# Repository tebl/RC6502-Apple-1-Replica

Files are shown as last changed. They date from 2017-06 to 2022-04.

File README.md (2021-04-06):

# RC6502 Apple 1 Replica

Since building and spending time with the excellent [RC2014](http://rc2014.co.uk) computer kit, I wanted to build another one from scratch while learning even more about them along the way. Combine that with the love of old machines I'll never be able to own, and the missing knowledge to actually do that I instead started looking for books on how things work on a more basic level.

Seems someone, Tow Owad ofcourse, wrote a book on called "Apple 1 Replica Creation, Back to the garage" on how to build an Apple 1 computer from scratch and made it freely available on [http://www.applefritter.com/](http://www.applefritter.com/). Couldn't possibly find a more perfect match, so thank you for that Tom! Only thing missing was the PCBs, so with that in mind I set about designing them in KiCAD. Before long, the RC6502 Apple 1 Replica was born.

I started designing each function as a separate module for ease of debugging, later all this was concentrated down into a computer on a single PCB. A so called Single Board Computer (SBC) to call my own, but with the ability to connect it up to a backplane of your choice (either my own, or you can use the RC2014 one) so that extra functionality can be plugged in and added as you please. The fun part is designing additions for it, so check out the various modules if there's something you'd like to add to it.

I've been documenting the build process of the various components on my blog at [https://hvetebolle.blogspot.no/p/rc6502.html](https://hvetebolle.blogspot.no/p/rc6502.html), but be warned that it's in my native language (Norwegian) so this might not be anywhere close to readable for most people. For those of you relying on English as a language, and don't want to try out Google Translate, the essence of it is that it all amounts to a fully functional Apple 1 replica computer built with the cheapest parts possible!

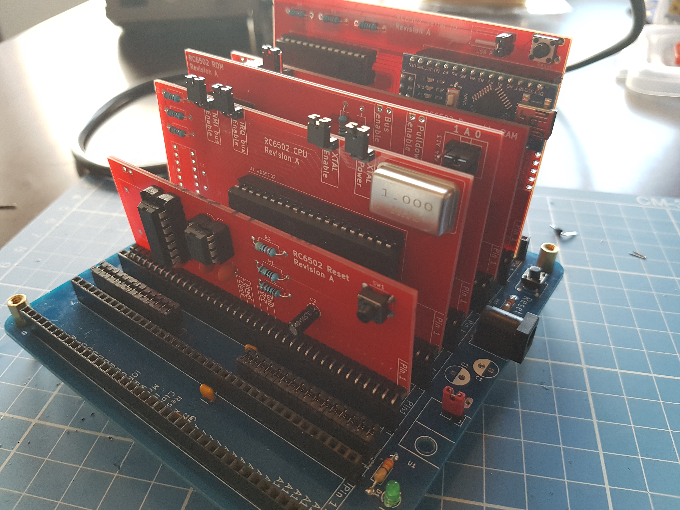
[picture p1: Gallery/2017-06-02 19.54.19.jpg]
RC6502 Computer

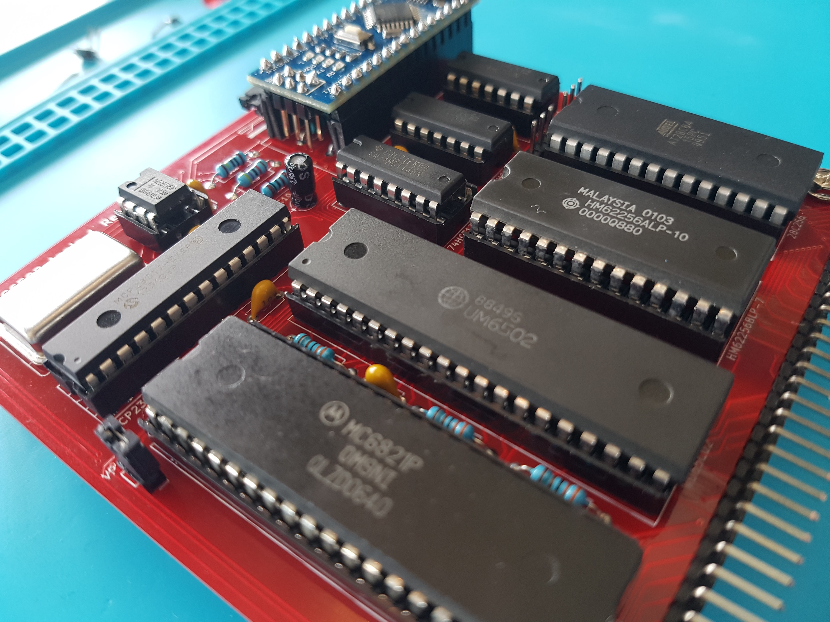
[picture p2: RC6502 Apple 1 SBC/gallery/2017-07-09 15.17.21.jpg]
RC6502 SBC Computer


## Modules
Like the RC2014 I've decided to keep things very modular with each card more or less doing one simple thing, easier to wrap ones head around as a beginner and a lot easier to understand when troubleshooting - also a lot cheaper to upgrade or replace since you don't actually need to replace the entire thing, just the specific board. With the conversion of the RC6502 computer to a SBC-version (Single Board Computer), you now have the option to build an all in one version on a single PCB - alternatively you can build the completely full-sized version as before if you want to! Most can be accomplished with the SBC version so to start things off, I recommend getting PCBs of the SBC ([order](https://www.pcbway.com/project/shareproject/RC6502_Apple_1_SBC__revision_D_.html?inviteid=88707)) as well as the backplane ([order](https://www.pcbway.com/project/shareproject/RC6502_Apple_1_Replica__Backplane_module_revision_A_.html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)).

The full-sized system uses a 39-pin bus described in [`Bus.md`](Bus.md). The SBC supports the same bus, allowing you to use expansion cards with it; jumpers on the SBC allow you to disable any of the RAM, ROM, PIA and clock so that their functionality can be replaced by peripheral cards on the bus.

In order to build a single board computer (SBC) of RC6502 you'll need the following modules:
- [RC6502 SBC](https://github.com/tebl/RC6502/tree/master/RC6502%20Apple%201%20SBC) ([order](https://www.pcbway.com/project/shareproject/RC6502_Apple_1_SBC__revision_H_.html?inviteid=88707))

In order to build the complete full-sized RC6502 you'll need the following modules:
- [Backplane](https://github.com/tebl/RC6502-Apple-1-Replica/tree/master/RC6502%20Backplane) ([order](https://www.pcbway.com/project/shareproject/RC6502_Apple_1_Replica__Backplane_module_revision_A_.html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))
- [CPU](https://github.com/tebl/RC6502/tree/master/RC6502%20CPU)
- [RAM](https://github.com/tebl/RC6502/tree/master/RC6502%20RAM)
- [ROM](https://github.com/tebl/RC6502/tree/master/RC6502%20ROM)
- [Reset Circuit](https://github.com/tebl/RC6502/tree/master/RC6502%20Reset%20Circuit)
- [Serial IO](https://github.com/tebl/RC6502/tree/master/RC6502%20Serial%20IO)

Optional modules:
- [Backplane](https://github.com/tebl/RC6502-Apple-1-Replica/tree/master/RC6502%20Backplane) ([order](https://www.pcbway.com/project/shareproject/RC6502_Apple_1_Replica__Backplane_module_revision_A_.html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))
- [Prototyping module](https://github.com/tebl/RC6502-Apple-1-Replica/tree/master/RC6502%20Prototyping) ([order](https://www.pcbway.com/project/shareproject/RC6502_Apple_1_Replica__Module_prototyping_board_.html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))
- [Digital I/O and joystick](https://github.com/tebl/RC6502-Apple-1-Replica/tree/master/RC6502%20Joystick) ([order](https://www.pcbway.com/project/shareproject/RC6502_Apple_1_Replica__Joystick_module_revision_A_.html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))
- [RIOT 2600 (Atari 2600 RAM and digital I/O)](https://github.com/tebl/RC6502-Apple-1-Replica/tree/master/RC6502%20RIOT) ([order](https://www.pcbway.com/project/shareproject/RC6502_Apple_1_Replica__RIOT_2600_revision_A_.html?inviteid=88707))
- [VDU](https://github.com/tebl/RC6502-Apple-1-Replica/tree/master/RC6502%20VDU) ([order](https://www.pcbway.com/project/shareproject/RC6502_Apple_1_Replica__VDU_module_revision_B_.html?inviteid=88707))
- [VDU B/W Amplifier](https://github.com/tebl/RC6502-Apple-1-Replica/tree/master/RC6502%20VDU%20Amplifier) ([order](https://www.pcbway.com/project/shareproject/RC6502_Apple_1_Replica__VDU_B_W_Amplifier_revision_A_.html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))
- [VDU Color Amplifier](https://github.com/tebl/RC6502-Apple-1-Replica/tree/master/RC6502%20VDU%20Color%20Amplifier) ([order](https://www.pcbway.com/project/shareproject/RC6502_Apple_1_Replica__VDU_Color_Amplifier_revision_A_.html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))

If you would like to have a copy of one or more modules, what you'll need to do is zip up the contents of the export directory for each module and give that to your favourite PCB fabrication plant. Personally I prefer to use [PCBWay](https://www.pcbway.com/setinvite.aspx?inviteid=88707), each module is only 5$ each and new accounts even get the first one free! Please use the supplied link when signing up to help me support this project, I'll get a small discount on future orders and hopefully I can afford to keep developing new and exciting modules. Some of the modules also have an order-link, using this you won't have to deal with the rather daunting PCB fabrication order forms so you know it'll work on the first order attempt!

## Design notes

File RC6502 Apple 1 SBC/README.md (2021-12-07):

# RC6502 Apple 1 SBC

Did you ever wonder what the first computer created by Apple was like, and then checked what getting one might cost? Well, only a few were made and those that still exist probably would cost you more than my car! Steve Wozniak built what would later be called the Apple I computer in his garage, using only common over the counter components the result was an interesting computer that still holds the imagination of many computer geeks to this day. I don't own a garage so I was limited by whatever I could do from the confines of my kitchen table, the RC6502 was what I came up with and with the files freely available on GitHub you can too!

There are two versions of the RC6502, one has a card for every basic function such as CPU, RAM (redesigned version of also supports ROM), separate ROM as well as a serial card that replaces the traditional CRT and ASCII keyboard with an Arduino Nano. Doing it this way requires a backplane to connect everything together, this may be the version to build either because you want to study each of them in detail to figure out their secrets or simply because you want the option to easily replace them. The other one, this one actually, is the SBC-version (Single Board Computer) - this is the version to get if you want to learn a bit about the computer and enjoy building kits that are in a more compact form factor. It looks nice on shelf, or in a small drawer (if you don't get a vote on what belongs on display in your home). Most can be accomplished with the SBC version, so for your first build I recommend that you start with the SBC ([order](https://www.pcbway.com/project/shareproject/RC6502_Apple_1_SBC__revision_D_.html?inviteid=88707)) as well as a backplane ([order](https://www.pcbway.com/project/shareproject/RC6502_Apple_1_Replica__Backplane_module_revision_A_.html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)) (so you can create and add features later).

Completed board

Excited yet? Of course you are. The next step is getting a PCB made; with the files available here you can have a company such as [PCBWay](https://www.pcbway.com/project/shareproject/RC6502_Apple_1_SBC__revision_D_.html?inviteid=88707) make a stack of them for around $5, then have a look through the BOM (Bill Of Manufacturing) below to figure out what kind of components you'd need later to put it all together. Other than that you need basic tools such as a good soldering iron with a small-ish tip, lead-based solder with a resin core is recommended for beginners and then finally you'll need a basic EEPROM programmer (I use a cheap, but fantastic one called MiniPro TL866A).

The project uses only through-hole components that are easy for beginners, these have a set of pins or wires that are threaded through the holes of the PCB and then soldered on to the backside of the PCB. You can assemble it in the order of your own choosing as long as everything goes in the right place, but here are some hints to get started: do smaller parts such as the resistors first, then followed by the capacitors, IC sockets and then finally the larger components. By doing it this way, we're gradually going from the components closest to the board and successively moving onto taller components - this makes it easier to keep everything flush with the board. The components icons on the top of the PCB, what we hardware geeks usually refer to as the silkscreen, shows you which components goes where - take care that they are oriented the correct way, where it matters it'll be marked. Sockets will have a little indent marked on it similar to what you find on the PCB, for the electrolytic capacitors (round towers) you'll be able to match a stripe on one of the sides to the filled half of the symbol (this is the minus side).

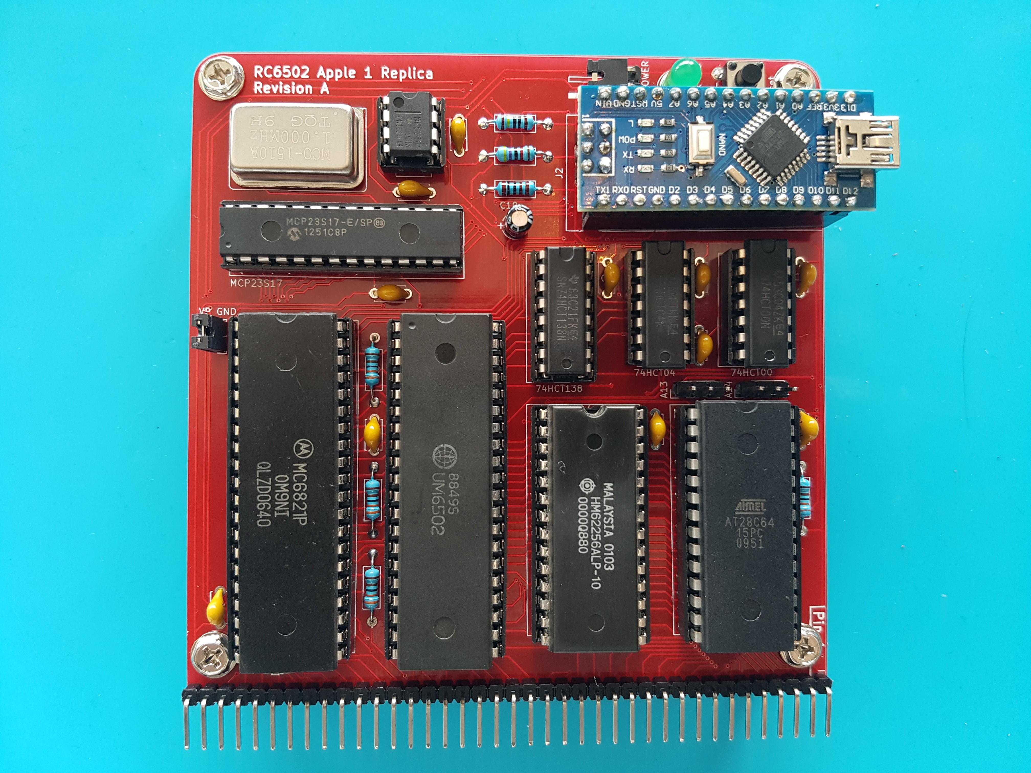
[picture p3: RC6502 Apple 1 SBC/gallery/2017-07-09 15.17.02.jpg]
Board overview


Take it slow and steady, enjoy the feeling of building a computer by hand. Study the text on the backside of the PCB as you go along, it'll have some text on it describing what most of the components you are installing actually does! If afterwards you want to study everything in detail, you can do so by studying the schematic for the whole thing at your leisure. Having problems with it? Now, I'm afraid you no longer have the option to avoid the schematic, but happily most problems can be fixed by verifying each connection by using a cheap multimeter set to continuity mode. If you print the schematic, you can mark everything you've checked with a pen so you won't overlook anything - this is where you'll be learning the most! Sometimes the wrong things have been accidentally connected, usually by a stray splash of solder - these are quickly found using the same continuity check, systematically work through each of the ICs to see if pins next to each other have been connected without a corresponding link on the schematic. Don't feel bad that everything didn't work from the get go, that just means you got some extra opportunities to learn even more than expected!

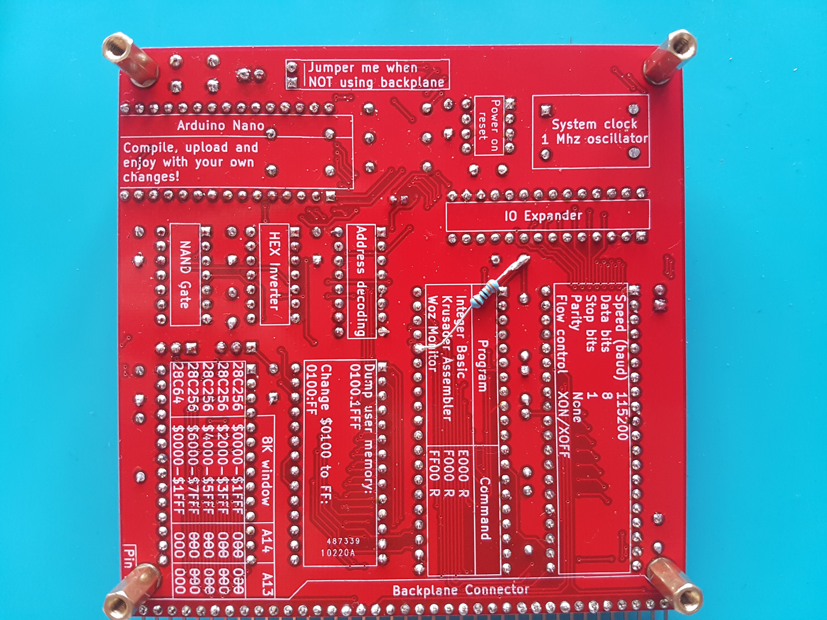
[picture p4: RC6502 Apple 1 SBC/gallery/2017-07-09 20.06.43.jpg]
Reverse side of board


The original computer had circuits for displaying data on a screen and reading input via a physical keyboard, but to keep things simple we are instead using an Arduino Nano to replace these parts - that way, you thankfully don't need to buy an antique keyboard or a scary CRT monitor in order to use it! You can communicate with the computer you built using a terminal emulator program such as PuTTy, SecureCRT or similar over the serial interface provided by the Arduino Nano. The Nano of course also need some software running on it, you'll find that in the form of an Arduino sketch called "[PIA Communicator](https://github.com/tebl/RC6502/tree/master/RC6502%20Serial%20IO/pia_communicator)", for more information see the details for the standalone [Serial IO](https://github.com/tebl/RC6502-Apple-1-Replica/tree/master/RC6502%20Serial%20IO)-module. 

The firmware that goes into the EEPROM hasn't been changed since Wozniak himself wrote it, but as long as you have the programmer handy you can easily flash it into place using the software that came with the programmer (MiniPro Programmer, if you bought the one I'm using). Today the [8 KB binary file](https://github.com/tebl/RC6502/tree/master/RC6502%20ROM/firmware) will seem really small, but even still it contains everything you'll need to get started and even a lot more. You've got a complete version of BASIC in there, but since it's an Apple 1 the first thing you'll see is something called a computer monitor - WozMon! The monitor allows you to interact with the system by peeking and poking memory locations to your hearts content!

At this point you'll certainly have learned a lot, after all you've actually built an entire computer! Thankfully you had some modern tools available, but please take a moment to contemplate the genius needed to build this thing back in 1976! Still wanting more, why not try your hand at designing some extra modules to use with that backplane connector? Add a parallel port, replace the display portion with a proper LCD, or you could even go as far as adding a few pretty blinking lights - the possibilities are truly endless (so long as it's within 64K)!

## Errata
Revisions D and E of the SBC was missing a line powering the CPU, this is fixed by adding a piece of patch wire or simply a piece of resistor leftovers. Refer to the image below to see where it should be added, but leave some room so that it doesn't short to the pads now in the middle of the wire.

Adding wire

# Schematic
The supplied KiCad files should be sufficient as both a schematic and as a starting point for ordering PCBs (basically you could just zip the contents of the export folder and upload that on a fabrication site), the schematic is also available in [PDF-format](https://github.com/tebl/RC6502/raw/master/RC6502%20Apple%201%20SBC/export/RC6502%20Apple%201%20SBC.pdf) so that you can refer to it while troubleshooting. You could even print it out and hang it on your office wall, excellent conversation starter at any technology-oriented business worth working at!

# BOM
This is the part list as it stands now, most should be easy to get a hold of from your local electronic component shop though you might have to consider other sources for the older parts such as CPU, memory and PIA. Personally I bought most components with free shipping from China via AliExpress, prices will vary though you should be able to find most components in larger quantities than you'll ever need for the cost of a few cups of fancy coffee! You don't even need the newest and fastest components, after all it's going into a 70s-era computer so don't go overboard unless you absolutely want to (you can replace 74LS ICs with 74HCT or 74ALS if you want something newer). Most components have been produced by various manufacturers, these mostly do the same thing without any relevant differences though the choice of CPU and PIA could lead to incompatibilities so I've specified the ones I've had success with (probably also the cheapest ones available).

Some vendors will have the same ICs in different form factors, the ones you want will often be specified as being in the form of a DIP/PDIP package. Usually you'll want sockets for each of the ICs as well, a bag of assorted sockets should be easily available without setting you back more than a couple bucks. With the sockets in place, you don't need to dread having to remove an IC later, this leads to easier fault finding and you can easily "borrow"  them for other projects later! For the pin headers, both male and female - if you can't find the exact pin count, just buy the longer versions and snip off the parts you don't need. Electrolytic capacitors have a max voltage rating, the cheapest are 16V and should be more than enough - you can use higher rated components if you want to, but note that these might be slightly bigger thought you'll probably be able to fit in there anyway. Personally I prefer the look of the monolithic capacitors over the regular ceramic ones, but either is fine!

| Reference | Silkscreen | Item | Count | Socket (optional) |
|---|---|---|---|---|
| PCB | Single Board Computer rev H | Fabricate yourself using Gerber files ([order](https://www.pcbway.com/project/shareproject/RC6502_Apple_1_SBC__revision_H_.html?inviteid=88707)) | 1 |  |
| U1 | CPU | 6502 CPU DIP-40, UM6502 or SY6502 | 1 | DIP40W |
| U2 | RAM | 62256 Static RAM DIP-28 | 1 | DIP28W |
| U3 | address decoding | 74LS138 DIP | 1 | DIP16N |
| U4 | ROM | 28C64 or 28C256 DIP-28, EEPROM | 1 | DIP28W |
| U5 | NAND gates | 74LS00 DIP | 1 | DIP14N |
| U7 | Hex inverter | 74LS04 DIP | 1 | DIP14N |
| U8 | like GPIO | MC6821P PIA DIP-40 | 1 | DIP40W |
| U9 | Arduino I/O expander | MCP23S17 DIP-28 | 1 | DIP28N |
| X1 | system clock | 1.000Mhz TTL Oscillator, (DIP 14) | 1 | OSC-4W-fullsize |
| R1,R6-R8,R10 |  | 3k3 (3300) ohm resistor | 5 |  |
| R2 |  | 1M ohm resistor | 1 |  |
| R3 |  | 47k ohm resistor | 1 |  |
| R4 |  | 1k ohm resistor | 1 |  |
| R5 |  | 330 ohm resistor | 1 |  |
| R9 |  | 10k ohm resistor | 1 |  |
| D1 | "POWER" light | 5mm LED diode, green or red color | 1 |  |
| J1, JP1 | VP GND, OSC_EN | Single row, 2p straight header | 2 |  |
| J8 | USB POWER (to SBC from Nano) | Single row, 2p right angle connector | 1 |  |
| J2 | Arduino Nano socket | 15p female pin headers | 2 |  |
| J3 | (to backplane) | Single row, 39p right angle connector | 1 (optional) |  |
| J4-J7 | (optional standoffs in each corner) | Not needed, holes included with PCB | 4 |  |
| J9–J11, A13_W–A14_W | ROM/RAM/PIA_EN, A13/A14 | Single row, 3p straight header | 5 |  |
| C1-C9, C11 |  | 100nF ceramic capacitor | 10 |  |
| C10 |  | 10uF 16V electrolytic capacitor | 1 |  |
| C12 |  | 10nF ceramic capacitor | 1 |  |
| SW1 | RESET | Momentary push button | 1 |  |
|  |  | Jumpers for settings (CAP headers) | up to 8 (depending on configuration) |  |
| Nano (J2) |  | Arduino Nano v3.0 with USB cable | 1 |  |

If you would like to have a copy of one or more modules, what you'll need to do is zip up the contents of the export directory for each module and give that to your favourite PCB fabrication plant. Personally I prefer to use [PCBWay](https://www.pcbway.com/setinvite.aspx?inviteid=88707), each module is only 5$ each and new accounts even get the first one free! Please use the supplied link when signing up to help me support this project, I'll get a small discount on future orders and hopefully I can afford to keep developing new and exciting modules. Some of the modules also have an order-link, using this you won't have to deal with the rather daunting PCB fabrication order forms so you know it'll work on the first order attempt!

Jumper Settings
===============

Revision F+ board jumpers are marked on the back of the board with a
box around the pins that enable.

- `USB_POWER`
  - Shorted: power the SBC from USB supply to Arduino Nano (see below)
  - Open: take power from `VCC` line of backplane connector, recommended with expansions

- `OSC_EN`
  - Shorted: Use onboard clock. This connects pin 8 (OUT) of the
    oscillator to the `CLOCK` line.
  - Open: Use external clock, usually supplied to the `CLOCK` pin of
    the expansion bus connector.

- `VP GND`
  - Shorted: Original MOS 6502, UM6502, SY6502, R65C02. Connects pin 1 of the
    CPU to ground, providing an additional ground connection for the CPU.
  - Open: WD65C02 CPU. Leaves pin 1 of the CPU (`V̅P̅` on the WD65C02) floating.

- `PIA_EN`
  - Top pair shorted: Enable PIA. Connects `CS1` to Vcc.
  - Bottom pair shorted: Disable PIA. Connects `CS1` to ground.

- `RAM_EN`
  - Left or upper pair shorted: Enable RAM. Connects RAM `C̅S̅`/`O̅E̅` to address
    decoding logic (`CS_RAM`).
  - Right or lower pair shorted: Disable RAM. Connects RAM `C̅S̅`/`O̅E̅` to Vcc.

- `ROM_EN`
  - Top pair shorted: Enable ROM. Connects ROM `C̅E̅`/`O̅E̅` to address
    decoding logic (`CS_ROM`).
  - Bottom pair shorted: Enable ROM. Connects ROM `C̅E̅`/`O̅E̅` to Vcc.

- `A14_W`, `A13_W`
  - Right pair shorted: `A14`/`A13` address line pulled low.
  - Left pair shorted: `A14`/`A13` address line pulled high.
  - For 8K×8 AT28C64 EEPROM, use no jumpers (short nothing).
  - For 8K×32 AT28C256 EEPROM, program the lowest 8 KB bank and
    short the right-hand pair of both `A14_W` and `A13_W`.

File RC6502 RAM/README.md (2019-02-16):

# RC6502 RAM

The original Apple 1 computer only came with 8KB of RAM (Random Access Memory), this was divided into two separate 4KB blocks and should match the following layout (picture from Tom Owads Apple 1 Replica book):

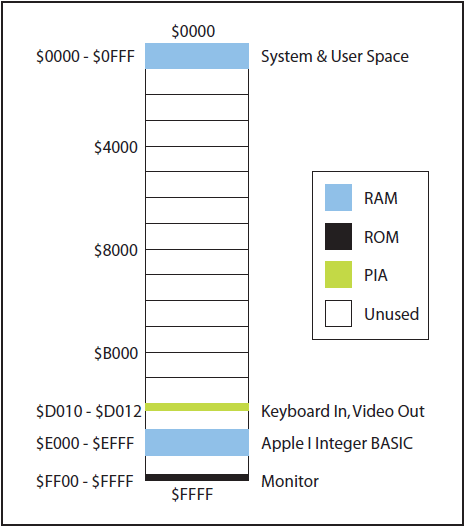
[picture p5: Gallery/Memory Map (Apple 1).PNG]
Apple 1 Memory Map


The RC6502 computer makes the same changes to the hardware dealing with RAM as was details in the previously mentioned book, the updated memory map should now match the one included below (note that any optional modules are not included here). The blue areas designating RAM have shifted positions, mostly we've moved the area usually used for Integer Basic into ROM (see the [ROM](https://github.com/tebl/RC6502/tree/master/RC6502%20ROM)-module for more information). The initial version of the RAM module simply split the 64K memory space supported by the 6502 processor into two, the lower 32K being dedicated to RAM giving us the following memory layout:

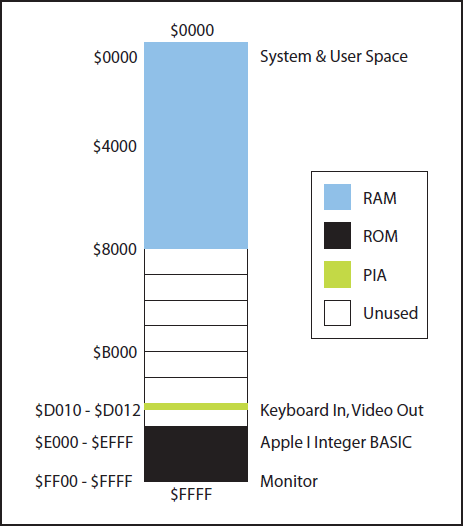
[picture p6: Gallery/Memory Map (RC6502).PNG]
RC6502 Memory Map


The newly redesigned RAM module now also support ROM ICs, this can be done by jumpering WE across pins 2-3 to disable the write signal usually sent to the chip. The previous scheme of splitting the memory space into two 32K sections has been kept, the HI/LO jumper is used as to select adressing segments between $0000 through $7FFF or alternatively $8000 through $FFFF. Each 4KB section within the selected 32KB segment can then be enabled/disabled using the corresponding jumpers, this way a single board can be active within memory segments of sizes from 4KB to 32KB.

When used in combination with (E)EPROMs smaller than 32KB, such as the 27C64 or 28C64 you need to leave A13_EN and A14_EN unjumpered since those pins would be designated NC (No Connect) on the ICs themselves. Note that since ICs of this size are usually 8KB you'd only have two 4KB blocks available, enabling these in the certain combinations would lead to repetitions within the memory space. 32KB ROM chips are more than likely cheaper to obtain anyway, meaning that this would be a nice way to add more ROM-based software to the computer without much added complexity.

# Schematic
The supplied KiCad files should be sufficient as both a schematic and as a starting
point for ordering PCBs, the schematic is also available in
[PDF-format](https://github.com/tebl/RC6502-Apple-1-Replica/blob/master/RC6502%20RAM/export/RC6502%20RAM.pdf). You can refer to the BOM below for a list of suggested components to use, part numbers in parenthesis are optional and is not required.

# BOM
These are the components needed to put together your very own RAM-module for the RC6502 computer, should be able to get all of this from your favourite parts supplier through your favourite local parts supplier. For the pin headers, both male and female - if you can't find the exact pin count, just buy the longer versions and snip/cut off the parts you don't need (get extra in case of accidents, and don't cut yourself either!). Part counts in parenthesis are to be considered optional, so if you don't have any plans for them - then they can probably be left out until you need them.

| Reference | Item | Count  |
| --- | --- | --- |
| PCB | Fabricate yourself using KiCad files  | 1  |
| C1-C5 | 100nF ceramic capacitor | 5  |
| J3 | 1x39 right angle pin header, male | 1  |
| JP1-JP2 | 1x2 straight pin header, male | 2  |
| JP3-JP13  | 1x3 straight pin header, male | 10  |
| U1 | 62256 SRAM or 28C256, both DIP-28 | 1  |
| U2 | 74LS138 DIP | 1  |
| U3-U4 | 74LS08 DIP | 2  |
| U5 | 74LS00 DIP | 1  |
| | Jumper caps | 3 (10) |

If you would like to have a copy of one or more modules, what you'll need to do is zip up the contents of the export directory for each module and give that to your favourite PCB fabrication plant. Personally I prefer to use [PCBWay](https://www.pcbway.com/setinvite.aspx?inviteid=88707), each module has been designed to fit inside the 5$ dimensions. Use the link provided when signing up to support this project!

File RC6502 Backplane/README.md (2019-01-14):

# RC6502 Backplane

The RC6502 backplane allows two or more module to communicate via the same data and signal busses - you need this when building the modular version of the RC6502 computer, but although it's a recommended purchase you can do without for the SBC-version. Quite possibly you could put a female bacplane pin header on the SBC-board if you absolutely wanted to, but then you'd get a wierd L-shaped computer so maybe not - or use those expensive extra length ones to stack them vertically.

Additionally this supports using an external power supply, but make sure to remove the jumpers on the SBC/Serial IO card so that you don't attempt to power it from the Arduino Nano at the same time. Don't know what'll happen, but can't imagine it'll be anything good. If using a proper regulated 5v supply you can install a wire across JP1 and then skip installing the 7805 and associated components, but a proper regulated supply might be a bit more expensive to get a hold of so depending on the quality it may preferred to use the 7805 in combination with a 9-12v power supply instead.

The backplane, like all of my modules has been designed to fit within the 5$ pricerange for PCBs so it only has space for 39 pins per slot like the modules themselves. You can't actually get 39-pin female pin-headers, so feel free to either allow the 40th pin to hang across the edge or just cut it off - either way, use a pair of pliers to pull the pin out from the bottom.

# Schematic
The supplied KiCad files should be sufficient as both a schematic and as a starting
point for ordering PCBs, the schematic is also available in
[PDF-format](https://github.com/tebl/RC6502-Apple-1-Replica/raw/master/RC6502%20Backplane/export/RC6502%20Backplane.pdf). You can refer to the BOM below for a list of suggested components to use, part numbers in parenthesis are optional and is not required.

# BOM
These are the components needed to put together your very own Backplane-module for the RC6502 computer, all of which you should be able to get from your favourite parts supplier through your favourite electronic parts supplier. 39-pin female pin-headers for slots don't exist, so as previously mentioned you should just snip/cut off the parts you don't need. Part counts in parenthesis are to be considered optional so feel free to leave them out if you don't have any specific plans for them.

| Reference | Item | Count |
| --- | --- | --- |
| PCB | Fabricate yourself using KiCad files ([order](https://www.pcbway.com/project/shareproject/RC6502_Apple_1_Replica__Backplane_module_revision_A_.html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))| 1  |
| J1,J3-J6  | 1x39 straight pin header, female | 5  |
| JP1 | Solder wire, when not intalling U1 | (1) |
| J2 | 3 pin DC barrel connector | (1) |
| C1 | 100uF 16V electrolytic capacitor | (1) |
| C2 | 10uF 16V electrolytic capacitor | (1) |
| C3 | 100nF ceramic capacitor | (1) |
| C4-C8 | 100nF ceramic capacitor | 5  |
| U1 | LM7805 (TO-220) | (1) |

If you would like to have a copy of one or more modules, what you'll need to do is zip up the contents of the export directory for each module and give that to your favourite PCB fabrication plant. Personally I prefer to use [PCBWay](https://www.pcbway.com/setinvite.aspx?inviteid=88707), each module has been designed to fit inside the 5$ dimensions. Use the link provided when signing up to support this project, you can also use the [order](https://www.pcbway.com/project/shareproject/RC6502_Apple_1_SBC__revision_D_.html?inviteid=88707) link directly to skip some of the order forms!

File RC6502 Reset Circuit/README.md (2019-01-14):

# RC6502 Reset Circuit

Funny story, the original Apple 1 computer did not have a power-on reset circuit! While this was actually quite common for computers from that time, it meant that the circuitry would often start up in an unknown state... fancy way of saying that internal CPU registers and memory would be filled with seemingly random date. The user would then have to manually push the reset button, this worked most of the time... Why? Because the 6502 is a particularly special little CPU that, it has very specific timing requirements for all of this to work properly. So I took a book from the Commodore 64 manual and used that, no need to reinvent wheels already invented by other far more [gifted people](https://www.grappendorf.net/projects/6502-home-computer/reset-circuit.html)!

In addition to power-on reset and normal reset functionality, this module also takes care of handling the system clock by including a footprint for a 5v TTL crystal oscillator. While you can use a standard 1Mhz oscillator, there are 2Mhz capable CPUs normally labelled 6502A so in many ways it make sense to install a 2Mhz oscillator and then jumper J2 for a /2 (pins 5-6) clock division for standard 1Mhz CPUs. Jumper positions 3-4 if installing 1Mhz oscillator. Note that the [CPU](https://github.com/tebl/RC6502/tree/master/RC6502%20CPU)-module also includes a footprint for an oscillator, disable that and then jumper J2 pins 1-2 to enable the one on this board. If you have plans of using several CPU boards with varying speeds so that you can easily swap between them, then it would make sense to only use the oscillators installed on the CPU module themselves.

Picture below shows the first revision of the board, note that this does not include the functionality for setting up a clock divider.

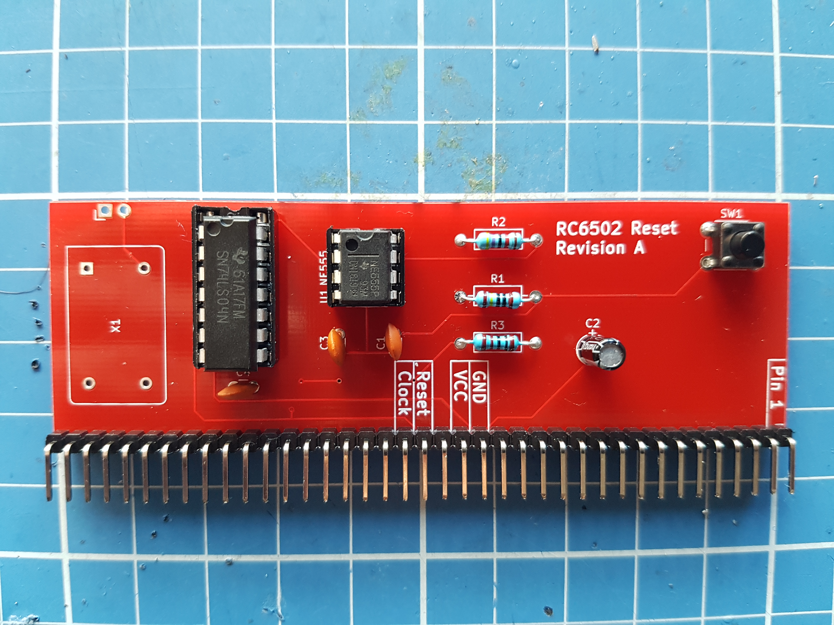
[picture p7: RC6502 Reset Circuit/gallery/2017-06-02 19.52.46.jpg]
Wired up


# Schematic
The supplied KiCad files should be sufficient as both a schematic and as a starting
point for ordering PCBs, the schematic is also available in
[PDF-format](https://github.com/tebl/RC6502-Apple-1-Replica/tree/master/RC6502%20Reset%20Circuit). You can refer to the BOM below for a list of suggested components to use, part numbers in parenthesis are optional and is not required.

# BOM
These are the components needed to put together your very own Reset Circuit-module for the RC6502 computer, all of which you should be able to get from your favourite parts supplier through your favourite electronic parts supplier though the oscillator TTL oscillator might require a well-stocked one. For the pin headers, both male and female - if you can't find the exact pin count, just buy the longer versions and snip/cut off the parts you don't need (get extra in case of accidents, and don't cut yourself either!). As previously mentioned, part counts in parenthesis are to be considered optional so feel free to leave them out if you don't have any specific plans for them.

| Reference | Item | Count |
| --- | --- | --- |
| PCB | Fabricate yourself using KiCad files  | 1  |
| C1,C3-C5  | 100nF ceramic capacitor | 4  |
| C2 | 10uF 16V electrolytic capacitor | 1  |
| D1 | 5mm LED diode, green or red color | 1  |
| J1 | 1x39 right angle pin header, male | 1  |
| J2 | 2x4 straight pin header, male | 3  |
| R1 | 1M ohm resistor | 1  |
| R2 | 47k ohm resistor | 1  |
| R3 | 1k ohm resistor | 1  |
| R4 | 330 ohm resistor | 1  |
| SW1 | Momentary push button | 1  |
| U1 | NE555 DIP | 1  |
| U2 | 74LS04 DIP | 1  |
| U3 | 74LS74 DIP | (1) |
| X1 | 1.000Mhz TTL Oscillator, (DIP 14) | (1) |
| | Jumper caps | 2  |

If you would like to have a copy of one or more modules, what you'll need to do is zip up the contents of the export directory for each module and give that to your favourite PCB fabrication plant. Personally I prefer to use [PCBWay](https://www.pcbway.com/setinvite.aspx?inviteid=88707), each module has been designed to fit inside the 5$ dimensions. Use the link provided when signing up to support this project!

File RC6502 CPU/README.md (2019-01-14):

# RC6502 CPU

Ah... The CPU-module (Central Processing Unit), definitely the brains of the operation! While the original sported an MOS-branded, the same company later bought out by Commodore and adapter for their computers, ceramic 6502 CPU the later clones available to us now haven't changed all that much. For that reason you can easily substitute the MOS-part with an easily obtainable UM6502 or an SY6502 without any changes, the newer and substantially changed W65C02 however remains incompatible at the moment.

The original computer ran at a blazing 1Mhz, but if you can find a 6502A you could probably crank this computer all the way up to 2Mhz! The speed the computer would run at (successfully or not) will be determined by the crystal oscillator, while it can be mounted onto the CPU-module and enabled by jumpering JP1/JP2 the logical place for this in a more modern configuration would be on the [Reset circuit](https://github.com/tebl/RC6502-Apple-1-Replica/tree/master/RC6502%20Reset%20Circuit)-module. The reason for including it here is simply that the original Apple 1 computer didn't have a power-on reset circuitry, but seriously - get one! If you have plans for building more than one CPU boards with varying speeds, it would make sense to keep these together on the same board so that you can easily swap between them.

Revision A of the board is shown below, the newer revisions have a more simplified design due to a separate RD-signal being dropped from later designs. This was originally intended to help compatibility with the RC2014 computer, but this idea was abandoned due to the required increase in complexity in order to support a handfull of builds.

Wired up

# Schematic
The supplied KiCad files should be sufficient as both a schematic and as a starting
point for ordering PCBs, the schematic is also available in
[PDF-format](https://github.com/tebl/RC6502-Apple-1-Replica/raw/master/RC6502%20CPU/export/RC6502%20CPU.pdf). You can refer to the BOM below for a list of suggested components to use, part numbers in parenthesis are optional and is not required.

# BOM
These are the components needed to put together your very own ROM-module for the RC6502 computer, should be able to get all of this from your favourite parts supplier through your favourite local parts supplier. For the pin headers, both male and female - if you can't find the exact pin count, just buy the longer versions and snip/cut off the parts you don't need (get extra in case of accidents, and don't cut yourself either!). As previously mentioned, part counts in parenthesis are to be considered optional so feel free to leave them out if you don't have any specific plans for them.

| Reference | Item | Count  |
| --- | --- | --- |
| PCB | Fabricate yourself using KiCad files  | 1  |
| U1 | 6502 CPU DIP-40, UM6502 or SY6502 | 1  |
| J1 | 1x39 right angle pin header, male | 1  |
| J2-J4 | 1x2 right angle pin header, male | 3  |
| JP1,JP2 | 1x2 right angle pin header, male | (2)  |
| R1-R3 | 3K3 (3300) Ohm resistor | 3  |
| C1 | 100nF ceramic capacitor | 1  |
| X1 | 1.000Mhz TTL Oscillator, (DIP 14) | (1) |
| | Jumper caps | (5) |

If you would like to have a copy of one or more modules, what you'll need to do is zip up the contents of the export directory for each module and give that to your favourite PCB fabrication plant. Personally I prefer to use [PCBWay](https://www.pcbway.com/setinvite.aspx?inviteid=88707), each module has been designed to fit inside the 5$ dimensions. Use the link provided when signing up to support this project!

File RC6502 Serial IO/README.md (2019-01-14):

# RC6502 Serial IO

The original Apple 1 computer had circuitry for displaying data on a monitor as well as reading input via a physical keyboard, but to keep things simple we are instead using an Arduino Nano to this! Might not be as cool without an antique keyboard or a big and scary CRT monitor connected to it, but then again those things aren't for beginners and should you feel like adding them later there no reason as to why you can't!

Via the Arduino Nano we can communicate with the computer, the one you'¨ve just built, by using your favourite terminal emulator program such as PuTTy, SecureCRT or similar over the serial interface provided by the Nano. The Nano will of course need some software running on it, you'll find that in the form of an Arduino sketch called "[PIA Communicator](https://github.com/tebl/RC6502/tree/master/RC6502%20Serial%20IO/pia_communicator)". This is a rather basic version of that is intended to get you started with something that is easy to understand, thanks however to the wonders of the Internet and collaborative forces of Github you can find a much improved version of it on [https://github.com/jblang/pia_communicator](https://github.com/jblang/pia_communicator).

The RC6502 computer, more specifically this module or the one integrated into the [SBC](https://github.com/tebl/RC6502-Apple-1-Replica/tree/master/RC6502%20Apple%201%20SBC) version of it has an IC called a PIA (Peripheral Interface Adapter) on it. The PIA has two ports and when Wozniak his original Apple 1, he dedicated one port to video output and the other to keyboard input - both of those functions we've replaced with our Nano, but to keep things original we've kept the actual PIA to keep things authentic. A 40-pin headers in addition to a couple of pull-up resistors have been added to the board so that one or both of these can be later replaced with actual hardware.

You have several options for which particular type of PIA to use, there is the MC6820, MC6821 as well as the newer W65c21 that are available. The ones I've had most luck with, and to me feels the most authentic has to be the MC6821 by Motorola - a slightly newer design than the original MC6820, but it's more abundantly available for purchase while still featured in most older computer design books so that is the one I prefer to use.

The serial module works by replacing all of this so that characters are transferred using the serial communications functionality on an Arduino Nano board. To make things easier when communicating with parallell devices using a Nano, I've added an IO-expander in the form of the SPI-based MCP23S17 (see [Githup Repository](https://github.com/MajenkoLibraries/MCP23S17) for the library needed).

Wired up

# Schematic
The supplied KiCad files should be sufficient as both a schematic and as a starting
point for ordering PCBs, the schematic is also available in
[PDF-format](https://github.com/tebl/RC6502/raw/master/RC6502%20Serial%20IO/export/RC6502%20Serial%20IO.pdf). You can refer to the BOM below for a list of suggested components to use, part numbers in parenthesis are optional and is not required.

# BOM
These are the components needed to put together your very own Serial IO-module for the RC6502 computer, should be able to get most from your favourite parts supplier though the older PIAs I had to purchase via AliExpress/ebay since they aren't stocked anymore by the other monopolies (atleast where I live). For the pin headers, both male and female - if you can't find the exact pin count, just buy the longer versions and snip/cut off the parts you don't need (get extra in case of accidents, and don't cut yourself either!). As previously mentioned, part counts in parenthesis are to be considered optional so feel free to leave them out if you don't have any specific plans for them.

| Reference | Item | Count  |
| --- | --- | --- |
| PCB | Fabricate yourself using KiCad files  | 1  |
| U1 | 74LS04 | 1  |
| U2 | MC6821 PIA | 1  |
| U3 | 74LS138 | 1  |
| C1-C3 | 100nF ceramic capacitor | 3  |
| C4 | 10nF ceramic capacitor | 1  |
| R1-R5 | Resistor, 10K (R1,R4 optional) |  3 (2) |
| J1 | 1x39 right angle pin header, male | 1  |
| J2 | Arduino pin headers, 1x15 pin header  | 2  |
| J3 | 1x5 right angle pin header, male | (1) |
| J4 | 2x20 pin header, male | (1) |
| JP1 | 1x2 right angle pin header, male | 1  |
| SW1 | PCB momentary push button | 1  |
| Nano | Arduino Nano with data cable | 1  |

If you would like to have a copy of one or more modules, what you'll need to do is zip up the contents of the export directory for each module and give that to your favourite PCB fabrication plant. Personally I prefer to use [PCBWay](https://www.pcbway.com/setinvite.aspx?inviteid=88707), each module has been designed to fit inside the 5$ dimensions. Use the link provided when signing up to support this project!

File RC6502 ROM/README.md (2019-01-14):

# RC6502 ROM

The original Apple 1 computer only came with 256 bytes of ROM (Read Only Memory), the bulk of this taken up by the included machine monitor later dubbed WozMon. The machine monitor in itself was written by Wozniak himself by manually entering the data corresponding to the various 6502 instructions and operands byte by byte, mainly because he did not have a computer and the software available to even write assembly level code! An amazing performance by todays standards, though not entirely unheard of in those days since most software was only available for equipment most couldn't even get access to. The Apple 1 was often used with a BASIC variant called "Integer Basic" as a programming language and means of interacting with the machine, but that originally had to be loaded into RAM first via input devices such as tape. The computers original memory map originally looked like the following (picture from Tom Owads Apple 1 Replica book):

Apple 1 Memory Map

The RC6502 computer makes the same changes to the hardware dealing with ROM as was details in the previously mentioned book, the updated memory map looks identical to the one included below (note that any optional modules are not included here). While we initially can see that the blue areas have shifted, this is RAM and we now have an entire 32KB of it as compared to the original - originally we had two blocks of 4KB positioned at the start and at $E000. The modified map changes this second block into ROM, meaning that BASIC is always available to the user, even leaving enough space for at few more utilities!

RC6502 Memory Map

The implementation of the ROM module answers to addresses from $E000 to $FFFF, in other words the last 8KB of the 6502s 64KB total addressable memory space. The onboard socket takes an EPROM/EEPROM with sizes from 64Kb (27C64/28C64) to 256Kb (27C256/28C256), the latter size giving you the option of using up to four switchable combinations (using A13/14 jumpers). When using the smaller size, these two jumpers should be left unjumpered as the corresponding address pins whould be designated NC (No Connect) on the chips themselves!

**NB!** Note that the redesigned RAM module now supports ROM chips on the same card, so if you do not intend to use the optional paging feature you may want to consider using the new RAM module instead (normally you'd get 5-10 per order anyway)! Note that this might come at an increased cost since the new RAM module requires more ICs to function, but these should be cheap as chips (the potato kind) anyway!

## Optional feature
The board enables the use of backplane pin number 39 for paging purposes, this in essence means the ability to shut of the ROM module using appropriate hardware for controlling this pin. This would enable the computer to regain this section of memory space for other purposes afterwards, possibly by switching it out for more RAM... In most cases this will not be needed, so instead I encourage you to solder a hard links between pads 2 and 3 on JP5 - U2 can also be left off the board.

## Software
As previously mentioned, the supplied binary file (in the [firmware](https://github.com/tebl/RC6502-Apple-1-Replica/tree/master/RC6502%20ROM/firmware)-directory) includes around 8KB of software. The easiest way to get that software onto the selected ROM IC is by using an EPROM programmer, personally I use the MiniPro TL866A and while cheap compared to the alternatives I've found it handles just about anything I've thrown at it.

The following overview is also printed on the back of the SBC silkscreen, while not inherently clear is that the command given is what you would type into the machine monitor program (WozMon) to start the program at the given address. From using the computer and reading the books from the corresponding era you'll want to be spending a lot of your time in BASIC, but when debugging hardware I find WozMon to be the easiest environment to work within. A somewhat detailed guide to the computer can be found by reading the original [operation manual](https://archive.org/details/Apple1Manual1976) from 1976, but the is also a really good guide for the monitor on [https://www.sbprojects.net/projects/apple1/wozmon.php](https://www.sbprojects.net/projects/apple1/wozmon.php).

| Program | Command |
|---|---|
| Integer Basic | $E000 R |
| Krusader Assembler | $F000 R |
| WozMon | $FF00 R |

# Schematic
The supplied KiCad files should be sufficient as both a schematic and as a starting
point for ordering PCBs, the schematic is also available in
[PDF-format](https://github.com/tebl/RC6502-Apple-1-Replica/raw/master/RC6502%20ROM/export/RC6502%20ROM.pdf). You can refer to the BOM below for a list of suggested components to use, part numbers in parenthesis are optional and is not required.

# BOM
These are the components needed to put together your very own ROM-module for the RC6502 computer, should be able to get all of this from your favourite parts supplier through your favourite local parts supplier. For the pin headers, both male and female - if you can't find the exact pin count, just buy the longer versions and snip/cut off the parts you don't need (get extra in case of accidents, and don't cut yourself either!). Part counts in parenthesis are to be considered optional, so if you don't have any plans for them - then they can probably be left out until you need them.

| Reference | Item | Count  |
| --- | --- | --- |
| PCB | Fabricate yourself using KiCad files  | 1  |
| U1 | 27C64, 28C64, 27C256 or 28C256 | 1  |
| U2 | 74LS00 DIP | 1  |
| U3 | 74LS00 DIP | (1)  |
| C1-C3 | 100nF ceramic capacitor | 3  |
| R1 | 10K Ohm resistor | (1)  |
| J1 | 1x39 right angle pin header, male | 1  |
| JP1,JP3 | 1x3 straight pin header, male | 2  |
| JP3,JP4 | 1x3 straight pin header, male | (2)  |
| JP5 | Piece of wire | 1  |
| JP1,JP3 | 1x3 straight pin header, male | 1  |
| | Jumper caps | 2 (2)  |

If you would like to have a copy of one or more modules, what you'll need to do is zip up the contents of the export directory for each module and give that to your favourite PCB fabrication plant. Personally I prefer to use [PCBWay](https://www.pcbway.com/setinvite.aspx?inviteid=88707), each module has been designed to fit inside the 5$ dimensions. Use the link provided when signing up to support this project!

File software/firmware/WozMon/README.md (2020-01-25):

# Woz Monitor
This project was originally aimed at being an Apple 1 replica, but before long I got distracted by other things and started adding a lot of things that were never present on the original machine - mostly because making them is fun! On the other hand, one shouldn't forget one's own roots - the computer is still an Apple 1 at heart and so it needs the Woz Monitor.

This has always been part of the software package, but I haven't had an attempt at doing something on the coding side of things - step 1 is then, naturally, to get a version of the code that can compile before introducting my own bugs into it all. I'm currently using [SB-Assembler 3](https://www.sbprojects.net/sbasm/index.php) as my choice of assembler, so given that the creator of that hosts a copy of assembler source files for WozMon on the same site at [Apple 1 ROMs](https://www.sbprojects.net/projects/apple1/download.php).

I'm hoping to add more functionality to the code in order to support my own cards as time goes by, but until I get that farI also noticed that someone has already made a version of the monitor that works with an ACIA (serial) called [EWoz](http://www.brielcomputers.com/phpBB3/viewtopic.php?f=9&t=197) which may be of some interest.

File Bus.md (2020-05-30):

RC6502 Bus
==========

The RC6502 system uses a 39-pin bus; the physical layout is a single
row of 0.05" square header pins on 0.1" centers. Conventionally the
boards have a male right-angle connector on one edge and these are
plugged into a [backplane] with female connectors.

The pinout is as follows. The signal directions (input or output from
the point of view of CPU and peripheral boards, respectively) are
guidelines, and a specific board might have a different direction. For
signals where both are marked `in`, both CPU and peripheral boards are
usually capable of using the signal as an input, but it's expected
that one board in the system will be generating the signal.

    Signal  Pin  CPU Periph
      Name  No.  Dir. Dir.   Notes
    --------------------------------------------------------------
       A15   1   out   in
         …  …
        A0  16   out   in
       GND  17   in    in
       Vcc  18   in    in
     Φ2out  19   in    in
    /RESET  20   in    in    Must be actively controlled by one board
      Φ0in  21   in    in
      /IRQ  22   in    in    Pull-up req'd; usually provided by CPU board
     Φ1out  23   in    in    Little used; also called EX0
       R/W̅  24   out   in
       RDY  25   in    out
      SYNC  26   out   in
        D0  27   ↔     ↔
         …  …
        D7  34   ↔     ↔
        TX  35   ?     ?
        RX  36   ?     ?
      /NMI  37   in    out   Pull-up req'd; usually provided by CPU board
         ×  38               Also known as EX1
         ×  39               Also known as EX2

Signal Use
----------

This section gives, for each group of signals:
- Additional information on how the signal is wired and/or used, where not
  obvious.
- Which boards take the signal(s) as input and/or output.
- Any special uses or behaviour by certain boards.

### GND/Vcc

Must be supplied by only one board. Only the following boards have
provision to supply power.

- [Backplane]: Provision to supply 5 V via an LM7805 regulator or directly
  from the backplane power input if JP1 is shorted.
- [SBC]: Jumper J8, when closed, supplies 5 V from the Arduino Nano board,
  which in turn is powered by the USB connection. The Nano and the SBC
  board (with NMOS parts) draw 200-250 mA. Depending on what kind of port
  the USB cable is connected to, it will usually provide a maximum of 100
  mA, 500 mA or 1000 mA.

### D0…D7

All data lines are used by virtually all boards as both inputs and outputs.

### A0…A15, R/W̅

At the moment only CPU boards drive the address and R/W̅ lines. No current
CPU boards have provision for DMA (this would require a CPU with a bus
enable function or a buffer to isolate the CPU lines from the bus) so no
peripherals can ever drive these lines.

- Ouput: [CPU], [SBC].
- Input: All others.

### Φ0in: CPU Clock Source

Φ0in is normally used only by the CPU (other boards needing the system
clock use Φ2out).
- Input:
  - [CPU]: Required input signal, usu. provided by the [Reset] board.
  - [SBC]: Taken from bus if JP1 open.
  - [Debug]: Required input signal.
  - [TIA]: Input to TIA chip.
- Output:
  - [Reset]: Supplied to bus or not based on jumper block J2 setting.
  - [SBC]: Supplied to bus (and CPU) if JP1 shorted.

### Φ2out: System Clock

Φ2out is a CPU output signal and is driven only by CPU boards. It's used as
an input on many boards, often for qualification of the R/W̅ signal.

### Φ1out/EX0

Φ1out is a CPU output signal. The [SBC] board sends it to the bus, but the
[CPU] board does not. No boards appear to use this. The bus signal is
marked as EX0 on some schematics.

### /RESET

The /RESET line circuits are expected always to drive the /RESET line;
boards should not provide pullups for it (and no boards are known to do
so). Thus, only one reset circuit may be on the bus.

- Output: [Reset], [SBC]. Neither can be disabled, so these two boards are
  incompatible with each other.
- Input: [CPU], [RIOT], [Serial IO], [Terminal].

### /IRQ, /NMI

The interrupt lines are open-collector, with pull-ups usually supplied by
the CPU board.

- Pull-ups: [CPU] and [SBC] provide 3.3 kΩ pullups that cannot be disabled.
- Input:
  - [CPU]: Inputs are enabled with jumpers shorting J2 (IRQ) and J3 (NMI)
  - [SBC]: Inputs are always enabled
- Output:
  - [RIOT]: 6532 `I̅R̅Q̅` signal (pin 25) to bus if JP1 pins 2/3 shorted. JP7
    pins 1/2 shorted sends to /IRQ, pins 2/3 shorted sends to /NMI.
  - [VDU]: MC6847 `F̅S̅` signal (pin 37) to bus /IRQ if JP3 shorted.

### RDY

/RDY is a CPU input signal; the [CPU] and [SBC] boards provide a 3.3 kΩ
pullup on this line.

The following boards generate RDY output:
- [Debug]
- [TIA]

### SYNC

SYNC is a CPU output, and is generated only by the [CPU] and [SBC] boards.

Input:
- [Debug]: Used as an input to the single-step circuit.

### TX, RX

- [SBC]: Connected to the Arduino Nano; TX is the D1/TX output and RX is
  the D0/RX input.
- [Serial IO]: Connected to the Arduino Nano; TX is the D1/TX output and RX
  is the D0/RX input.

### Pin 38 (EX1)

The following boards may optionally use this line as an input:
- [TIA]: If JP5 (T0_EN) is shorted, use this as the T0/I4 (pin 36) input
  for the TIA chip. This is a latched input port typically used for
  joystick/paddle triggers.

The following boards may optionally use this line as an output:
- [RIOT]: If JP5 (T0_EN) is shorted, connect the right player
  joystick/paddle fire button signal.

### Pin 39 (EX2)

The following boards may optionally use this line as an input:
- [ROM]: If JP4 is shorted, use this as a "page" input to disable the ROM
  (presumably other boards could use the inversion of this signal to enable
  something else in its place). However, use of this feature is
  discouraged, and many systems may instead use a [RAM] board for ROM as
  well.
- [TIA]: If JP4 (T1_EN) is shorted, use this as the T1/I5 (pin 35) input
  for the TIA chip. This is a latched input port typically used for
  joystick/paddle triggers.

The following boards may optionally use this line as an output:
- [RIOT]: If JP4 (T1_EN) is shorted, connect the left player
  joystick/paddle fire button signal.

Third-party Modifications
-------------------------

This section describes changes to the bus interface used by
third-party boards.

#### appleii6502

[appleii6502][a26] (apparently an anonymous user hosting his blog on
[Ninja Tools][a26-nt]) has been producing and selling RC6502 boards
and kits in Japan. The technical focus seems to be around re-using the
signals generated by the [SBC]'s [74LS138 decoder][a26-decode] by
routing them on to the bus in the following way:

    Decode Range   RC6502 Bus   Apple 1 Expansion Slot
        $A000         35 TX          T (pin L)
        $B000         36 RX          S (pin 11)
        $C000         39             R (pin 21)

The $C000 to expansion slot pin R mapping corresponds to the [Apple 1
address decoding][a1decode] jumper settings needed by the [Apple Cassette
Interface (ACI)][aci].

His [Apple1 SBC Slot Expander][a26-se] adds two 44-pin expansion slots with
the same pinout as the original Apple 1. RC6502 bus signals TX, RX, 38 and
39 are brought to pads adacent to pads for the Apple 1 slot signals S, T
and R to which the builder can solder jumpers. Pin 39 is labeled `$̅C̅0̅0̅0̅`;
it's intended that the [SBC] be modified to bring its address decoding for
that signal to that pin. These jumperings are [shown in images
here][a26-cass-7].

The [Cassette Interface][a26-cass] is a clone of the original [ACI] that
plugs into the slot expander. It has a 2K ROM enabled by RC6502 bus pin 39,
which must be set up as a $C000-$CFFF decode (see above).

Another [post on slot expander decoding][a26-ab] explains how to disconnect
the Arduino's TX/RX (by cutting the pins off the Arduino board) and instead
wire $A000 and $B000 decoding to those bus pins. Presumably this is for a
future expansion card project.

RC2014 Bus Comparison
---------------------

The RC6502 bus is very similar to the [RC2014 bus] used on some Z80
homebrew computers. The following table compares the two; pins with
substantially different/incompatible functions are marked with a bullet
(`●`).

The 6502 uses the Motorola bus prococols; the Intel bus protocols are
substantially different, precluding sharing of peripherals unless they are
specifically designed with the extra hardware necessary to support both.
However, the backplanes are interchagable with some cavats; see below for
details.

        RC6502  Pin   RC2014      Notes
    ----------------------------------------------------------------
           A15   1    A15
             …   …    …
            A0  16    A0
           GND  17    GND
           Vcc  18    Vcc
         Φ2out  19 ●  /M1         Low on Z80 instruction fetch/int ack cycles
        /RESET  20    /RESET
          Φ0in  21    CLK
          /IRQ  22    /INT
     Φ1out,EX0  23 ●  /MREQ
           R/W̅  24 ●  /WR
           RDY  25 ●  /RD
          SYNC  26 ●  /IORQ
            D0  27    D0
             …  …      …
            D7  34    D7
            TX  35    TX,TX2      May be user-specified function on RC2014
            RX  36    RX,TX2      May be user-specified function on RC2014
          /NMI  37 ●  USER1
         -,EX1  38    USER2       Some RC2014 modules use USER2 and USER3 as
         -,EX2  39    USER3         IEI and IEO for interrupt daisy chain.
                40    USER4,IEO   Nonexistent on RC6502

### Backplane Compatibility

The [RC2014 backplanes][RC2014-spec] (as of the 0.4 draft specification)
can be used with RC6502 boards and vice versa, with some caveats. The power
(18) and ground (19) pins may be supplied by the backplane and are
compatible. The following other pins have caveats:

* __/RESET__ (20)
  * RC2014 backplanes with a power supply (SC105, SC112) have a 4.7 kΩ
    pull-up resistor on /RESET. RC6502 board reset logic should be able to
    pull this line low to reset the system. RC2014 backplanes also have a
    reset switch; this ___must not be closed___ as it will conflict with
    the standard reset output circuitry of RC6502 boards, potentially
    damaging the board.
  * RC6502 backplanes have no reset logic, so a pull-up (4.7 kΩ to Vcc) and
    an RC2014 board will need to supply a reset signal. The SC108 CPU board
    supplies power-on reset but has no reset button. The SC101, SC114 and
    SC130 provide a reset button.
* __Pin 40__.
  * RC2014 backplanes provide pin 40 as a bus or daisy chain (with pin
    80) depending on the model. This pin does not exist on RC6502 boards
    and thus can be ignored. Be careful not to insert the RC6502 board
    offset by one pin.
  * RC6502 backplanes do not provide pin 40, so the USER4 signal cannot be
    used.

<!-------------------------------------------------------------------->
[Backplane]: ./RC6502%20Backplane/
[CPU]: ./RC6502%20CPU/
[Reset]: ./RC6502%20Reset%20Circuit/
[SBC]: RC6502%20Apple%201%20SBC/
[a1decode]: https://github.com/0cjs/sedoc/tree/master/8bit/apple1#address-decoding

[Debug]: ./RC6502%20Debug/
[RIOT]: ./RC6502%20RIOT/
[ROM]: ./RC6502%20ROM/
[Serial IO]: ./RC6502%20Serial%20IO/
[TIA]: ./RC6502%20TIA%20NTSC/
[Terminal]: ./RC6502%20Terminal/
[VDU]: ./RC6502%20VDU/

[ACI]: https://www.sbprojects.net/projects/apple1/aci.php
[a26-ab]: https://appleii6502.no-mania.com/apple1%20sbc%20slot%20expander/apple1%20sbc%20slot%20expander%E3%82%A2%E3%83%89
[a26-cass-7]: https://appleii6502.no-mania.com/apple1%20cassette%20interface/apple1%20cassette%20interface%E7%B5%84
[a26-cass]: https://appleii6502.no-mania.com/apple1%20cassette%20interface/apple1%20cassette%20interface
[a26-decode]: https://appleii6502.no-mania.com/apple1computer/apple1%20sbc%E3%81%AE%E3%80%8C4k%20blocks%E3%80%8D%E3%82%A2%E3%83%89%E3%83%AC%E3%82%B9
[a26-nt]: https://www.ninja.co.jp/
[a26-se]: https://appleii6502.no-mania.com/apple1%20sbc%20slot%20expander/apple1%20sbc%20slot%20expander%E5%9B%9E%E8%B7%AF%E5%9B%B3
[a26]: https://appleii6502.no-mania.com/

[RC2014 bus]: https://smallcomputercentral.wordpress.com/documentation/specification-rc2014-bus/
[RC2014-spec]: https://smallcomputercentral.files.wordpress.com/2018/09/modular-backplane-specification-v0-4-2018-09-19.pdf

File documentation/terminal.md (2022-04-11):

# RC6502 Terminal

## Burn Arduino bootloader
Using Arduino USBtinyISP, installed drivers from [adafruit](https://learn.adafruit.com/usbtinyisp/drivers) as those worked with the device I found in a drawer. Under *Tools* in the Arduino software, set board to Arduino Nano with Atmega328p and select *USBtinyISP* as *Programmer* - then select the *burn bootloader* option from the menu. Do this for both of the Atmega328p chips, after doing so the board should now be two functional Arduino clones in one.

When programming the new Arduino boards with the software you need to run on it, you could technically keep using the *USBtinyISP* and you'll have just a bit more resources available on it as that would mean flashing it with the sketch itself and leaving out the whole Arduino part of the equation. On the other hand, if you want to use them as an Arduino and that was really the whole point of flashing it with the bootloader - then you'll want a more standard way of uploading code to the board. For this you'll need a standalone *USB Serial TTL adapter*, this includes the little serial chip responsible for handling the communications with your computer over USB - it's a cheap thing and you'll want to have one around the house before long anyway.

Plug it in according to the markings on both of the boards (numbered according to connector on RC6502 Terminal, pin six is at the top):
6. GND goes to GND
5. (Not Connected)
4. VCC goes to +5v
3. RXD goes to TXD
2. TXD goes to RXD
1. RST goes to DTR

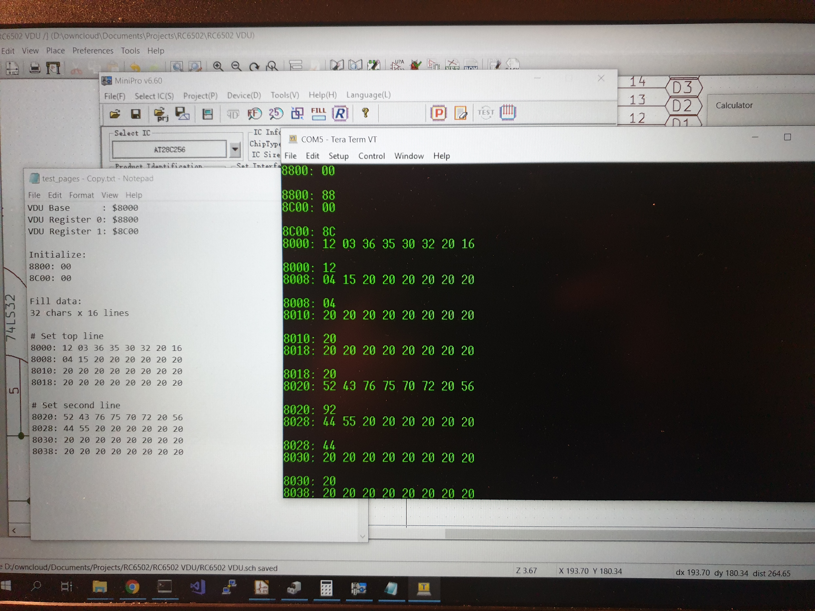
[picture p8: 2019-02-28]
RC6502 VDU/gallery/2019-02-18 21.13.49.jpg

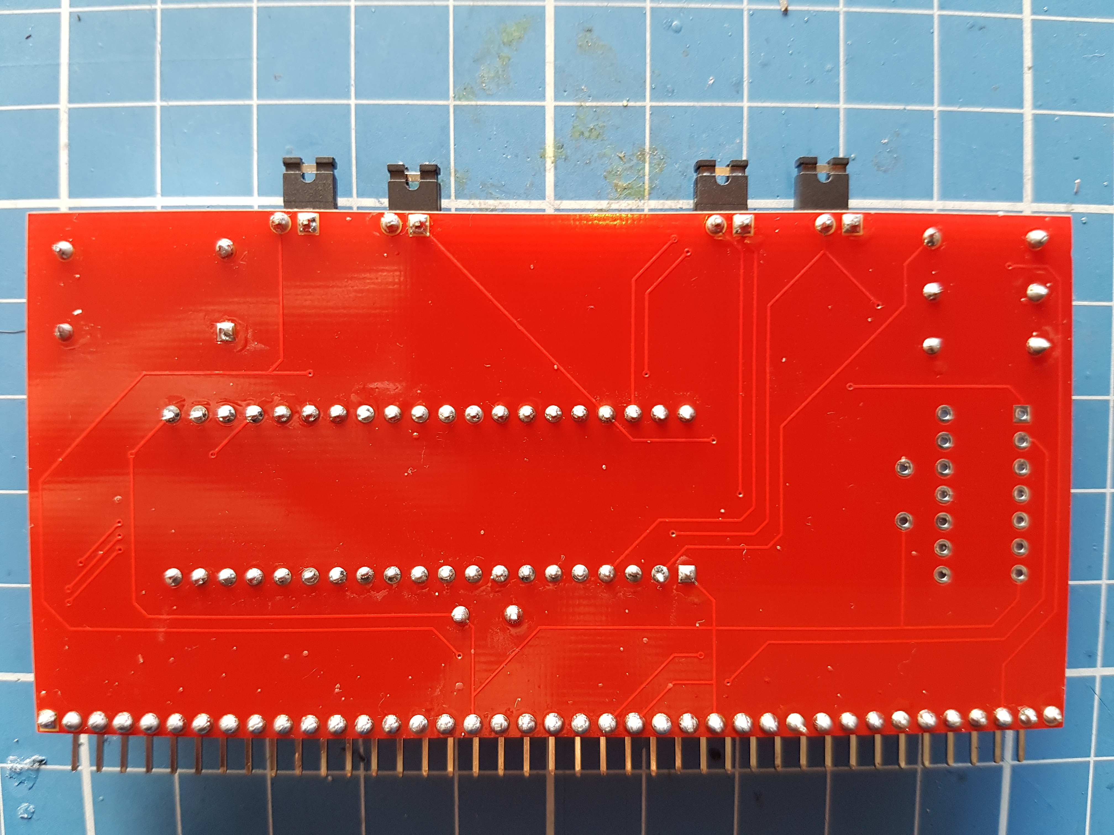
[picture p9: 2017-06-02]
RC6502 CPU/gallery/2017-06-02 19.52.32.jpg

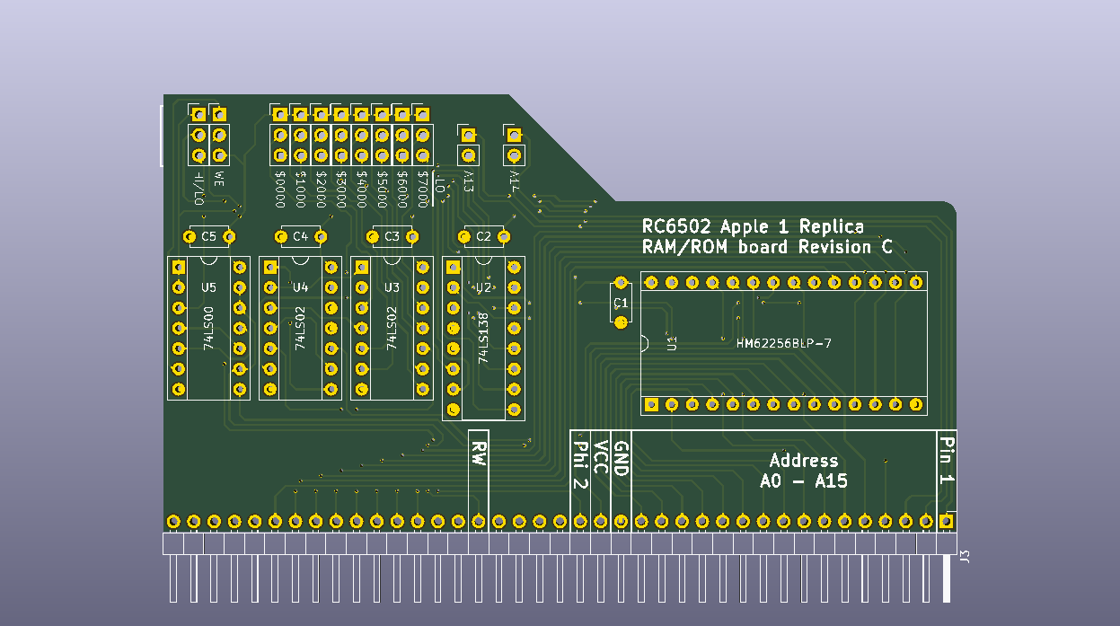
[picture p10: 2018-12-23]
RC6502 RAM/gallery/RC6502 RAM Preview #2.png

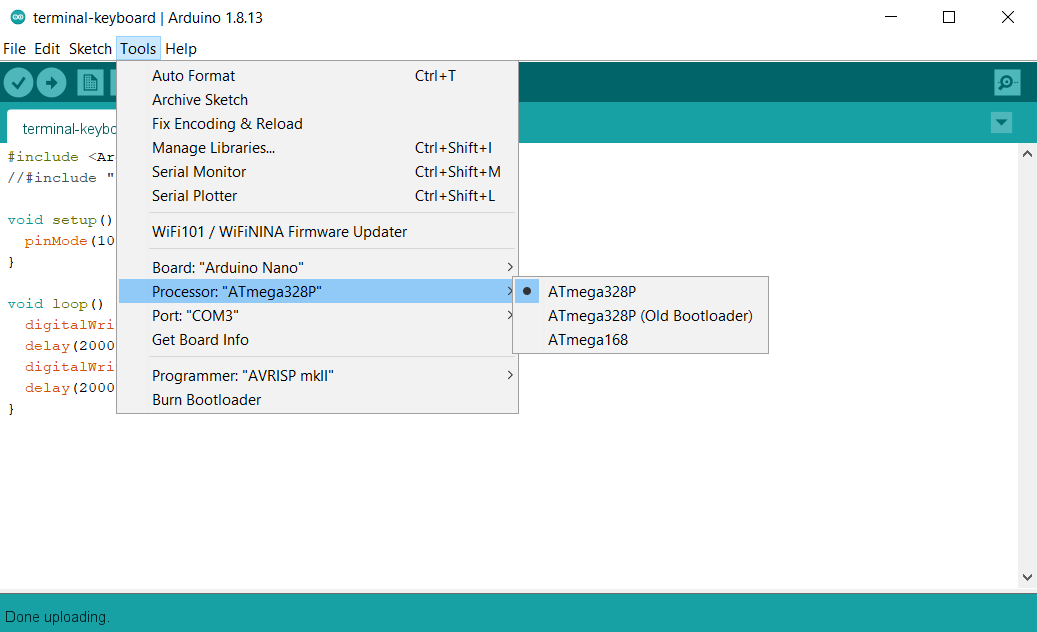
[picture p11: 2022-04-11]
RC6502 Terminal/gallery/Upload serial.png

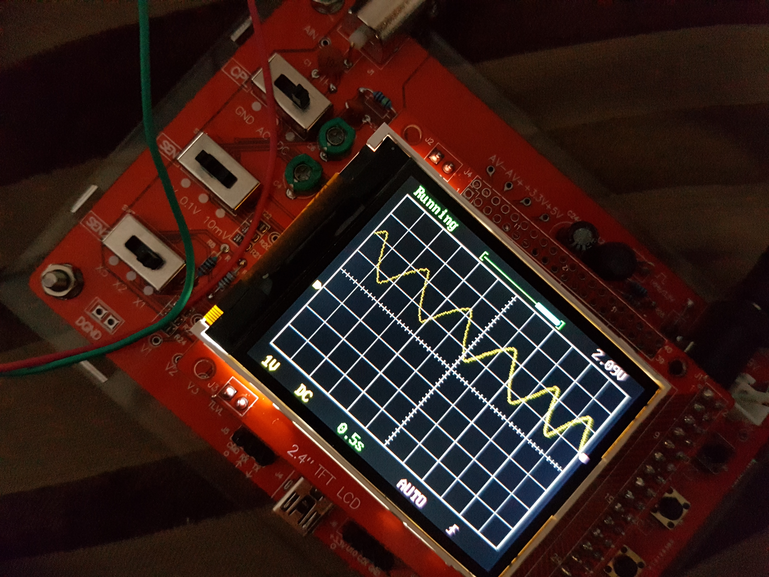
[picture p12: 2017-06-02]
Gallery/2017-05-31 23.59.30.jpg

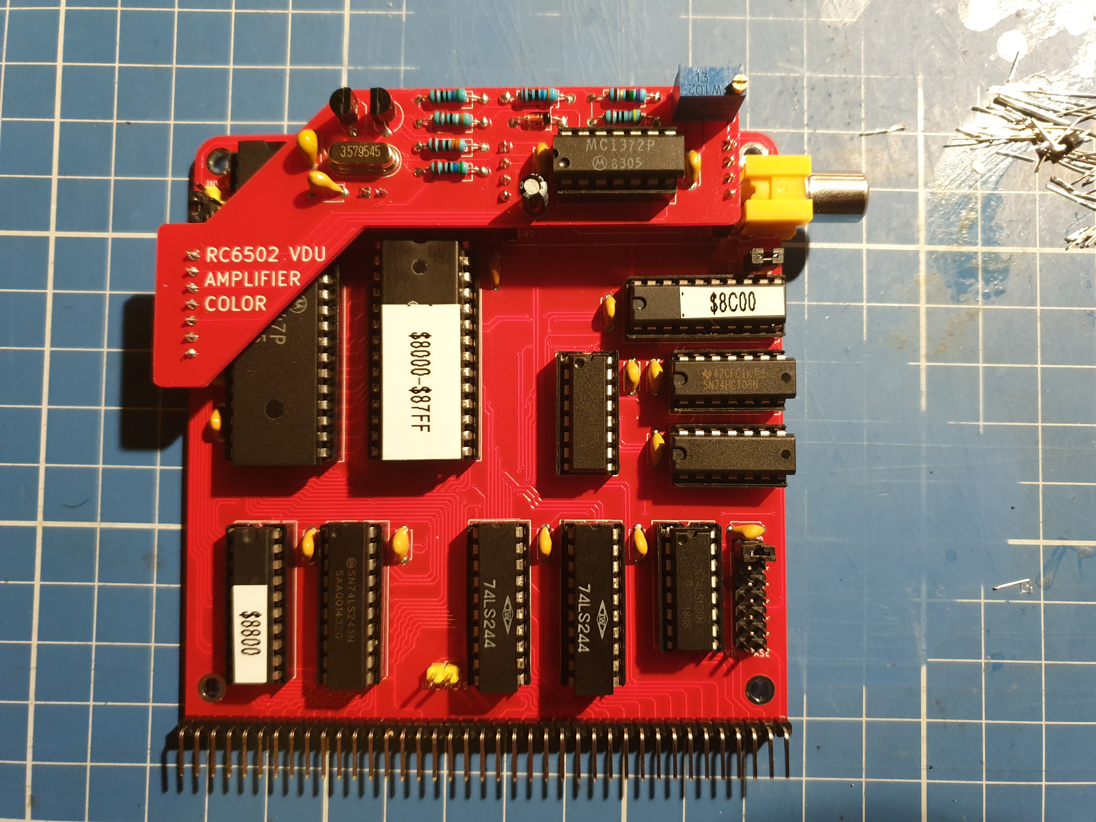
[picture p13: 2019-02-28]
RC6502 VDU Color Amplifier/gallery/2019-02-27 22.07.48-1.jpg

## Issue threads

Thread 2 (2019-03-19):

Forum?

davischris, 2019-03-19:
Is there a forum for discussion on this project?  I have some questions.

tebl, 2019-03-30:
Don't have one, thus far I'm assuming your tinkering with it makes us two :-)

Not sure if the reply to your blogger comment made it through to your end, but sent some initial troubleshooting tips to start with on it. Pasting the same thing here, just in case the reply was lost to the ether:

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

davischris, 2019-04-01:
I have it working.  I suspect it was two issues: First, I was mixing 74LS chips with 74HCT.  I just made sure I used three 74HCT chips.  Also, it does not appear to work with a Rockwell R6502AP (or I have a bad one.)  It does work with an SY6502 (pulled from an Apple II) and I also have it working with a Rockwell R6502A.  Thank you very much for your work on this.  Be encouraged - I had to make 5 boards (the minimum order) so there are four of my friends also working on it!

jjohnson873, 2019-04-18:
Hi Chris. Just finished soldering all the passive components and the sockets on to the board you sent to me.  I've got all of the IC's, but I'm waiting on the SY6502, and the 6521 from China.   The AT28C64 should be in shortly.   I'm also waiting on an EEPROM programmer from China as well.

0cjs, 2020-01-11:
> Also, it does not appear to work with a Rockwell R6502AP (or I have a bad one.) It does work with ...Rockwell R6502A.

Does anybody have any further information on why it might not work (or whether it does actually work) with the Rockwell R6502AP, and could this possibly also apply to the R6502P? I have just built a kit (bought from an auction site) using a revision F+ board. I can't tell you if it's exactly the board from this repo, but it came with parts from a guy who appears to have built his own and got it working, so I'd be surprised if he's selling a known-bad design or parts known not to be working on the board.

And what is the difference between the P and non-P versions anyway? I had assumed that the "P" just meant a plastic (as opposed to ceramic) package, but my part looks like it has a date code of "1349," by which point I thought nobody was using ceramic packaging for 6502s any more. (And not manufacturing NMOS ones either, for that matter, but who knows? The complete markings on the chip are, `R6502P  13500-13  MEXICO  1349  B50323-8`, and a logo.

Closed 2019-06-23.

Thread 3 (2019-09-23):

No life...

rockcat, 2019-09-23:
Hi
Are there any known issues with your rev F board?
I've built one but there's no sign of life. All soldering looks ok but I may just have a short somewhere...

Thanks
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

rockcat, 2019-10-04:
HI
Found the problem - a dodgy capacitor - replaced it and now no short.
Next problem is that I  am getting millions of newlines thrown at me.

Also, do you have the source code of the ROM?

Thanks

rockcat, 2019-10-14:
All working now :)
My 7400 had got fried.
Thanks for the PCB design !

tebl, 2019-10-20:
Been sick a while, so I didn't notice the ticket - glad to see you got it working. Never imagined the 6522 working directly without changes though, so that's new :-)

I used the ROM contents out of the Ben Heck project (https://github.com/thebenheckshow/158-tbhs-apple-1-replica/tree/master/software/code), it also has the source file. That project never had any hardware documentation, which is where mine got started to fill the gaps and have fun along the way.

Closed 2019-10-22.

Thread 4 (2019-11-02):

Raspberry Pi

rockcat, 2019-11-02:
Hi

You might like this: https://github.com/rockcat/RPi_RC6502

Cheers

tebl, 2019-11-03:
That is pretty cool, thanks! Wonder if it'd work with a Pi Zero and a small adapter board, would look nice to have it slotted on there :-)

rockcat, 2019-11-03:
Yes should work with any Pi, you could remote in over wifi too :)

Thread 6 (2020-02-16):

Can't compile the arduino sketch. Matching lib needed.

Creep69, 2020-02-16:
Hello,
I am also trying to get the board running. My problem is the Arduino sketch for the serial communication. To compile it, you need to add a MCP23S7 lib. But the matching lib is not provided in the github project. I tried at least 5 different libs, I found on the internet. Also one lib another guy sent me who already built the Apple replica. But no lib matches. The class itself needs different parameters, the methods have different names (and parameters). Is there a chance you could give a link to a suitable library? My board is complete, but the Arduino is a showstopper.
Best regards,
Rene

tebl, 2020-02-17:
Sounds like I'm overdue to revisit the Arduino sketch and update things, but in the meantime I've moved things around and in the lib-folder at https://github.com/tebl/RC6502-Apple-1-Replica/tree/master/software/arduino/PIA%20Communicator you'll find a copy of the library I've been using. Sketch itself in the pia_communicator folder as previously.

Creep69, 2020-02-17:
Great, thanks a lot for the immediate fix. Now, the sketch is working fine.
Rene

Closed 2020-02-17.

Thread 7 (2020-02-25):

pia_communicator map_to_ascii() is partly nonsensical

0cjs, 2020-02-25:
The [`map_to_ascii()`][map] function in pia_communicator seems to be at least partly nonsensical. It's passed the output of [`Serial.read()`][read], which returns a byte read from the serial port. An examination of the [standard AVR source code][avr] indicates that it will always return a value between 0 and 255 (if a character is available) and as far as I'm aware the AVR serial ports read values no larger than 8 bits. So:

1. The "Ctrl A-Z" code checks for values larger than 255, which can never be returned, and thus does nothing. If there is some sort of case (linking to a different library?) where the values this checks can be returned, this should be documented, otherwise the code should be removed.

2. The "Convert ESC key" code checking for a value of 203 doesn't make sense to me; it would be unusual for a terminal program with correct communications settings to set the high bit on ASCII characters, and if it did why would it do so only for ESC and not for any other characters? Again, remove or document.

[map]: https://github.com/tebl/RC6502-Apple-1-Replica/blob/ba325dcfe5182241f4acea80a95200274a5b0ba3/software/arduino/PIA%20Communicator/pia_communicator/pia_communicator.in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
[read]: https://www.arduino.cc/reference/en/language/functions/communication/serial/read/
[avr]: https://github.com/arduino/ArduinoCore-avr/blob/0e7fae85bdfbab43242374c0289cdd806d13b0bc/cores/arduino/HardwareSerial.cpp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

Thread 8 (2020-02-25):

pia_communicator: Incorrect Control Character Handling

0cjs, 2020-02-25:
The control character output handling of the PIA communicator is [substantially different from the actual Apple 1][sedoc]. Here is the original Apple 1 behaviour:
* ASCII Control characters ($00-$1F) other than CR ($0D) print nothing and do not move the cursor.
* CR ($0D) fills the remainder of the current screen line with spaces and sets the cursor to the next line, scrolling the display if the cursor was on the last line.
* Characters from the upper-case sticks ($20-$5F, space through underbar) are printed as-is.
* Characters from the lower-case sticks ($60-$7F) print the same glyphs as the upper-case sticks. (Though $7F is an ASCII control character, the Apple 1 treats it as a printable character with the same glyph as $5F.)

(See the link above for references verifying this behaviour.)

pia_communicator passes all control characters directly through to the serial output which produces substantially different behaviour in any standard terminal program because those terminal programs process characters such as ASCII BS ($08) by doing cursor movements that the Apple 1 was incapable of, as well as printing different glyphs for the lower-case sticks.

The obvious fix would be to change pia_communicator to generate ASCII output to the serial port that emulates the behaviour of the actual Apple 1 video system. However, a reasonable argument could be made that not converting the lower-case sticks (excepting $7F) to the equivalant codes in the upper case sticks is not harmful, and potentially useful.

It might (or might not) also be useful to tweak the input handling better emulate the Apple 1 keyboard. pia_communicator already maps lower case to upper case; possibly it should also, for convenience, map backspace to `_`, the character that WozMon uses to command "remove previous char from input buffer." That, however, may run into issues with other software, such as [KRUSADER], which uses backspace (in this case for "cancel line"). I suppose the ideal would be to have some settings in the program to change this on the fly, e.g., `~B<BS>` and `~B_` to change the backspace key translation to backspace and underscore, respectively.

[sedoc]: https://github.com/0cjs/sedoc/blob/master/8bit/apple1/README.md#video
[KRUSADER]: http://school.anhb.uwa.edu.au/personalpages/kwessen/apple1/Krusader.htm

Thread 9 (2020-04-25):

RC6502 Rev D RAM and ROM enabled jumpers

cskordis, 2020-04-25:
I have built the RC6502 SBC Rev D plugged into the backplane.
So far the arduino terminal coms works but no backslash.
I was wondering what the RAM_EN and ROM_EN should be set to on the SBC.

Regards

Costas

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

0cjs, 2020-04-28:
`RAM_EN` should be on the left-hand pair of pins to enable the RAM, and `ROM_EN` should be on the top pair of pins to enable the ROM. You have both these disabled in your photograph. You also of course need to make sure that the  ROM is correctly programmed with at least the Apple 1 Monitor (WozMon) programmed into the highest 256 bytes of your 8 KB EEPROM.

Since you appear to be using an AT28C64 8 KB EEPROM, the A13 and A14 jumpers should be left disconnected. These are used to select which 8 KB bank would be used in a 32 KB AT28C256 EEPROM. If you ever switch to one of those, you'd want to program the lowest 8 KB bank and jumper the right-hand pair of pins for both.

You can find more information on jumper settings (and perhaps some other useful information) in [my notes here](https://github.com/0cjs/sedoc/blob/master/8bit/apple1/replica-sbc.md).

cskordis, 2020-04-28:
Thank you Curt

I used the 8k image from the github site on the 28C64.
But I am not getting the back slash character

Regards,

Costas Skordis

On Apr 27, 2020, at 21:05, Curt J. Sampson <notifications@github.com> wrote:

RAM_EN should be on the left-hand pair of pins to enable the RAM, and ROM_EN should be on the top pair of pins to enable the ROM. You have both these disabled in your photograph. You also of course need to make sure that the ROM is correctly programmed with at least the Apple 1 Monitor (WozMon) programmed into the highest 256 bytes of your 8 KB EEPROM.

Since you appear to be using an AT28C64 8 KB EEPROM, the A13 and A14 jumpers should be left disconnected. These are used to select which 8 KB bank would be used in a 32 KB AT28C256 EEPROM. If you ever switch to one of those, you'd want to program the lowest 8 KB bank and jumper the right-hand pair of pins for both.

You can find more information on jumper settings (and perhaps some other useful information) in my notes here<https://eur03.safelinks.protection.outlook.com/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>.

—
You are receiving this because you authored the thread.
Reply to this email directly, view it on GitHub<https://eur03.safelinks.protection.outlook.com/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>, or unsubscribe<https://eur03.safelinks.protection.outlook.com/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>.

0cjs, 2020-04-29:
I would expect you're not getting the backslash character because, according to your photographs, you have incorrect jumper settings.

Also, if you can please trim down your responses it will make them a lot easier to read. ([View your comment on GitHub](https://github.com/tebl/RC6502-Apple-1-Replica/issues/9#issuecomment-620660330) and you'll see your two-line response is buried in fifty or so lines of mostly irrelevant stuff, including a complete copy of my comment immediately above.)

cskordis, 2020-04-29:
Thanks Curt.
I did set the jumpers as specified but I don't get a response only from the arduino.
Interesting it looks like A15 is not pulsing but constantly high.
I don't know of the 8k ROM image is the right one although I did download it from the github
I've ordered new MCP23S17 and 6821 just in case the ones I have are fake. I know the CPU, RAM and ROM ICs are good.
I've also order Rev H of the SBC board and will build that one in case the Rev D board has issues.

Costas

0cjs, 2020-04-29:
Ok, if your jumpers are now correct there is likely to be a fair amount of back-and-forth in the debugging process. I suggest creating a new post in [the 6502.org Forum](http://forum.6502.org/) about this, since there's a lot more people reading that and you'll get more detailed help. (I'm not sure if anybody else besides me there is using this particular board, but at this point the problems can be addressed by a  fairly generic 6502 SBC debugging process.)

You'll want to reference this issue and also explain in detail what test equipment you have available (e.g., do you have an oscilloscope?) and the particular debugging steps you've taken so far. The two obvious places to start are to see if the CPU appears to be starting up correctly and looping correctly in `GETLINE` while waiting for input and if the input and output chars are appearing correctly on ports B and A of the PIA.

> I don't know of the 8k ROM image is the right one although I did download it from the github

It's probably a good idea to read back your ROM and confirm that the code in the top 256 bytes of the ROM matches the [code from the Apple 1 manual](https://archive.org/details/Apple1Manual1976/page/n6/mode/1up). You can even do this by wiring up the ROM on a breadboard with the appropriate pull-ups and -downs and seeing what its putting on its data pins. Checking the reset vector at $FFFC, the first few bytes of the initialization routine at $FF00, and `NEXTCHAR` at $FF29 should probably be fine.

> Interesting it looks like A15 is not pulsing but constantly high.

That would be expected if it's looping at `NEXTCHAR` ($FF29-$FF2D), waiting for input, since all the addresses it's reading are in the upper 32K of RAM.

> I've also order Rev H of the SBC board and will build that one in case the Rev D board has issues.

Right. I'm not familiar with the D board; mine is an "F+".

cskordis, 2020-05-03:
Curt,

I think I found the issue.  My eBay purchase of the MCP23S17 gave me a MCP23017. Never trust eBay  sellers.

Have ordered them from DigiKey.

Will let you know how I get on.

Costas

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

cskordis, 2020-05-23:
CJ,

I hope you are keeping safe.

Just wanted to let you know that I have 2 RC6502 running perfectly. Thank you for all your help.

I’ve just ordered the RC6502 Terminal and was wondering where I can find the firmware was for the ATMega 328P Video and Keyboard.

Regards

Costas Skordis

tebl, 2020-05-23:
Funny story about the firmware for that, there was a pandemic... PCBs got
delayed and I'm in the process of moving, so I haven't gotten started on it
yet.

lør. 23. mai 2020, 15:30 skrev cskordis <notifications@github.com>:

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

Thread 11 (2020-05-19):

Debug board SYNC signal direction indication is incorrect

0cjs, 2020-05-19:
In [PDF schematic for the Debug board](https://github.com/tebl/RC6502-Apple-1-Replica/blob/master/RC6502%20Debug/export/RC6502%20Debug.pdf), the `SYNC` signal has a directional indication that it's an ouput from the clock input of the 74LS74 to the bus, but in fact that's an input from the bus. The directional indication should be reversed.

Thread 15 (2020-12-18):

SBC Schematics seems incorrect

hugoferreira, 2020-12-18:
Pin 6 of the Arduino Nano is reported to be connected to the CLOCK (which would be interesting, for those that don't have an available crystal, or to do some cycle-stepping). However, at least in the Revision H of the PCB, this pin is not connected.

0cjs, 2020-12-19:
It's not possible to slow/pause the clock to cycle-step an NMOS 6502, or run it at much less than about 100 kHz. ([Reference](http://wilsonminesco.com/6502primer/ClkGen.html)) Unlike CMOS 65C02s, the NMOS versions do not have a static core and will lose the data in their registers if the clock is too slow. (You can stop the clock with CMOS 6502s, so long as you do so only when φ2 is high.) The standard way of cycle- or instruction-stepping a 6502 is to halt the CPU by deasserting RDY.

There might also be issues with the 6820/6821/6521, since it has a clock input.

That said, yes, the pin might be useful for clock generation, though it would increase the complexity of the software on the Nano.

hugoferreira, 2020-12-19:
I agree with everything you've said. That's why I'm reporting this as a bug :) The clock label in the schematics PDF should not exist.

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

0cjs, 2020-12-19:
Ah, I didn't realize you were saying the label should be dropped! Yes, I agree.

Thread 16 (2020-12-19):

Video Out gets stuck and other Instabilities

hugoferreira, 2020-12-19:
First of all, I'm not sure if this is an issue, or some problem of my build. Nonetheless, I hope someone can help me out (and in the process, maybe document some learning).

**TL;DR;** PIA Communicator either gets stuck, or enters and endless loop of displaying a mix of garbage or the same character. One way to force this in my build is to simply connect the BUS to a breadboard.

As far as I understand the Apple 1 Video Out, there are two signals, RDA and DA. DA says that there's a character to be displayer, and RDA informs the PIA that the terminal is ready to accept that character. Once RDA goes from HIGH to LOW, then DA becomes low. DA is connected to PB7 in the PIA, and is the only pin on PB that is configured as input. The transition from HIGH to LOW in DA is controlled by the negated output of CB2.

Now, whenever the SBC becomes "stuck", according to my quick debug, I can see two things: first, the CPU is not stalled. The Address lines are changing, as well as the data lines. But there's an inconsistency in the signals. CB2 is outputting LOW, which is negated by the 74xx04 IC. I can confirm that its output is HIGH (4.62V). I can also confirm that one pin of the 10nF capacitor exhibits 4.62, but the other pin is at 0V. This is confirmed by probing PB7 which is LOW (should be HIGH). Something, somewhere, is asserting this line LOW, when it shouldn't.

Now, from the schematics, this line seems to be connected solely between the Arduino and the PIA. Nothing else is in between. So my hypothesis is that either the PIA changed the DDR of PB somehow, or the Arduino is pulling the line LOW (somehow).

By the way, I can stall my system in the following simple way: simply connecting the BUS to a breadboard 😕

jpdias, 2020-12-19:
I also did build the same version of the RC6502 and I'm having an even worse experience since I'm not obtaining any meaningful output from the Arduino. I already removed/inserted most of the ICs and even changed some with some available spares. No change in behavior. The attached image shows the output, and it keeps going forever like so.

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

hugoferreira, 2020-12-19:
It seems that stabilising potential current spikes with a 330uF electrolytic capacitor (best place I've found is near the BUS connector on the bottom), solved the problem (at least it has been running as expected for the last 50 minutes straight).

Now, concerning that video out fails when I connect the SBC to a breadboard, I'm starting to suspect might be due to me using version S of the PIA (W65C21S), which does not have limiting resistors. My main hypothesis is that connecting to the breadboard elongates the signal lines into transmission lines, which might lead to signal reflections if not correctly terminated. The limiting resistors of the N version might act as line terminators on the near end. But this is all wild guess, until I receive a batch of W65C21N's.

tebl, 2020-12-22:
I've done very little work with W65C series chips, so as it stands - I consider those a theoretical might work at the moment. From what I remember of the documentation, the N chip is the one that can be used without changes to the circuit.

There's been quite a lot of fake chips of both variants floating around, so if they came from ebay/AliExpress and similar sites it may be a good idea to try out a second chip - I've mostly had luck with MC6821/R6502.

hugoferreira, 2020-12-22:
These came directly from Farnell, so I assume it's a reliable source 👍 As expected using an old Rockwell 6502 solves the PHI2O problem, which is consistent to my hypothesis on the sensitivity in the line. Now here comes the odd part: with a W65C02, _just probing_ the PHI2O pin with the scope is enough to block the video out, and only a reset solves the problem. Still not sure if this is because the PIA is being picky and if a 65C21N would solve it... But it is funny, isn't it? My nexts steps are going to be:

a. Try a 50 Ohm near-end termination on the PHI2O;
b. Prolly just cut the trace of the PHI2O and put a bodge wire between the PHI2 and the E/PHI2 on the PIA.

By the way, I know this is the way it's presented in Owad's book, but was there any particular reason you had in choosing to expose PHI2O instead of the oscillator's CLK directly on the BUS?

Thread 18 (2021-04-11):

Which versions of 6502 are compatible with SBC version?

natevw, 2021-04-11:
Hello, thank you for this design! Looks fun, I have some PCBs on their way and hoping to build one maybe with a Rapberry Pi Pico eventually!

I am trying to source the right 6502 processor without spending too much. The BOM says "UM6502 or SY6502" implying this needs an NMOS version of the 6502? These are older and more expensive afaict. I also read at https://github.com/tebl/RC6502-Apple-1-Replica/issues/2#issuecomment-478630350:

> it does not appear to work with a Rockwell R6502AP (or I have a bad one.)

Which I think is NMOS but at least a different (maximum? must be exact?) clock speed of 2MHz instead of the usual 1MHz.

But I also read on https://hvetebolle.blogspot.com/2017/06/rc6502-montering-og-feilsking.html (translated):

> [3.3k resistor] recommended when using 65c02 processors from Western Design […] The card works with the far cheaper and far more up-to-date versions of the 6502 processor, so is happy so far.

That sounds like the newer cheap CMOS ones? Would a W65C02S6TPG-14 work in the SBC version current revision? [Although maybe not much cheaper new than vintage eBay parts anyway…]

tebl, 2021-04-11:
The W65c02 was more done from a theoretical standpoint after reading a
Western Designs document on substituting them, but have not had much luck
getting them to work. W65C21N should be paired with it, S-variant
definitely won't work.

R6502AP I think should be comparable to UM and SY branded 6502, I at least
remember using one at some point.

søn. 11. apr. 2021, 06:38 skrev Nathan Vander Wilt ***@***.***
>:

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

Closed 2022-02-01.

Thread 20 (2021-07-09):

VDU not completely working; help?

liamoc, 2021-07-09:
Hi, thanks for a great kit computer.

I've built a VDU and a black and white amplifier, and now when I plug the machine in and turn it on I get a sea of question marks, which suggests the video chip is working correctly.

Then I try (using the serial interface) to write to video memory in WozMon like so
```
8800: 00
8C00: 00
8000: 12 20 20 20
````

Nothing happens. Querying address 8000 returns `FF`. It seems like video RAM is not being mapped in? I have the VDU Base jumper set to the topmost one, i.e. 0x8000 and jumpers in VDU_EN, OSC_EN and on the lower positions of both INV_SEL and CSS_SEL. Is there something I should change here?

Edit: Oh, next time I turned it on, I got a sort of checkerboard pattern with 8x8 blocks of question marks and of @ signs (or backwards 6s?). When I write 00 to 8800 it turns into the normal sea of question marks

Edit: I also don't seem to be getting any results when I try to write to the locations of the LEDs (a000 etc.) on the joystick/digital I/O board. But I can at least read the state of those buttons OK.

liamoc, 2021-07-09:
Nevermind, replaced the video RAM chip and all is well

Closed 2021-07-09.

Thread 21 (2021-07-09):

How to write to digital I/O LEDs?

liamoc, 2021-07-09:
Hi, thanks for a great SBC. I've assembled a number of additional components like the Joystick/Digital I/O board and the VDU too. So far, everything works except I don't know how to write to the LEDs.

I tried using WozMon to write to the same address I can read the buttons from (`A000`) but nothing happens -- the LEDs are just always on. Is there some direction register I have to set or something?

tebl, 2021-07-09:
It should be fine to just do a write to that address, but I seem to
remember that there was something about WozMon itself that was the issue
(or a combination with something I did). Maybe try a small machine code
program or something in basic.

fre. 9. jul. 2021, 20:35 skrev liamoc ***@***.***>:

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

liamoc, 2021-07-09:
Hmm, I tried running this in BASIC:
```
> POKE -24576, 0
> POKE -24576, 255
```

And the lights remained solidly on. I think `-24576` is the correct location for `$A000` right? I'll try a machine code program soon.

tebl, 2021-07-10:
Now that I'm looking at the schematic, I think that the 373 should be a
374. They have the same pinouts and may have exchanged it on my board
without updating the document.

lør. 10. jul. 2021, 01:59 skrev liamoc ***@***.***>:

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

liamoc, 2021-07-10:
Alright, I've ordered some 374's. When they arrive I'll see what happens.

liamoc, 2021-07-21:
This worked! So it should be 74LS374 rather than 74LS373.

Closed 2021-07-21.

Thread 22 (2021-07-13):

Reducing noise in video output?

liamoc, 2021-07-13:
Hi, I recently built a VDU and both amplifiers. With either amplifiers I am getting a flickering pattern of horizontal lines, clearly visible particularly in the background. I've got some old micros that produce similar noise, so I assumed it was normal, but the screenshots in the gallery in the repo don't seem to show the same pattern.

I've attached photos in various graphics modes to demonstrate what i mean. Does anyone know which component might be at fault here? It'd be nice to get a clearer picture.

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

tebl, 2021-07-14:
I have Dragon 32 with a dreadful picture as well, which is something I
expect is something of quirk for the chip. The circuit was designed when
CRTs was the norm, so it might not have been an issue back then.

For the most part, working with the analog stuff is a bit out of my reach
though there is a few tips I can provide. The first is to use a good
shielded cable, then check the TV settings; turning the colour down until
you get B/W and if the lines disappear they are in the colour circuit (turn
down any sharpness setting to avoid TV messing with the signal).

tir. 13. jul. 2021, 23:48 skrev liamoc ***@***.***>:

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

liamoc, 2021-07-21:
Alright, thanks for the tips!

Closed 2021-07-21.

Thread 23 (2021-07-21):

I think I broke mine by being an idiot

liamoc, 2021-07-21:
I accidentally left my SBC resting on a conductive surface and turned it on via the 5V power from the backplane. It immediately shorted and seemed to turn off. Upon correcting this issue and plugging it in again, i can't seem to get anything to work anymore. It doesn't seem to be booting correctly. The Arduino itself seems to be fine (it shows a ! when I connect to the serial interface), so I suspect that the EEPROM has been corrupted. I don't think a 5v short would really damage any of the other chips, although I suppose it's possible. Anything else I should try before I start replacing chips?

liamoc, 2021-07-21:
Oh, I just realised the oscillator I have in here seems to be getting very hot! Is that normal? Or is that perhaps the broken culprit?

tebl, 2021-07-21:
The oscillator should get comfortably warm, so if it gets any warmer than
that - then I'd try exchanging it.

A direct short when used with a powerful PSU can also vaporize tracks, so
might be a good idea to look for dark spots on the PCB.

ons. 21. jul. 2021, 14:55 skrev liamoc ***@***.***>:

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

liamoc, 2021-07-23:
Thanks for the tips! The oscillator is hot enough that it is slightly painful to touch, but it's not so bad as to actually burn me. I think that's too hot. I will get out my desoldering braid and replace it soon.

liamoc, 2021-08-03:
I tried replacing the oscillator and the new one doesn't run so hot but the machine still doesn't work. I reprogrammed the EEPROM, still didn't work. Then I just decided to solder up a whole new board seeing as I have the parts anyway, so I did that and moved the chips over. Still didn't work -- exactly the same problem. So I know it's not the eeprom, the oscillator, or any of the traces on the board. Now I've ordered a new ne555 in case it's just not powering on properly (the reset button doesn't seem to produce any change, so perhaps this is the culprit). I also ordered MCP23S17 in case that's the problem, and a new 6821 because I found one for cheap. When they arrive i'll try replacing those chips. It may be that I will be able to make two working SBCs from my leftover chips 🤣

0cjs, 2021-08-05:
The easiest way to debug this is to start 'scoping out the various lines (usually starting with clock, then address) if you have an oscilloscope available. If not, you're stuck with a logic probe or even just a voltmeter in which case removing chips for individual testing may be an easier way to go about things.

A few things you could try:
- You can (unreliably) reset the CPU by simply briefly shorting the reset pin to ground for a short period of time, so you might try that if you suspect your reset circuit.
- If you pull the 6502 and wire it up on a breadboard with pull-ups and pull-downs to put a NOP ($EA) on the data bus, you can look at the high address pins to see if they're toggling on and off at a constant rate (the A14 rate should be double the A15 rate, A13 double A14, and so on). The slower a clock you use, the more lines you can check by eye with just a logic probe or LED.
- You can pull the ROM and wire it up on a breadboard with various high/low inputs on the address pins and asserted select lines, and then check the data outputs to see that you're getting the values you expect.
- You can do the same with the RAM to write and read it, if you're careful.

liamoc, 2021-08-05:
Thanks for the advice! I have a scope arriving tomorrow so I will be able to do some poking around then.

liamoc, 2021-08-06:
I tried scoping out the clock pins on the CPU and they just seem to be high (but it was <5v, perhaps 3.3?). But then, while I was scoping it out, suddenly the power LED faded off and then I couldn't power the board anymore at all. The Arduino powers on just fine when not plugged into the board, but now absolutely nothing happens when I plug it in while attached to the board. What on earth just happened?

tebl, 2021-08-06:
My best guess for the power LED going out is that something is shorting it
out the power supply, might be causing the regulator on Arduino to go into
thermal shutdown. I think I'd try pulling all of the chips, then
reintroducing them one by one until the problem returns.

Don't know what kind of EPROM burner you have, but at least the MiniPro
does have the ability to test most logic chips.

fre. 6. aug. 2021, 17:27 skrev liamoc ***@***.***>:

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

liamoc, 2021-08-06:
Thanks for your advice. I removed all the chips, ardunio powered on and led powered on fully bright
added reset chip - same
added oscillator - same
added arduino io expander - same
added PIA - LED is half as bright, arduino power light goes on but doesn't seem to be actually starting.
removed PIA, added CPU - LED is extremely dim, arduino doesn't power on.
added PIA and CPU - LED is off, arduino doesn't power on.

0cjs, 2021-08-06:
For a start you should be using a voltmeter to check your power rails! This is the first thing you should always do (ideally, check the voltage and ground pins on each chip) and you should also do this whenever you take out or replace a chip. I probably should have mentioned this first thing in my earlier reply.

If adding a chip like the PIA or CPU causes a voltage drop of more than a tenth of a volt or so, pull all the other chips and try it again. If you still get the drop it's a bad chip; if you don't you may simply not be supplying enough power to the board. (Powering the entire board via USB _should_ be ok, since the board usually wants a total of around 250 mA and most powered USB ports should supply at least 500 mA, but there are some circumstances in which they will supply less.)

liamoc, 2021-08-06:
I checked the voltage when on USB power via the arduino (vcc to gnd on the 6502 pins) and it's negligible (<1V). I think the arduino is just not powering it at all (I did have USB power jumpered). In case powering via USB was the problem, I connected it to a solid 5v power from the backplane. Now the board powers up fine, but still the system isn't booting. I scoped out the clock lines and now it seems like we're getting a solid 1MHz clock, which is good.

I used the jumpers to disable the PIA, ROM and RAM. The CPU was showing activity. Then I enabled the ROM, and the address lines were as you described, with toggling. If I enable the RAM though, all address lines seem to be stuck high. The RAM chip doesn't seem to be faulty though (I tried replacing it with a fresh one, and no change).

As for the PIA, I don't really know how to scope that one out yet. I'll do more research.

0cjs, 2021-08-06:
If the system worked with the RAM _removed_, but failed with it in, that would point to a bad RAM chip. But that it works when the RAM is merely _disabled_, and the bus goes wonky when the RAM enable line is connected again points to possible issues with the address enable signals. Those are generated mainly by the 74LS138. Something like the RAM enable being stuck active (low), so that every read from the ROM or PIA ends up having the RAM respond as well, would seem to be consistent with the symptoms seen so far.
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
0cjs, 2021-08-07:
> The schematics seem to suggest that the 74LS138 chip isn't involved with the RAM at all?

Good catch! Yes, you're right (as well as showing that you're developing good debugging skills :-)). The RAM is mapped to all of the low 32 KB of address space, so one can just use `A15` as the select.

But if the RAM's `O̅E̅` and `C̅S̅` are always high it will never be enabled and so should never cause a problem. You'll note the `RAM_EN` jumper just connects those two directly to +5V or `CS_RAM` aka `A15`, so if things are ok when the jumper disables the RAM, and break when it connects the chip to `CS_RAM`, the problem must be in `CS_RAM`/`A15`. So I'd go over and re-debug that whole section again and see if changing the jumper really does change things. Perhaps the jumper wasn't properly connected when you thought you were jumpering `CS_RAM` to the chip; if the `O̅E̅` and/or `C̅S̅`  pins were left floating that would very likely cause problems (the chip might randomly spew on to the bus).

WRT the ROM bank jumpers, again those are ones that will cause problems if they're left floating, so make sure that the ROM's `A13` and `A14` pins are properly connected to Vcc or GND. (You can use a continuity tester on the unplugged board to verify this.) Assuming that's working properly, you'll of course get different behaviour at startup if you select a ROM bank with different code in it. I've been assuming you're using a ROM bank with WozMon in it (it starts `D8 58 A0 7F 8C 12 D0`...; this is in the listing in the Apple 1 manual). But you can of course play around with other code, and even burn your own test code into the EEPROM if you like. If you don't have a way to read the ROM, you can just plug the chip into a breadboard, wire up an address on the address pins, enable the chip by grounding `O̅E̅` and `C̅S̅`, and see what voltages come out the data pins. This is a nice little exercise even if you're not having problems, though obviously you're probably not going to want to read more than a dozen or two bytes this way.

liamoc, 2021-08-07:
I discovered that perhaps one or more of my chips simply wasn't seated well. I noticed that even with ROM jumpers on the right and the RAM jumpers enabled, i could get the "toggling" address behaviour sometimes on resetting but it would quickly go all-high when I touched it with my probe. Giving the chips a good push seems to have solved the "stuck high" problem. Connecting to the PIA via the arduino printed about 20 `/`, which I think was it attempting to print the prompt, and then it did echo my input! but as soon as i tried to print out a random memory address in wozmon it just spammed space characters (or tab?) into the stream. Ever since then, resetting hasn't produced any results at all (just as before..) but the cpu and ram and rom do seem to be working somewhat. I am beginning to strongly suspect the PIA.

0cjs, 2021-08-07:
If that was actually a backslash (`\`), that's the Wozmon prompt, yes. You should also be able to get that by typing an ESC (which clears the current input line), IIRC.

When things go wrong with (emulated) keyboard/screen input and output, remember you also can reset the Arduino. I've sometimes found on my system that it's the Arduino that's gotten messed up, not the SBC, and resetting just the Arduino brings me back to where I was with the microcomputer.

liamoc, 2021-08-07:
Sorry, yes, it was a backslash. I have managed to get it to reliably print a backslash on reset. But it still doesn't accept any input. Also, scoping the address lines while i do this, it will print the backslash and almost immediately afterward all the address lines go high again. I'm not sure what's causing this. I get about 1 second of working computer and then it crashes in this way. I'll try reseating all the chips again.

liamoc, 2021-08-07:
OK, I moved the CPU, ROM, arduino (+ io expander), reset and logic chips over to my second board that i soldered more recently, including the new PIA that just arrived. This combination of hardware now works perfectly.  So that leads me to conclude that it *must* be either the old PIA or the old board itself that is problematic. I will do more testing on the suspicious PIA, but I can close this issue now because I have a working machine again.

Thanks so much for all of your help!

0cjs, 2021-08-07:
> I will do more testing on the suspicious PIA...

It also might be worth beeping out the old board to see if anything's been broken or shorted on it, though from what caused the damage I would suspect a damaged chip myself.

Closed 2021-08-07.

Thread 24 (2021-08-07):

Case options?

liamoc, 2021-08-07:
Seeing as I may have broken my old PIA chip by turning my machine on while it was resting on a metal surface (see #23), I would like to make sure I never make the same mistake again. Are there any case options for the RC6502? I don't have a 3d printer or anything, but I might be able to get access to one. The RC2014 has some designs but I am not sure if they're compatible.

0cjs, 2021-08-07:
I've found that simply bolting 6mm standoffs into the holes at each corner has done a fine job of avoiding shorts. You might also consider insulating tape across the bottom of the board.

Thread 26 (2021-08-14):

Why is the peripheral clock (φ2out, bus pin 23) separate from the CPU clock (φ2in, bus pin 21)?

0cjs, 2021-08-14:
The 6502 has a φ2out pin (39) to allow access to the system clock when the internal oscillator is used. This doesn't seem necessary if an external oscillator is used since it can be fed to the 6502 φ2in pin (37) and also any peripherals that need a clock signal. At a quick glance this seems to be standard practice: the Apple 1, Apple II, Apple IIc and Acorn Electron for example leave CPU φ2out floating and send the same φ2 signal to the CPU and all other peripherals, if I'm reading the schematics right. (The Apple 1 is slightly confusing due to a third clock signal "φ0" on the expansion connector; it's not clear to me what that does, but it does not supply clock to the 6820.) Further, MOS themselves often did not provide a φ2out pin on variants supporting only external clock, including the (discontinued for legal reasons) 6501 and the Commodore 64's 6510.

Is there a particular reason that this design (on both the CPU board and the SBC) uses φ2out from the CPU for the peripherals rather than the same clock signal that's sent to the CPU? Or is it just what seemed right or obvious at the time? I have the feeling that this is incorrect (and also thus wasting one of the bus lines), but I do not know enough about this to be sure.

tebl, 2021-08-14:
I think it is mostly due to the RC6502 was my first attempt at building a
computer, but mostly based on the Apple1 Replica creation book while
attempting to make it fit as well as I could with the RC2014.

Apple1 had phi0 as the external clock source the CPU, buffered it is Phi1as
used internally by the CPU while delayed into Phi2 for external components.
The confusion does start to crop up when the later 65c02 came about as it
starts using the Phi1 clock in general instead, I assume because the static
design did not need the phase delay.

There's a significant chance I'm still mixing things up here, but I think
mostly I just put them there just in case I needed them later.

lør. 14. aug. 2021, 02:28 skrev Curt J. Sampson ***@***.***>:

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

0cjs, 2021-08-15:
From looking at the schematics, it doesn't look to me as if the Φ₂ output on the CPU was ever used. Here's how it works, as best as I can determine so far. (This is based only on the schematic from the back of the _Operations Manual_; I don't have any real boards or anything like that to look at.

1. Clock is generated on the video side and brought to the computer side at two places on the schematic, labeled `CL`.
2. One `CL` comes in the 74157 B7 at the upper left, goes down and right through the `"6502"` solder bridge pad in the 6800 clock area (surrounded by a dashed line and unused with a 6502) and up to the CPU, connecting to pins 36 (unused on 6502) and 37 (Φ₀ on MOS 6502,  Φ₂ in on W65C02, in either case the input for an external clock. The labelling beside the pin is a bit confusing, however, as it's `Φ₀,Φ₂` and pin 39 is indicated nowhere on the diagram, but connecting pin 37 and 39 is obviously incorrect, so I assume that pin 39 was just left floating, as you might well do with an unused output, and thus nothing is clocked from that.
3. That same `CL` line also goes down past the `"6502"` solder bridge pad to the `E` input (pin 25) of the 6820, indicating that's clocked by `CL`, and that also goes to the far right side of the diagram to the `Φ₂` pin on the expansion bus edge connector. There's also a `Φ₀` pin on that connector which is fed from the second `CL` box, so both `Φ₀` and `Φ₂` there are nearly same clock, only `Φ₂` is gated by the 74157 at the upper left and `Φ₀` isn't. (I don't know the reason for this off-hand.)

I trace through much of that above just to try to make sure that the pin 39 output isn't actually being used, and all peripherals use the same clock source that the CPU is using, rather than the CPU's output.

So I'm thinking that the replica should be doing the same thing, right?

0cjs, 2021-08-16:
I just dropped some probes on the bus pins of my SBC to see how pin 21 `Φ₂` (yellow), pin 19 `Φ₀` (cyan) and pin 23 `Φ₁` (pink) compare. It turns out there's nothing on bus pin 23, so I moved the probe to 6502 pin 3, where `Φ₁` out is obviously working. I'm guessing I might have missed something in my build, but I'm not really feeling like debugging it right this minute since it's not that important.

What is interesting is to look at the difference between the clock from the external generator on pin 21 and the output of the CPU (an old Rockwell NMOS part) on pin 19:

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

That is not nearly as good looking a clock; as well as the slow ramp-up it also for some reason doesn't quite come down to ground. (I carefully confirmed that both channels are using the same offset voltage/vertical setting, and both probes are taking their ground from a short wire crimped to a dupont connector on pin 17.) I suspect that this is more evidence that we should not be using the 6502's clock output (unless we were using its clock generator), but again, I'm not an expert on this stuff.

tebl, 2021-08-16:
I don't have any actual boards to look at either so I couldn't say either
way, but guides for 6502 seem to have it the same way so this may be a
difference from being a work-alike vs a direct replica.

Wozniak has shown a tendency to break the rules somewhat, mostly by having
complete control over the HW and working the minute specifics of it.

The important part of Phi2 is ensuring RAM (or other non-65xx chips) writes
are done when the address lines have stabilized, the signal in question is
itself is a slightly delayed version of Phi0 - so a delay elsewhere might
result in something that would still work the same way. Given that the
source of the clock is elsewhere, this also seems to solve the secondary
problem of buffering the clock. So he probably did not need it.

In practice, it might work as long as the timings match up correctly. The
scope view is interesting, but I suspect it is degrading somewhat due to a
small capacitor added to delay it - probably in part a reason why using the
same internal and external clock on pin 37 became the standard once the
65c02 and in particular the higher speeds of the WDC 65c02s came about
(going to static registers instead of dynamic ones might also be a factor
for why it was simplified).

søn. 15. aug. 2021, 16:24 skrev Curt J. Sampson ***@***.***>:

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

0cjs, 2021-08-17:
Hmm. Which guides are these? I got [this from 6502.org](http://forum.6502.org/viewtopic.php?t=6689#p85264):

> ...the system clock (phi2) with the W65C02 should be the same signal as is going to into Pin 37 of the CPU, not the Phi2O coming out of pin 39 as it was in the old NMOS days. In fact, in my experience the old NMOS systems work better this way too. At least they seem to overclock better.

Then again I see that [Grant Searle's design](http://searle.x10host.com/6502/Simple6502.html) has an external clock generator but feeds Φ₂out to the rest of the system. And I also had a look a the [VIC-20 schematic](http://www.zimmers.net/anonftp/pub/cbm/schematics/computers/vic20/index.html) and it too seems to use Φ₂out.

tebl, 2021-08-17:
Garth Wilson's 6502 primer is often the ones referred to on the 6502.org
forums, relevant sections:
http://wilsonminesco.com/6502primer/addr_decoding.html
http://wilsonminesco.com/6502primer/ClkGen.html

Apple1 Replica creation book:
https://www.applefritter.com/replica/chapter7

I agree that it is an outdated way of doing it, but it is an outdated
design which some may consider plugging very early chips into. The only
valid argument for keeping it this way, is that I consider the book to be
the documentation for it.

The board should perhaps have a wire selection for using the same clock as
the wdc 65c02 is mentioned on the silkscreen, but I never built a working
board with it. Would probably need a cleanup either way.

tir. 17. aug. 2021, 03:48 skrev Curt J. Sampson ***@***.***>:

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

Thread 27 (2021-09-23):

Nano Generated 1-MHz CPU Clock?

Mike-K8LH, 2021-09-23:
Couldn't the Nano provide the 1-MHz  CPU clock (running as a background task on the Nano)?  Example code snippet;

```
 /***************************************************************************
  *  output 1-MHz clock on OC2A (D11/PB3) for RC6502 SBC                    *
  ***************************************************************************/
  void beginClock()
  { pinMode(11,OUTPUT);             // OC2A (D11/PB3)
 /*                                                                         *
  *  TCCR2A settings for 'normal' or 'CTC' (non-PWM) mode                   *
  *  ------------------------------------------------------------           *
  *  COM2A1:COM2A0 '01' - Toggle OC2A on Compare Match                      *
  *  WGM22:WGM20  '010' - CTC mode (clear timer on compare match)           *
  *                       (WGM22 bit is in TCCR2B register)                 *
  *                                                                         */
    TCCR2A = ((1 << WGM21) | (1 << COM2A0));
    TCCR2B = (1 << CS20);           // prescale = 1:1 (WGM22 = 0)
    TIMSK2 = 0;                     // no interrupts
    OCR2A = 7;                      // match value
  }                                 // 0/1/3/7 => 8/4/2/1 MHz
 /***************************************************************************/
```

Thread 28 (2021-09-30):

555 Timer missing from BOM

StormTrooper, 2021-09-30:
The BOM on the readme you have listed for the  RC6502 Apple 1 SBC is missing the LM555 timer.

U6
LM555

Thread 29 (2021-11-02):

Wrong jumper info in documentation

ea4eoz, 2021-11-02:
Hello!

I'm currently building the SBC version and I have noticed a problem in the description of two of the jumpers

The documentation (readme.md) says:

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

In the revision H board it is just the opposite: Jumper open left pin 1 floating and jumper closed ties it to ground.

Another problem is with RAM Enable jumper:

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

In revision H board the jumper is placed vertically, so it must be placed in the upper pair to enable the RAM and in the lower pair to disable it.

Hope it helps. Greetings!

0cjs, 2021-12-07:
@ea4eoz Thanks for your report! I'm sorry I took so long to have a look at it. Feel free to have a look at PR #33 and see if that fixes your issues.

ea4eoz, 2021-12-11:
Yes, now it looks fine. Thank you!

0cjs, 2021-12-18:
@ea4eoz I'm glad to hear that the problem is fixed. You should close the issue to indicate that. (Because you created this issue, you'll see the "Close issue" button beside the "Comment" button underneath the comment box.)

ea4eoz, 2021-12-18:
Ups... I missed the close button.

Thank you!

Closed 2021-12-18.

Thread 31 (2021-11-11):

Stuck terminal and die

sergiomtzlosa, 2021-11-11:
Hi!

I am trying since a coupe of months to get the Apple1 SBC (Rev F) work but no luck, the terminal only shows "RC6502 apple 1 Replica" and got stuck, no prompt at all 😓

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

I made some checks on the capacitor and they are all fine, also I reflash the Arduino and the 8KB ROM onto the AT28C64 but still no luck, please can you point me some other checks to find the error out please?

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

Thanks and stay safe!

jhow0672, 2021-11-18:
What tripped me up most was the jumper pins - double-check those. The instructions weren’t too clear. I built a version “H” board which is a little different.  Also, used MCP23S17 not MCP23O17.

sergiomtzlosa, 2021-11-18:
@jhow0672 Thank yo so much !! I will dig on that a little deeper and I will let you know my results.

Regards

0cjs, 2021-12-07:
> Also, used MCP23S17 not MCP23O17.

Good catch on that: that's almost certainly the problem. According to the [datasheet][ds], the `S` version is an [SPI] interface, the `O` version is [I²C]. These are not compatible!

That chip not working as expected is consistent with the symptoms: you can see messages from the Nano itself (the `RC6502 Apple 1 Replica` banner) but, because the Nano can't talk to the I/O expander, it can't talk through it to the PIA and so cannot communicate with the 6502 CPU.

[ds]: https://ww1.microchip.com/downloads/en/devicedoc/20001952c.pdf
[SPI]: https://en.wikipedia.org/wiki/Serial_Peripheral_Interface
[I²C]: https://en.wikipedia.org/wiki/I%C2%B2C

sergiomtzlosa, 2021-12-07:
Hi!!

Thank you so much for this amazing inputs!!!! I change the MCP, but I still do not get thw WOZMon, I checked the capacitor, they seem fine, please can you give some advice about out to place the jumpers?

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

I also connect thru screen with this command: screen /dev/ttyUSB0 115200

Is the SPI speed correct?

Thanks

0cjs, 2021-12-07:
If you see the banner from the Nano when you reset it, you have the speed correct. Note that's not the SPI interface speed, that's the serial interface speed (on the "other side" of the Nano).

So you replaced the MCP23O17 with an MCP23S17? (I can't see in the photograph at that resolution.) And you did press the board's reset button after seeing the Nano's banner, right?

If youv'e done all that, and still see no `\` prompt or response to input (particularly Esc), the next step is to start probing the board, I suppose. Do you have an oscilloscope? If not, do you have a logic probe? I guess if worst comes to worst you can use a volt meter. My idea is to start by probing the keyboard input and screen output pins of the MC6821 to see if you see the right things there when pressing a key and from what the last character output by the computer should be.

sergiomtzlosa, 2021-12-07:
Hi @0cjs

I will do more deep reseach, I do not have an oscilloscope, just a volt meter....when I get some result I will be back

Thanks

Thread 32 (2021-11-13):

RC6502 VDU Color Amplifier - J4 OSC_EN Not connected?

StormTrooper, 2021-11-13:
On the schematic for the RC6502 VDU Color Amplifier, J4 (OSC_EN) is not connected to anything? Is this for a future feature or can it be removed?

tebl, 2022-02-01:
I assume you already found this out, but for posterity and those that might be looking for this answer at some point... J4 is a female pin header that matches up to some pin headers on the VDU board itself, it's existence is just a mechanical way of ensuring that these pin headers don't have a jumper on them.

Closed 2022-02-01.

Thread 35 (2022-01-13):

RC6502 Apple 1 SBC using MC68B21 causes unresponsiveness

denjhang, 2022-01-13:
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

denjhang, 2022-01-13:
Pressing the reset key on the sbc will bring up a "/", nothing happens to keyboard input, it seems to freeze.

denjhang, 2022-01-13:
Press the reset button on the arduino nano, "RC6502 Apple 1 Replica" will appear

0cjs, 2022-01-18:
The `RC6502 Apple 1 Replica` message is from the Nano, and that just indicates that the Nano is talking to the PC and thinks its talking to the SBC. Resetting that is entirely independent of resetting the SBC.

The `\` prompt is from the SBC; that's how WozMon says that you can start typing input. So if you're seeing that, you know that the Nano is reading the "screen" output from the SBC. If typing doesn't echo the characters you've typed (or a new prompt if you hit `Return` or `Esc`), it could be that your typing is not getting to the Nano, but more likely there's a problem with the connection between the Nano and the SBC's keyboard circuitry.

denjhang, 2022-01-19:
I've replaced a few sets of chips and the situation is still the same, it doesn't seem to be a chip problem. Can anyone tell me what to do?

denjhang, 2022-01-19:
I've replaced a few sets of chips and the situation is still the same, it doesn't seem to be a chip problem. Can anyone tell me what to do?

0cjs, 2022-01-20:
I guess the next step might be to put a 'scope or logic probe on the "keyboard" outputs from the Nano to the PIA and make sure it's toggling those lines when you type at the console?

denjhang, 2022-01-30:
At the moment I found out that the cause is a bug caused by corrupted SRAM.

explit7, 2023-11-23:
I have exact the same Problem. Will try to replace the RAM

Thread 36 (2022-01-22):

Trouble with programming arduino

C-JESTER01, 2022-01-22:
Hello,
I recently bought a kit through https://retrotechlyfe.com and I had accidentally formatted the preprogrammed arduino that came with the kit. I would like some help figuring out which sketch I need to upload to the arduino, since the seller will not release any info.

Board Rev: H
Controller: Arduino Nano
Chip: ATmega328p

Thanks to who ever decides to help me out!

tebl, 2022-01-22:
You will find it at
https://raw.githubusercontent.com/tebl/RC6502-Apple-1-Replica/master/software/arduino/PIA%20Communicator/pia_communicator/pia_communicator.ino

lør. 22. jan. 2022, 05:51 skrev C-JESTER01 ***@***.***>:

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

C-JESTER01, 2022-01-22:
That is the program I found however, when I put it into the arduino IDE, it
fails to compile. Any tips?

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

tebl, 2022-01-22:
I think you'd need to be a bit more specific, which error are you getting?
Preferably the stack trace itself.

Usually it's just a missing library, but it's been a while since I last
looked at it - so there might've been changes somewhere.

lør. 22. jan. 2022, 21:51 skrev C-JESTER01 ***@***.***>:

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

C-JESTER01, 2022-01-22:
Yes it was missing MCP23S17.h, even though it was included. I changed the
path in the program and then it said it was unable to be compiled for that
board. Even though it is an Arduino Nano

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

C-JESTER01, 2022-01-22:
Give me a half hour to pull the error for you

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

C-JESTER01, 2022-01-22:
Arduino: 1.8.19 (Windows 10), Board: "Arduino Nano, ATmega328P"

C:\Users\Hunter\AppData\Local\Temp\ccCysob2.ltrans0.ltrans.o: In function `global constructors keyed to 65535_0_pia_communicator.ino.cpp.o.1987':

<artificial>:(.text.startup+0x64): undefined reference to `MCP23S17::MCP23S17(SPIClass*, unsigned char, unsigned char)'

C:\Users\Hunter\AppData\Local\Temp\ccCysob2.ltrans0.ltrans.o: In function `configure_bridge':

C:\Users\Hunter\Desktop\PIAV2\pia_communicator/pia_communicator.ino:41: undefined reference to `MCP23S17::begin()'

C:\Users\Hunter\Desktop\PIAV2\pia_communicator/pia_communicator.ino:45: undefined reference to `MCP23S17::pinMode(unsigned char, unsigned char)'

C:\Users\Hunter\Desktop\PIAV2\pia_communicator/pia_communicator.ino:47: undefined reference to `MCP23S17::pinMode(unsigned char, unsigned char)'

C:\Users\Hunter\Desktop\PIAV2\pia_communicator/pia_communicator.ino:51: undefined reference to `MCP23S17::pinMode(unsigned char, unsigned char)'

C:\Users\Hunter\AppData\Local\Temp\ccCysob2.ltrans0.ltrans.o: In function `output_status':

C:\Users\Hunter\Desktop\PIAV2\pia_communicator/pia_communicator.ino:59: undefined reference to `MCP23S17::readPort(unsigned char)'

C:\Users\Hunter\AppData\Local\Temp\ccCysob2.ltrans0.ltrans.o: In function `pia_send':

C:\Users\Hunter\Desktop\PIAV2\pia_communicator/pia_communicator.ino:104: undefined reference to `MCP23S17::writePort(unsigned char, unsigned char)'

C:\Users\Hunter\AppData\Local\Temp\ccCysob2.ltrans0.ltrans.o: In function `serial_transmit':

C:\Users\Hunter\Desktop\PIAV2\pia_communicator/pia_communicator.ino:156: undefined reference to `MCP23S17::readPort(unsigned char)'

collect2.exe: error: ld returned 1 exit status

exit status 1

Error compiling for board Arduino Nano.

This report would have more information with
"Show verbose output during compilation"
option enabled in File -> Preferences.

tebl, 2022-01-22:
Have not tested it, but it seems that the library class has changed name -
try my older copy of the library at
https://github.com/tebl/RC6502-Apple-1-Replica/tree/master/software/arduino/PIA%20Communicator/lib/MCP23S17
.

Alternatively, you can try changing the text MCP23S17 in the sketch to MCP
(excluding the include statement at the top). It might work, but then again
I do not know how much has been altered other than then name.

lør. 22. jan. 2022, 23:37 skrev C-JESTER01 ***@***.***>:

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

C-JESTER01, 2022-01-23:
Arduino: 1.8.19 (Windows 10), Board: "Arduino Nano, ATmega328P"

pia_communicator:24:31: error: no matching function for call to
'MCP23S17::MCP23S17(SPIClass*, int, int)'

 MCP23S17 bridge(&SPI, IO_SS, 0);

                               ^

In file included from C:\Users\Hunter\Desktop\RC6502-Apple-1-Replica-master
- Copy\software\arduino\PIA
Communicator\pia_communicator\pia_communicator.ino:2:0:

C:\Users\Hunter\Documents\Arduino\libraries\MCP23S17/MCP23S17.h:31:3: note:
candidate: MCP23S17::MCP23S17(uint8_t, uint8_t)

   MCP23S17(uint8_t select, uint8_t address = 0x00);

   ^~~~~~~~

C:\Users\Hunter\Documents\Arduino\libraries\MCP23S17/MCP23S17.h:31:3:
note:   candidate expects 2 arguments, 3 provided

C:\Users\Hunter\Documents\Arduino\libraries\MCP23S17/MCP23S17.h:30:3: note:
candidate: MCP23S17::MCP23S17(uint8_t, uint8_t, uint8_t, uint8_t, uint8_t)

   MCP23S17(uint8_t select, uint8_t dataIn, uint8_t dataOut, uint8_t clock,
uint8_t address = 0x00);

   ^~~~~~~~

C:\Users\Hunter\Documents\Arduino\libraries\MCP23S17/MCP23S17.h:30:3:
note:   candidate expects 5 arguments, 3 provided

C:\Users\Hunter\Documents\Arduino\libraries\MCP23S17/MCP23S17.h:27:7: note:
candidate: constexpr MCP23S17::MCP23S17(const MCP23S17&)

 class MCP23S17

       ^~~~~~~~

C:\Users\Hunter\Documents\Arduino\libraries\MCP23S17/MCP23S17.h:27:7:
note:   candidate expects 1 argument, 3 provided

C:\Users\Hunter\Documents\Arduino\libraries\MCP23S17/MCP23S17.h:27:7: note:
candidate: constexpr MCP23S17::MCP23S17(MCP23S17&&)

C:\Users\Hunter\Documents\Arduino\libraries\MCP23S17/MCP23S17.h:27:7:
note:   candidate expects 1 argument, 3 provided

C:\Users\Hunter\Desktop\RC6502-Apple-1-Replica-master -
Copy\software\arduino\PIA
Communicator\pia_communicator\pia_communicator.ino: In function 'void
output_status()':

pia_communicator:59:37: error: 'class MCP23S17' has no member named
'readPort'; did you mean 'read8'?

   debug_value("Video D0-D6", bridge.readPort(IO_VIDEO) & 127);

                                     ^~~~~~~~

                                     read8

C:\Users\Hunter\Desktop\RC6502-Apple-1-Replica-master -
Copy\software\arduino\PIA
Communicator\pia_communicator\pia_communicator.ino: In function 'void
pia_send(int)':

pia_communicator:104:12: error: 'class MCP23S17' has no member named
'writePort'; did you mean 'write8'?

     bridge.writePort(IO_KBD, c | 128);

            ^~~~~~~~~

            write8

C:\Users\Hunter\Desktop\RC6502-Apple-1-Replica-master -
Copy\software\arduino\PIA
Communicator\pia_communicator\pia_communicator.ino: In function 'void
serial_transmit()':

pia_communicator:156:21: error: 'class MCP23S17' has no member named
'readPort'; did you mean 'read8'?

     char c = bridge.readPort(IO_VIDEO) & 127;

                     ^~~~~~~~

                     read8

exit status 1

no matching function for call to 'MCP23S17::MCP23S17(SPIClass*, int, int)'

I am now getting this error. I see that it suggests to change some commands
to a different one (Like readPort to read8). Should I try that or did I
mess something else up?

Thank you for your help thus far

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

countach22, 2022-02-28:
I am getting the same error while trying to verify/compile the PIA Communicator Sketch. I have tried this on two different windows machines and a mac.  Has anyone figured out the source of the error yet?  Thanks.

Arduino: 1.8.19 (Mac OS X), Board: "Arduino Nano, ATmega328P"

PIA_Communicator_old:26:31: error: no matching function for call to 'MCP23S17::MCP23S17(SPIClass*, int, int)'
 MCP23S17 bridge(&SPI, IO_SS, 0);
                               ^
In file included from /Users/Erik/Documents/Arduino/PIA_Communicator_old/PIA_Communicator_old.ino:4:0:
/Users/Erik/Documents/Arduino/libraries/MCP23S17/MCP23S17.h:31:3: note: candidate: MCP23S17::MCP23S17(uint8_t, uint8_t)
   MCP23S17(uint8_t select, uint8_t address = 0x00);
   ^~~~~~~~
/Users/Erik/Documents/Arduino/libraries/MCP23S17/MCP23S17.h:31:3: note:   candidate expects 2 arguments, 3 provided
/Users/Erik/Documents/Arduino/libraries/MCP23S17/MCP23S17.h:30:3: note: candidate: MCP23S17::MCP23S17(uint8_t, uint8_t, uint8_t, uint8_t, uint8_t)
   MCP23S17(uint8_t select, uint8_t dataIn, uint8_t dataOut, uint8_t clock, uint8_t address = 0x00);
   ^~~~~~~~
/Users/Erik/Documents/Arduino/libraries/MCP23S17/MCP23S17.h:30:3: note:   candidate expects 5
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

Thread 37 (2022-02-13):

Problems getting color VDU working

StormTrooper, 2022-02-13:
I've built a color VDU and double checked all the connections and soldering joints.
When I plug it all in I get either a red screen of G's or red G's with some random green characters.

This seems to suggest at least the video chip is working. I've tested all logic chips and also tested the 62256 ram chip - no issues there.

Have swapped out the MC1372 and MC6847 just in case, but made no difference.

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

Any ideas as to where to start troubleshooting on this?

The RC6502 is running fine and I can connect to the console via the Arduino and run basic programs.

0cjs, 2022-06-05:
In case it's not clear (because I think another [another user](https://github.com/tebl/RC6502-Apple-1-Replica/issues/42) may also have been unclear on this), the VDU board simply gives you a frame buffer in memory: you are responsible for writing the software that intialises it, prints text on the screen, and so on. Especially, the Apple 1 monitor (WOZMON) normally used with this system will _not_ print anything on this display; the Apple 1 video system is very different from this, and does not even involve a frame buffer. (Apple 1 video is more like a terminal.)

StormTrooper, 2022-06-05:
Thanks, very useful info linked above. I haven't had any time to further investigate this but that will be the cause then - no software has been done to initialize the VDU board.

Will close this issue as it's a lot clearer now.

Closed 2022-06-05.

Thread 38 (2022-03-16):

Wrong IC label on Serial IO Board

nebanks, 2022-03-16:
U3 on the Serial IO Board is labeled on the schematic (and the silkscreen) as 74HCT38. It should definitely be 74HCT**1**38.

0cjs, 2022-06-05:
I've just checked my two-year-old PDF copy of the schematic and [the latest exported schematic][sch]
and in both cases it's marked `74HCT138`. It's also correct in this (five year old) [exported image of the board][img]. Can you tell us exactly which file you're looking at, which commit it came from, and confirm that the problem still exists in the latest commit?

[sch]: https://github.com/tebl/RC6502-Apple-1-Replica/blob/master/RC6502%20Apple%201%20SBC/export/RC6502%20Apple%201%20SBC.pdf
[img]: https://github.com/tebl/RC6502-Apple-1-Replica/blob/master/RC6502%20Apple%201%20SBC/gallery/2017-07-09%2015.17.02.jpg

nebanks, 2022-06-05:
Again, you are looking at the SBC, and not the Serial I/O Board schematic. The schematics I'm looking at are always the most current ones in the Git repo. This particular one is listed as "Rev B:"

[https://github.com/tebl/RC6502-Apple-1-Replica/blob/master/RC6502%20Serial%20IO/export/RC6502%20Serial%20IO.pdf](url)

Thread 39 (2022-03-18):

Electrolytic Capacitor missing from Serial Board BOM

nebanks, 2022-03-18:
On the schematic there's a 10nF electrolytic capacitor - C5 - that doesn't appear on the BOM. Also, the silkscreen on the board for C5 is the one used for bypass caps (i.e., it looks like brackets [ ] ) instead of the round polarized symbol you'd normally expect.

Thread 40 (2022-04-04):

WD65C02 Does not work with CPU Module

nebanks, 2022-04-04:
The schematic and the silkscreen for the CPU Module PCB list U1 as "WD65C02." That is just the one processor that WILL NOT WORK with the CPU module; the BE pin on the CPU module is left unconnected, but must be pulled high in order for the WD65C02 to work.

0cjs, 2022-06-05:
On my oldish copy of the schematic (no newer than 2020-01-10) pin 36 of U1 is marked `BE` and is connected to VCC through a 3.3k resistor, R10. I've also just checked the [latest exported schematic][sch] and, though it's very different in layout, it also has the same pull-up on that pin. Perhaps you have a (very) old copy of the schematic? At any rate, telling us exactly what file from which commit you are looking at would be very helpful.

(Unfortunately the schematic revision indication doesn't seem to be getting bumped with new revisions; both mine and the latest one above say "Rev: B" though they are clearly different. @tebl, maybe you can try to remember to update that when you update the schematic?)

[sch]: https://github.com/tebl/RC6502-Apple-1-Replica/blob/master/RC6502%20Apple%201%20SBC/export/RC6502%20Apple%201%20SBC.pdf

nebanks, 2022-06-05:
Hi Curt,

I think you are talking about the SBC, which does have the required pull-up resistor. I'm talking about the CPU module. The current schematic is marked "rev B."

0cjs, 2022-06-05:
Right, I think now perhaps you're seeing why it would be very helpful for you to _specify the file you're looking at,_ rather than just saying things like "CPU module." You might get a much faster response on these bugs if you'd do that.

nebanks, 2022-06-05:
The name if the file is CPU module.

0cjs, 2022-06-05:
Well I am interested in fixing things like this in the repo; you'll see I have close to a dozen commits in there already. However, I'm not interested in working on issues from people who insist that they're being clear when refusing even to give a proper filename (there is no file in the entire repo named `CPU`) or link to the GitHub page for that file.

I'm guessing you're talking about some file under the `RC6502 CPU/` directory, but I can't be bothered to try to chase down which one you were looking at. (Keep in mind that the Gerber exports, PDF exports and image files may not contain the same information as the schematic files or each other, for example.)

I'm unsubscribing from this issue; I hope you find someone to fix it for you.

nebanks, 2022-06-05:
You do realize that the RC6502 is a *modular backplane computer* that happens to have a self-contained SBC module? Each module has a separate directory named "CPU" for the CPU module, "Serial I/O" for the Serial I/O module, etc. The schematic for the CPU module - which is named "CPU" - can be found, as you astutely surmise, in the "CPU" subdirectory. (In fact, in the "export" sub-subdirectory, the same as every other schematic for every other part of the project.) This issue has been "fixed" by me, in the sense that I soldered a pull-up resistor between BE and  VCC on the CPU board. No one else I've talked to about this has had any trouble getting the point, including TEBL himself. I guess it's up to him if he wants to change the design so that BE is not left floating.

Sorry if you're having a bad day, or whatever, but I'm not giving you my lunch money.

tebl, 2022-06-05:
Yes, you are right - the modular boards have not seen much work as I've
gotten distracted by other things (currently at the hospital with a 3 day
old baby, but on the best of days I am not healthy enough to work
consistently). These projects are on a hobby basis and require voluntary
contributions such as the one Curt is providing by ensuring that most can
get a response.

I have a different version of the CPU module on my desk somewhere that adds
the missing resistor, but I need to test it before putting it out as there
was a bit of rerouting done. So it is somewhere in the future plans, I just
need to work up to being allowed to have separate plans 😅

søn. 5. jun. 2022, 17:06 skrev nebanks ***@***.***>:

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

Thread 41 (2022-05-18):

Trouble with programming Atmega328p with CP2102 usb to ttl module

BinaryBark27, 2022-05-18:
hello,
I need to program the Atmega328p with a USB to TTL module (cp 2102). my module does not have a DTR pin and I am not able to program using it. whenever I try programming the atmega chip it displays an error stating that "attempt 10 of 10,  not in sync".

please can anyone help me with this?

tebl, 2022-05-19:
If you have an Arduino Uno with a socketed chip you can program a new chip
in the socket by using an ICSP programmer such as USBtinyISP. Alternatively
you can build it up on a bread board and program it via a regular Arduino (
https://www.electronicshub.org/burn-bootloader-on-atmega328/).

If you have an EPROM Programmer such as Minipro TL866, you can add
bootloader using it as well (hex file is buried somewhere in Arduino IDE
installation).

ons. 18. mai 2022, 21:09 skrev BinaryBark27 ***@***.***>:

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

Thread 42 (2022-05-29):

IMO it lacks some detailed info (or a tutorial)

giobbino, 2022-05-29:
Hi all,
I found this awesome project and I decided to give it a try; I bought the needed PCBs on PCBway and I'm waiting for them.
However, sice I don't want to depend on my PC (using Putty etc.) I was trying to understand how to connect a (PS/2?) keyboard and a composite monitor. I got the SBC, backplane, VDU and vdu adapter boards.

I can't find any info about that. Is there any tutorial, page, youtube video about that?

cheers from Brazil :-)

0cjs, 2022-06-05:
If what you're looking for is simple setup for a terminal you can type at, using a VDC board on this system is probably not the way to go. It seems there's a fair bit of work to be done here, possibly more than you'd care to take on at your current level of expertise. There are several issues here.

First, I am guessing (I've not used it) that the 6847 VDU should display text just fine so long as you put the right character codes into the frame buffer memory. However, you'd need software to do this, including keeping track of the cursor position, scrolling the screen, handling control characters, and so on. The Apple 1 monitor (WOZMON) typically used with this board does not have any code to support anything like this; you'd need to write your own character output routines. (The Apple 1 video design is _very_ different from this design.) You can look at the BIOSes of many different 1980s microcomputers (the Apple II BIOS is one example) to get a sense of how this code should work. It's not terribly difficult, but it's not a beginner project.

Second, there's no keyboard interface here for PS/2 keyboards as far as I'm aware, or really any interface that's "officially" for a keyboard. One relatively easy option (if you have the technical skill and familiarity with how these things work) is to grab whatever matrix-based keyboard you might have handy, hook it up to a [6820 or similar PIA][pia] (you could even re-purpose the one already on the SBC for this if you don't mind losing the interface to the Arduino Nano) and use that to scan the keyboard in traditional '80s style. Again, lots of old BIOSes have code for this, and I even happen to have recently [reverse-engineered the C16 keyboard hardware and software][c16], which should give a pretty decent sense of how these things work. (Again, if you have sufficient technical skills to understand what's going on there.)

If you're not up to doing this level of work, I'd strongly suggest you stick with the SBC's basic configuration of having the Arduino Nano emulate the screen and keyboard hardware of the original Apple 1. You can then use that system to learn what you need to know to develop a video display and keyboard system. You might start by going through the Apple 1 WOZMON listing and Apple 1 or SBC schematic and learning how all that works; if that doesn't seem reasonably simple to you yet, you're probably not (yet!) at the technical level to be writing code to handle running a text video display.

[pia]: https://en.wikipedia.org/wiki/Peripheral_Interface_Adapter
[c16]: https://gitlab.com/retroabandon/cbm/-/blob/master/c16/keyboard.md

0cjs, 2022-06-05:
Also, it would be nice if someone could change the title of this issue to something more descriptive, such as "How can I use a text video display and keyboard on the system?" The current title is going to be rather mysterious when it comes up in response to someone searching the issues.

giobbino, 2022-06-05:
> Also, it would be nice if someone could change the title of this issue to something more descriptive, such as "How can I use a text video display and keyboard on the system?" The current title is going to be rather mysterious when it comes up in response to someone searching the issues.

that was the easiest part :D

giobbino, 2022-06-05:
> If what you're looking for is simple setup for a terminal you can type at, using a VDC board on this system is probably not the way to go. It seems there's a fair bit of work to be done here, possibly more than you'd care to take on at your current level of expertise. There are several issues here.

Thank you for your (rather good!) explanation. I was maybe too naive supposing it was an Apple I clone/replica with the CRT terminal output too. I also supposed it  could be possible to hook up a ps/2 keyboard through the Arduino Nano. My fault, should have studied the project better. Probably I was too impulsive, since I haven't enough skill to code at such low level.

Oh, well, maybe somebody in the future will develope some CRT and keyboard routines...

0cjs, 2022-06-05:
I should mention that using the Nano serial interface is very close to using an original Apple 1 anyway. As I mentioned, the Apple 1's display is basically a (_very_) dumb terminal: you write a character to the 6820 output port B and the display circuitry picks that up and prints it. The only control character it knows is ASCII CR (carriage return) which moves the cursor to the start of the next line; you cannot even backspace or clear the screen. Input from the keyboard is similar: you read from port A of the PIA and get an ASCII character generated by the keyboard. So using a serial terminal is basically no different at all, as far as the software is concerned, and very little different if you run your terminal emulator in a 40×24 window on your PC. (I suppose you could program the Nano or some other microcontroller to generate a video display and read a physical keyboard, doing the same emulation of the Apple 1's video/keyboard hardware to the 6850, but I don't see a whole lot of point to that.)

The "BIOS" (WOZMON) provide any support for I/O from/to any other devices (there's no room for that in 256 bytes!), so most Apple 1 software is going to use those screen output and keyboard input routines or just directly read and write the hardware in the same way that WOZMON does.

So if you're just looking to run Apple 1 programs, you already have a system that's basically the same as the real thing; just set your terminal window to 40×24. Anything beyond that is going to involve programming (the Apple 1 pretty much was a, "here's the hardware, write whatever software you need" system), which is also essentially what using a contemporary machine was like.

giobbino, 2022-06-05:
Got it. What I wrongly expected was an emulation of a CRT terminal by the VDU, to avoid the use of a PC software... more or less something like the Hansel's Altair 8800 clone and the VDM-1 emulator ([https://github.com/dhansel/VDM1/blob/master/README.md]).

In my mind the Apple 1 was no much more than an Altair with an embedded CRT terminal output, a tape recorder port, a keyboard interface and some ROM, and of course without the Altair front panel.
Must to be said the Hansel's project comes with a big bunch of software on an SD card that in the '70s you must to load teletype "typing" the bootloader by the panel switches; however when you've loaded the software (i.e. the Altair Basic), it runs on the CRT terminal (I mean: the composite or VGA output).

However I wish to stress that I'm not complaining about this project; obviously it was my mistake about what I expected vs. what the project offers.

I will build it and try to dig a little more and see if I'll be able to learn something more about it  :-)
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
giobbino, 2022-06-08:
In first, I wish to say I really appreciate your big effort to clarify me the doubts I had (and still partially have). It took a good time to write such a clear and detailed explanation. Many, many thanks for that!!!

It seems to me the TX and RX pins from the Nano are present on the backplane (pin #36 and #37) so, unless if you use another module that rely on these signals (I didn't check all the modules so I don't know if there are any), a VT-100 clone could be made to fit the backplane connector. This way you can have an on-board terminal (keyboard and VGA/composite video out) and, if needed, the VDU module (how to use the VDU isn't clear to me yet, though).

I understand I can't have a 100% emulation of the original Apple I; but I love to build standalone things that don't rely on other pieces of hardware. Just to explain why I'm trying to avoid to hook up it to a PC - that would be the easier and more reasonable approach, of course :-)

giobbino, 2022-06-12:
I'm wondering if an easier (and cheaper) way could be an ESP32, like the TTGO module - [example](https://www.aliexpress.com/item/33014937190.html) with the [FABGL libraries](https://www.github.com/fdivitto/fabgl) by Fabrizio Di Vittorio, that also come with terminal class and samples.

One could use the small ESP32 module only and build a PCB to fit the backplane, adding PS2 and VGA (or composite?) output, or simply buy the whole module shown in the above link, with all the needed connectors, and link it by wire to the Arduino TX/RX pins.

The ESP32 has an embedded wifi module that could (maybe) used for uploading software from PC/internet through the serial port.

Am I missing something?

0cjs, 2022-06-13:
Easier and cheaper than what? The [uTerm](https://hackaday.io/project/165325-uterm) seems to do pretty much what you want, [the PCB](https://www.pcbway.com/project/shareproject/uTerm__a_VT100_like_terminal_for_the_Z80_MBC2_.html) is $5, the STM chip it uses is about $2, and IIRC the rest of the BOM is a few dollars or so (though in my case it's all parts that I already had in my parts box).

Anyway, though the SBC is called a "replica," I think it's more accurate to call it a "clone": it gives effectively the same functionality as an Apple 1, but while the computer side of it is essentially the same design with different details (static RAM and more modern decoding), the video/keyboard side is a completely different implementation that gives similar functionality on a serial terminal, rather than a video display.

giobbino, 2022-06-13:
> Easier and cheaper than what? The [uTerm](https://hackaday.io/project/165325-uterm) seems to do pretty much what you want, [the PCB](https://www.pcbway.com/project/shareproject/uTerm__a_VT100_like_terminal_for_the_Z80_MBC2_.html) is $5, the STM chip it uses is about $2, and IIRC the rest of the BOM is a few dollars or so (though in my case it's all parts that I already had in my parts box).

Great advice, I didn't know the uTerm project. In term of cost, I was comparing the ESP32 vs. the Geoff's VT-100-like ASCII terminal; it uses a PIC32 that's quite expensive (~25-30 USD, considering shipping to Brazil, plus PCB etc), while an ESP32 costs less than 20 USD including shipping.

The uTerm seems quite cheaper too, maybe just a little more expensive than an ESP32; the shipping fee for PCB and STM32 chip is the worst part, but I have all the remaining components.

I already own a spare ESP32 to play a bit, but I think I will follow your advice and build a uTerm board. Thank you!

tebl, 2022-10-11:
Yes, I think FabGL would definitely be a way to go and I've had a
browser-tab open for it for two years hoping to get around to it 😅

The RC6502 was mainly my starting point, building a lot of extra modules
that never had much in common with Apple 1 beyond what I wanted to build
for the fun of it. Besides the Arduino bits I've built things more from a
starting point of browsing old books and picking projects that way.

At the rate I'm going I'll probably have lost my remaining strands of hair
before I get around to more current technology, other than to suggest it
would be a fun project for anyone interested in such things - sounds like
an excellent opportunity for learning 😀

søn. 12. jun. 2022, 18:26 skrev giobbino ***@***.***>:

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

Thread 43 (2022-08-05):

Problem while using joystick as mouse

BinaryBark27, 2022-08-05:
the code I copied from the Arduino IDE website is showing an error. showing"MOUSE not defined"
I have even included the MOUSE library

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

here is the code

#include <Mouse.h>

/*
  JoystickMouseControl

  Controls the mouse from a joystick on an Arduino Leonardo, Micro or Due.
  Uses a pushbutton to turn on and off mouse control, and a second pushbutton
  to click the left mouse button.

  Hardware:
  - 2-axis joystick connected to pins A0 and A1
  - pushbuttons connected to pin D2 and D3

  The mouse movement is always relative. This sketch reads two analog inputs
  that range from 0 to 1023 (or less on either end) and translates them into
  ranges of -6 to 6.
  The sketch assumes that the joystick resting values are around the middle of
  the range, but that they vary within a threshold.

  WARNING: When you use the Mouse.move() command, the Arduino takes over your
  mouse! Make sure you have control before you use the command. This sketch
  includes a pushbutton to toggle the mouse control state, so you can turn on
  and off mouse control.

  created 15 Sep 2011
  updated 28 Mar 2012
  by Tom Igoe

  This example code is in the public domain.

  https://www.arduino.cc/en/Tutorial/BuiltInExamples/JoystickMouseControl
*/

#include <Mouse.h>

// set pin numbers for switch, joystick axes, and LED:
const int switchPin = 2;      // switch to turn on and off mouse control
const int mouseButton = 3;    // input pin for the mouse pushButton
const int xAxis = A0;         // joystick X axis
const int yAxis = A1;         // joystick Y axis
const int ledPin = 5;         // Mouse control LED

// parameters for reading the joystick:
int range = 12;               // output range of X or Y movement
int responseDelay = 5;        // response delay of the mouse, in ms
int threshold = range / 4;    // resting threshold
int center = range / 2;       // resting position value

bool mouseIsActive = false;    // whether or not to control the mouse
int lastSwitchState = LOW;        // previous switch state

void setup() {
  pinMode(switchPin, INPUT);       // the switch pin
  pinMode(ledPin, OUTPUT);         // the LED pin
  // take control of the mouse:
  Mouse.begin();
}

void loop() {
  // read the switch:
  int switchState = digitalRead(switchPin);
  // if it's changed and it's high, toggle the mouse state:
  if (switchState != lastSwitchState) {
    if (switchState == HIGH) {
      mouseIsActive = !mouseIsActive;
      // turn on LED to indicate mouse state:
      digitalWrite(ledPin, mouseIsActive);
    }
  }
  // save switch state for next comparison:
  lastSwitchState = switchState;

  // read and scale the two axes:
  int xReading = readAxis(A0);
  int yReading = readAxis(A1);

  // if the mouse control state is active, move the mouse:
  if (mouseIsActive) {
    Mouse.move(xReading, yReading, 0);
  }

  // read the mouse button and click or not click:
  // if the mouse button is pressed:
  if (digitalRead(mouseButton) == HIGH) {
    // if the mouse is not pressed, press it:
    if (!Mouse.isPressed(MOUSE_LEFT)) {
      Mouse.press(MOUSE_LEFT);
    }
  }
  // else the mouse button is not pressed:
  else {
    // if the mouse is pressed, release it:
    if (Mouse.isPressed(MOUSE_LEFT)) {
      Mouse.release(MOUSE_LEFT);
    }
  }

  delay(responseDelay);
}

/*
  reads an axis (0 or 1 for x or y) and scales the analog input range to a range
  from 0 to <range>
*/

int readAxis(int thisAxis) {
  // read the analog input:
  int reading = analogRead(thisAxis);

  // map the reading from the analog input range to the output range:
  reading = map(reading, 0, 1023, 0, range);

  // if the output reading is outside from the rest position threshold, use it:
  int distance = reading - center;

  if (abs(distance) < threshold) {
    distance = 0;
  }

  // return the distance for this axis:
  return distance;
}

tebl, 2022-08-05:
I can't offer any specific advice as this probably isn't related to the
RC6502 computer, especially since mice were mostly unknown in the era of
computers that it belongs to. From having tinkered with similar things, the
specific error you're experiencing might simply be that you're trying to
use the library with an MCU that does not include USB-host capability
(Arduino Uno, Nano etc) while you instead need something like an Arduino
Pro Micro or Arduino Leonardo.

fre. 5. aug. 2022 kl. 15:59 skrev BinaryBark27 ***@***.***>:

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

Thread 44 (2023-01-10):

SBC6502 Apple 1 Replica

Technican, 2023-01-10:
I have build the Apple 1 Replica, the Arduino UNO and the ROM works correctly. But if i use the Terminal (RS232) i see only dots. Do i need other boards to work with it? Is there a way to use the Terminal for Programming the SBC6502?

Rewards Sven.

Suchatavi, 2023-01-10:
Sent from my iPhoneOn Jan 10, 2023, at 6:57 AM, Technican ***@***.***> wrote:
I have build the Apple 1 Replica, the Arduino UNO and the ROM works correctly. But if i use the Terminal (RS232) i see only dots. Do i need other boards to work with it? Is there a way to use the Terminal for Programming the SBC6502?
Rewards Sven.

—Reply to this email directly, view it on GitHub, or unsubscribe.You are receiving this because you are subscribed to this thread.Message ID: ***@***.***>

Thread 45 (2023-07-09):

Serial IO BOM for Rev B board

CygnusTM, 2023-07-09:
The BOM on the Serial IO board page needs to be updated for the Rev B board. There is a capacitor count difference, and there is a missing diode. I had to go to the schematic to figure out the right parts to install.

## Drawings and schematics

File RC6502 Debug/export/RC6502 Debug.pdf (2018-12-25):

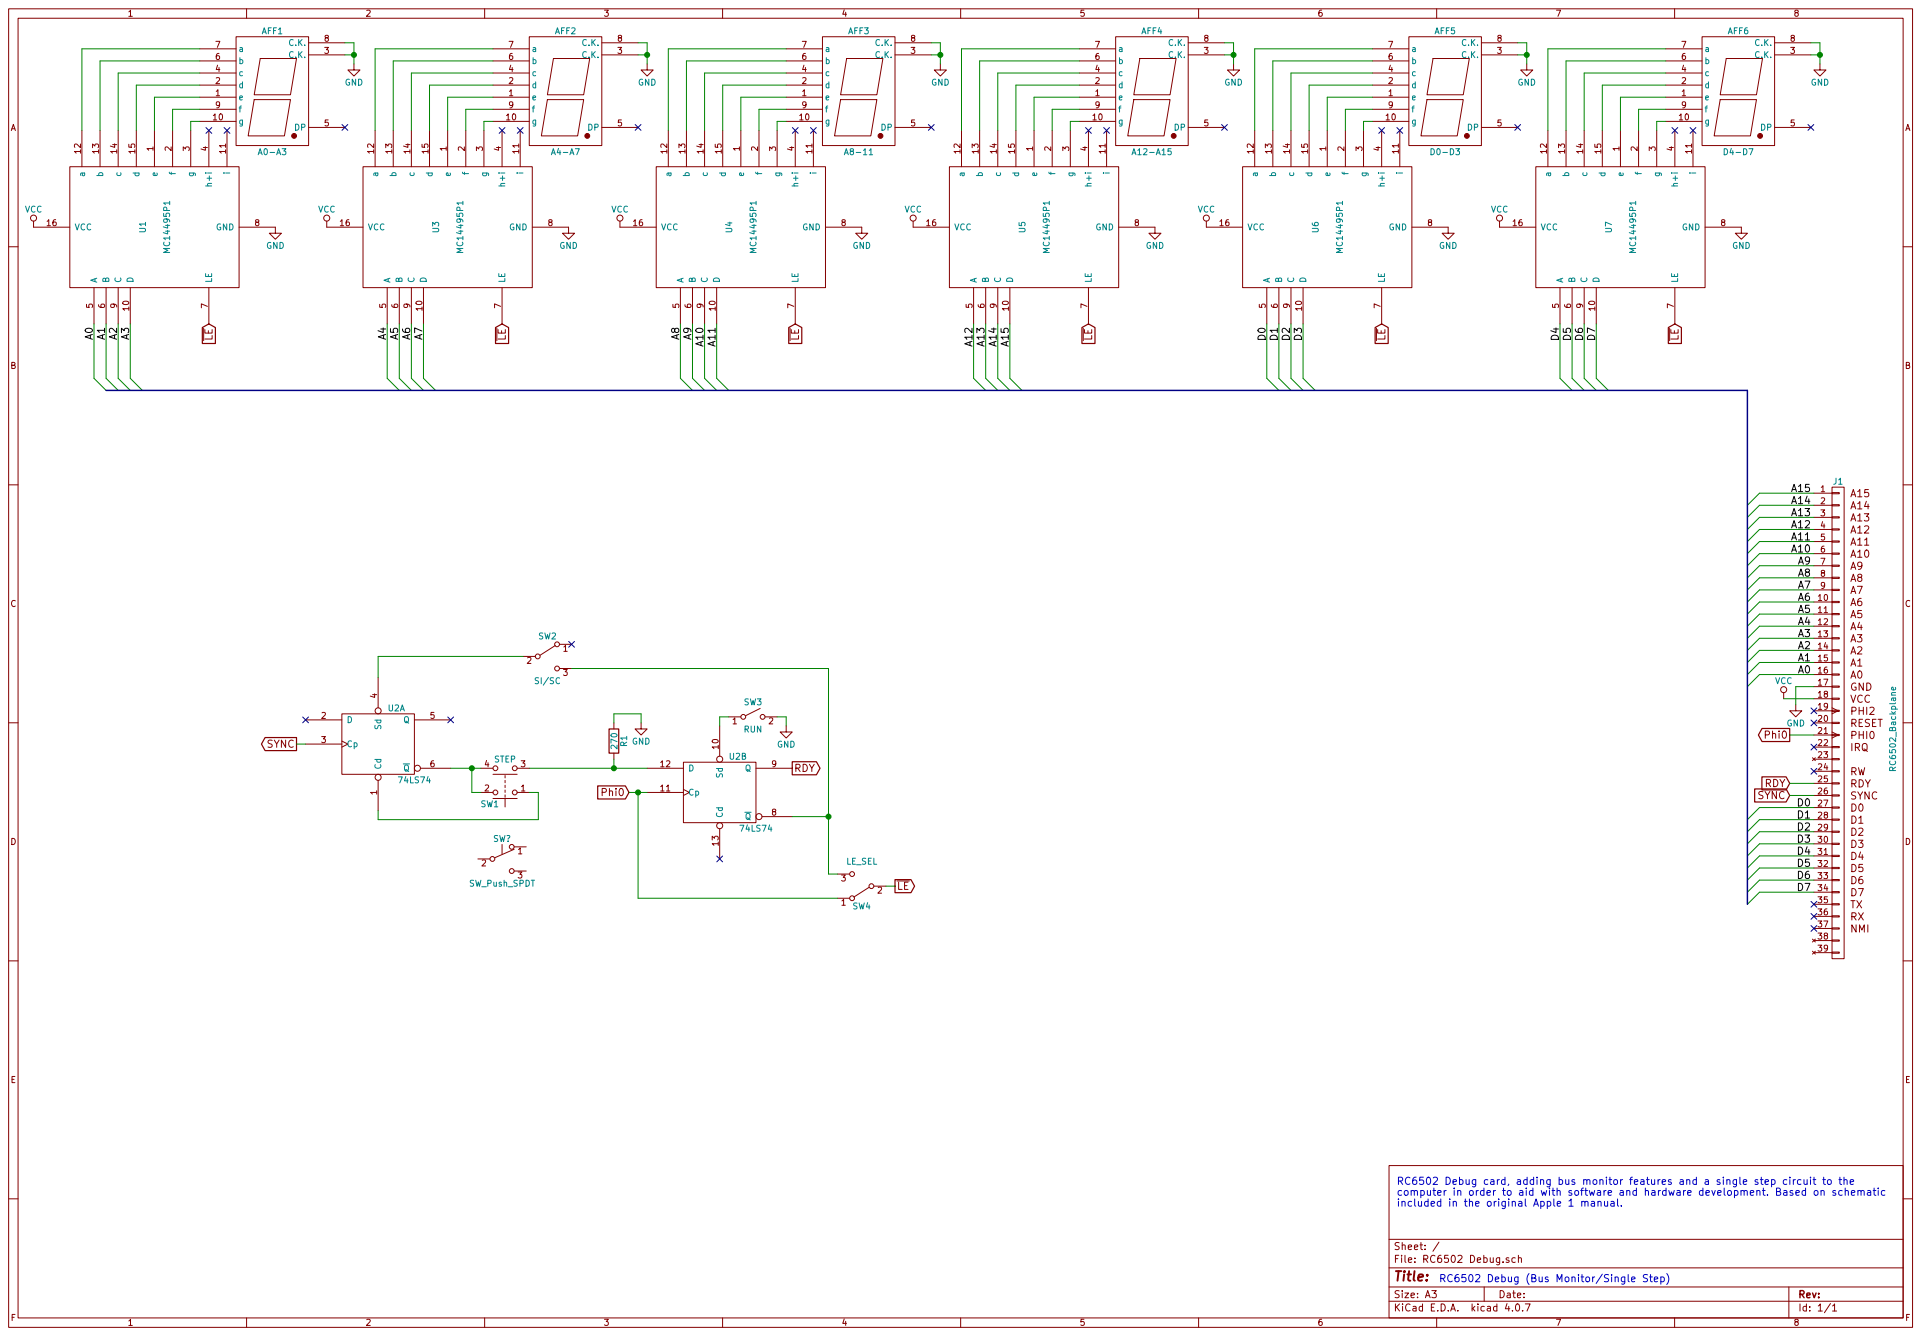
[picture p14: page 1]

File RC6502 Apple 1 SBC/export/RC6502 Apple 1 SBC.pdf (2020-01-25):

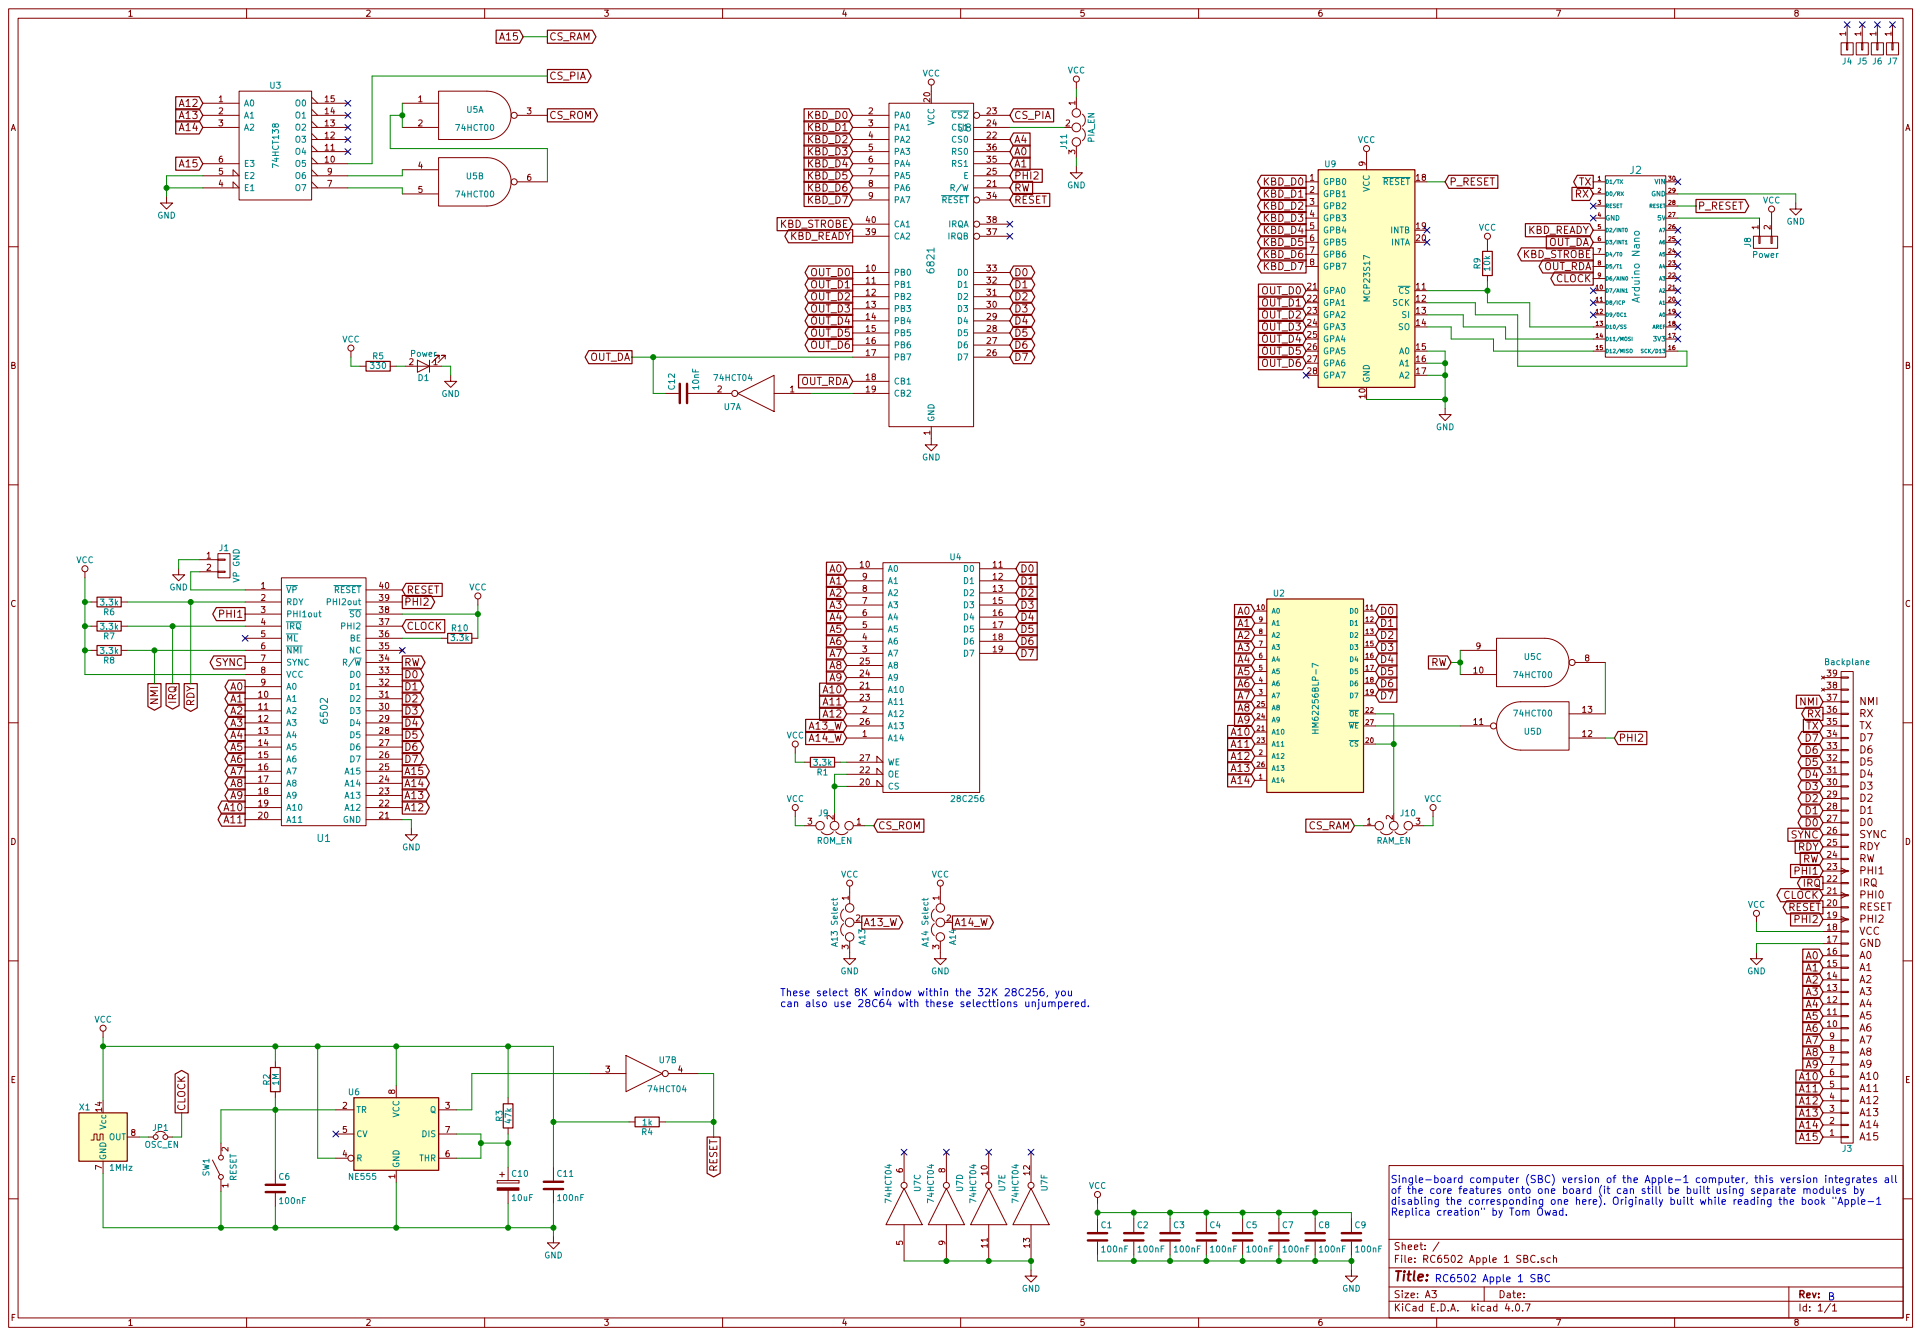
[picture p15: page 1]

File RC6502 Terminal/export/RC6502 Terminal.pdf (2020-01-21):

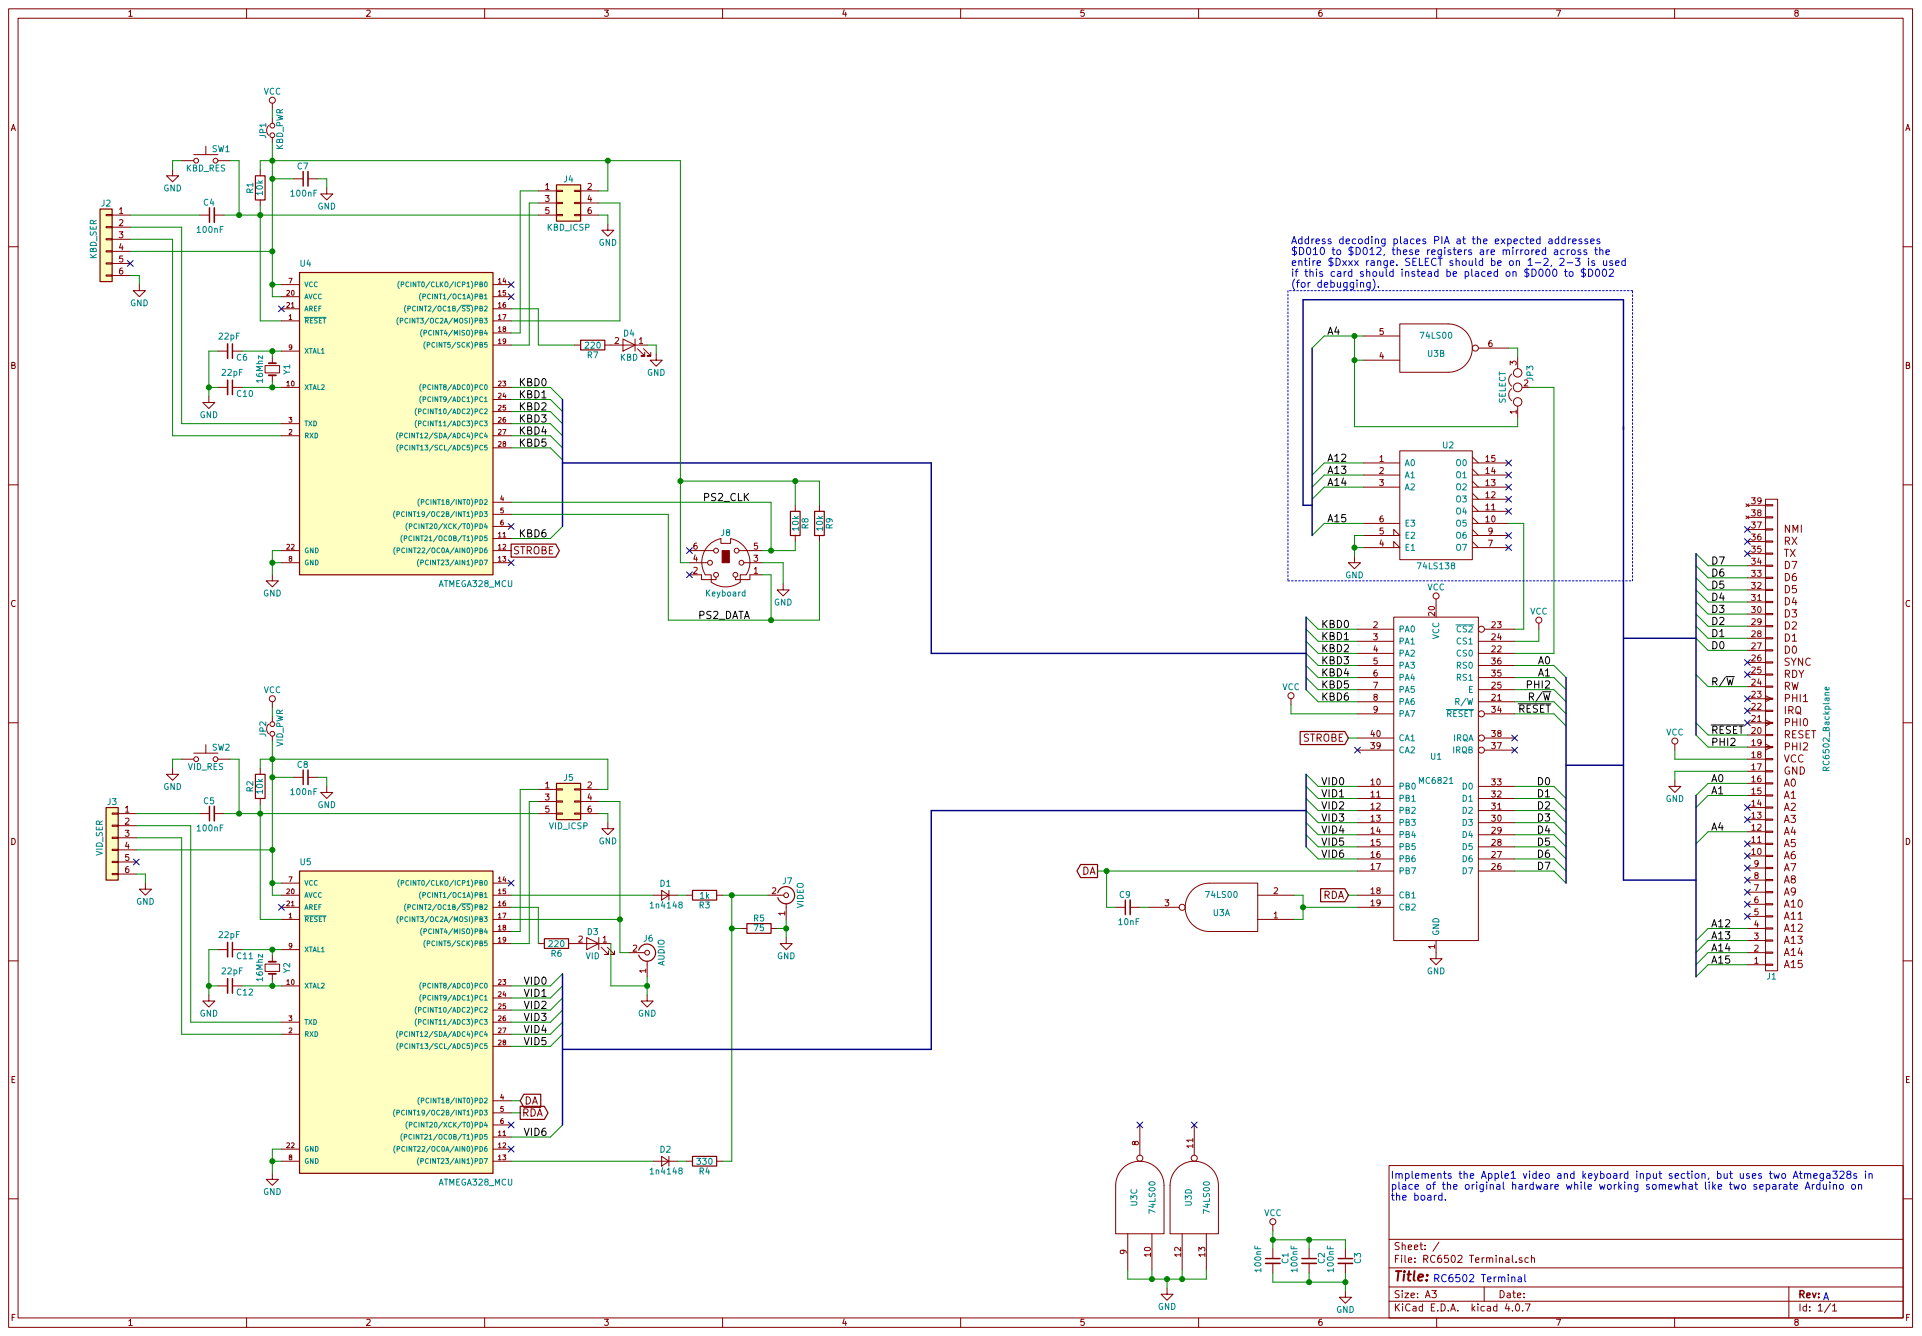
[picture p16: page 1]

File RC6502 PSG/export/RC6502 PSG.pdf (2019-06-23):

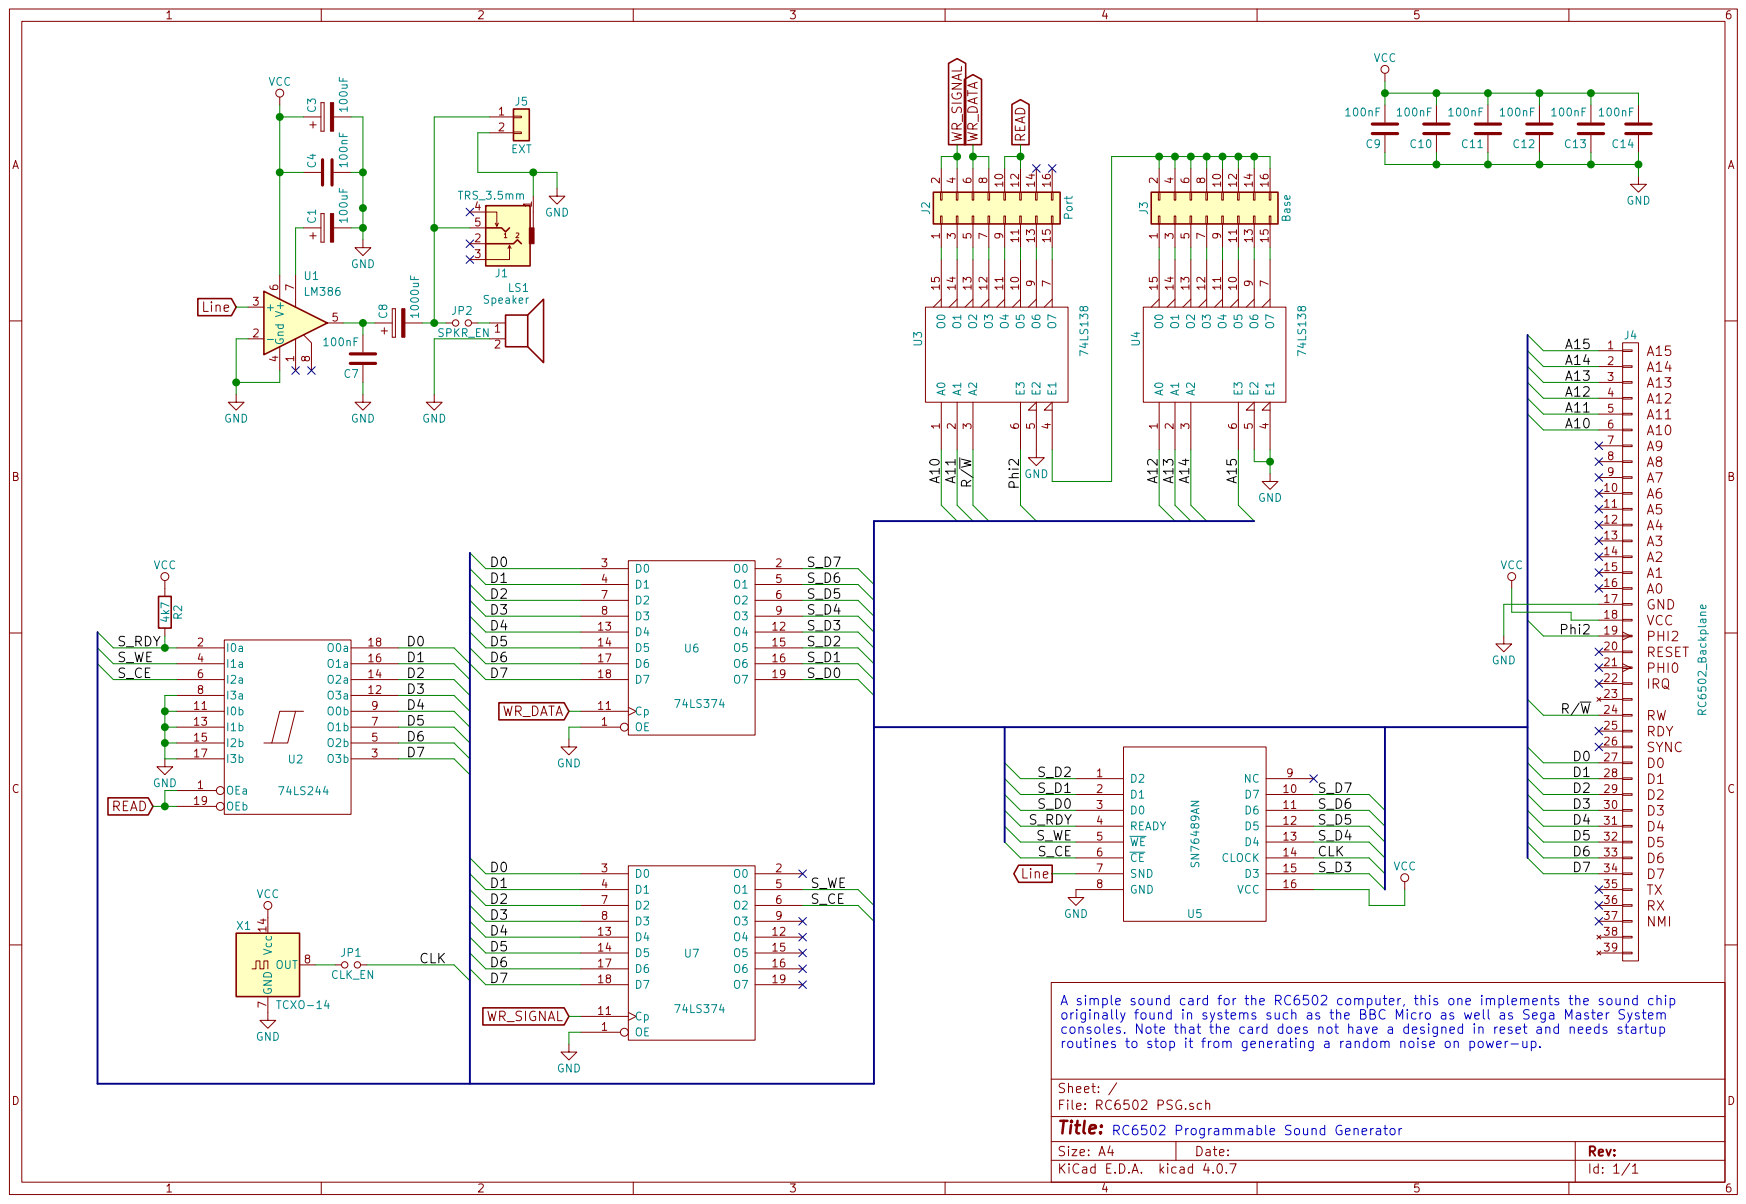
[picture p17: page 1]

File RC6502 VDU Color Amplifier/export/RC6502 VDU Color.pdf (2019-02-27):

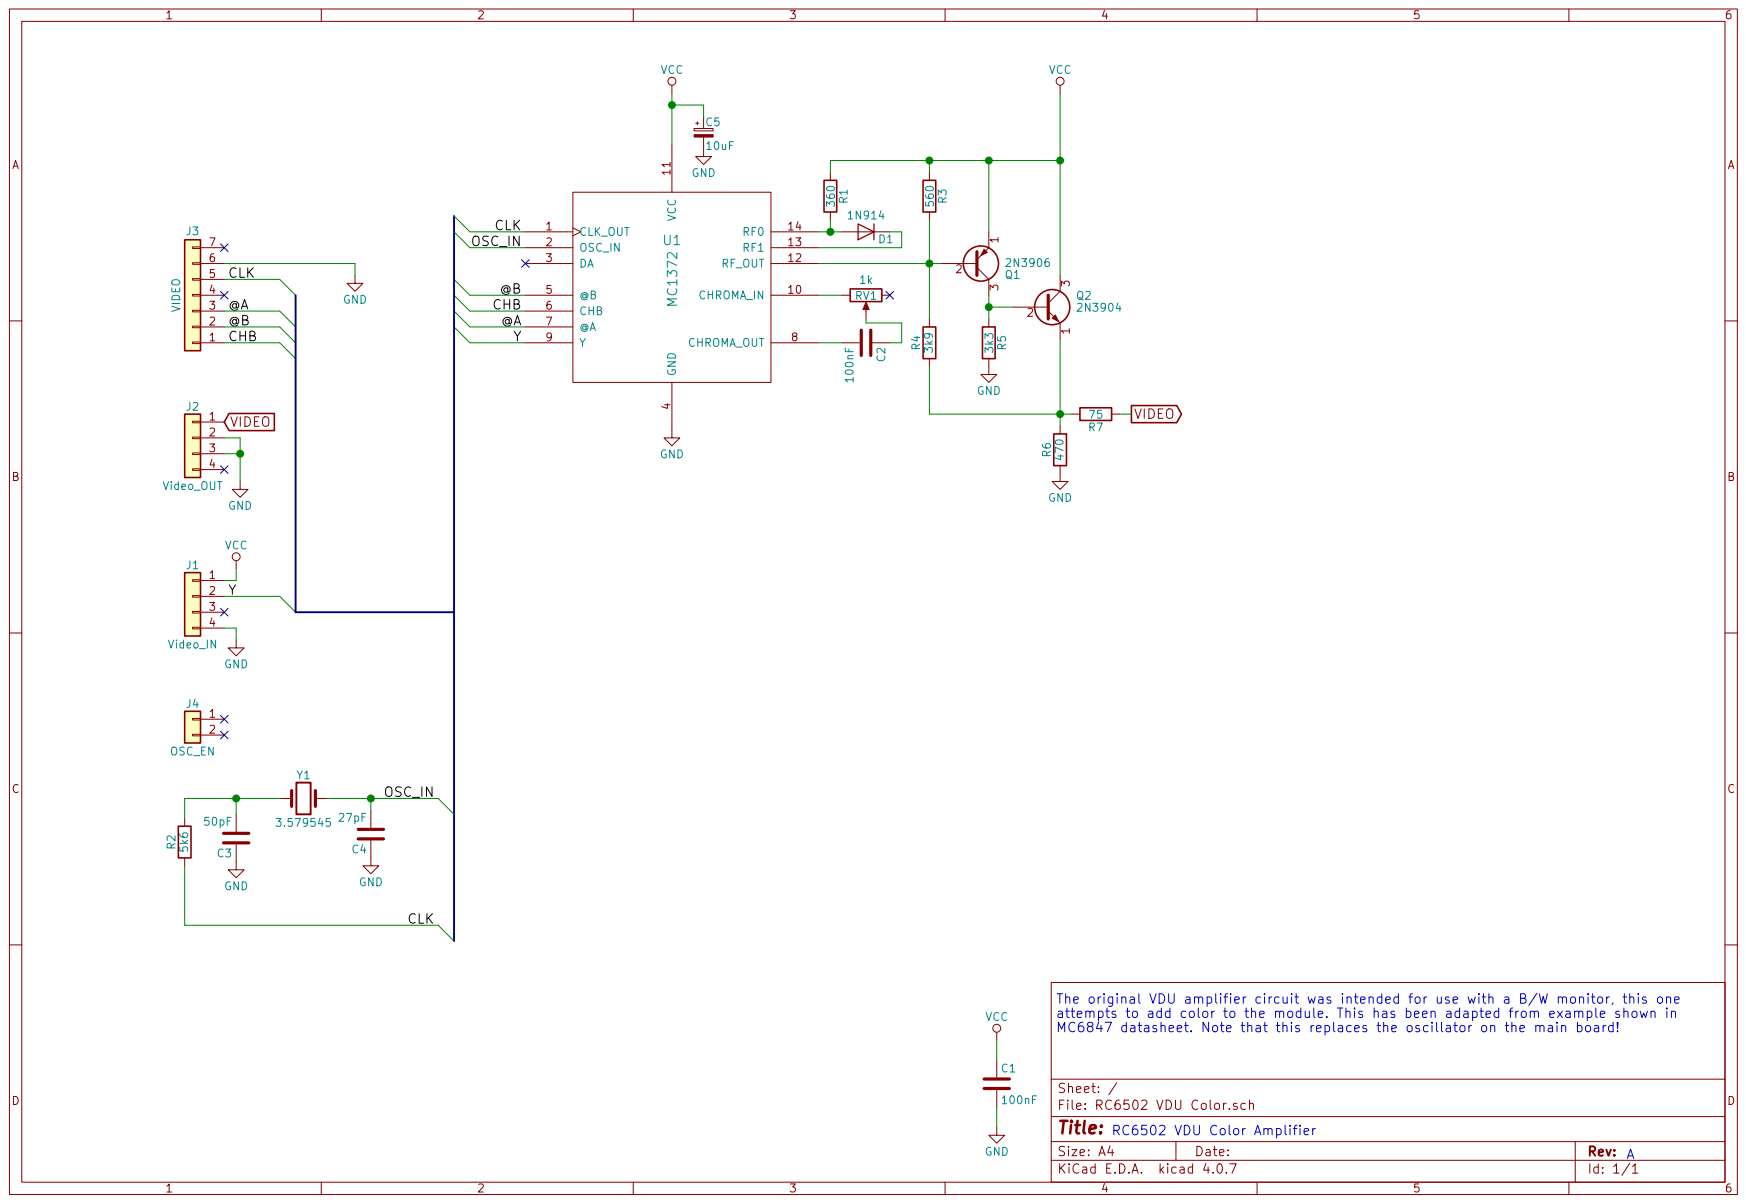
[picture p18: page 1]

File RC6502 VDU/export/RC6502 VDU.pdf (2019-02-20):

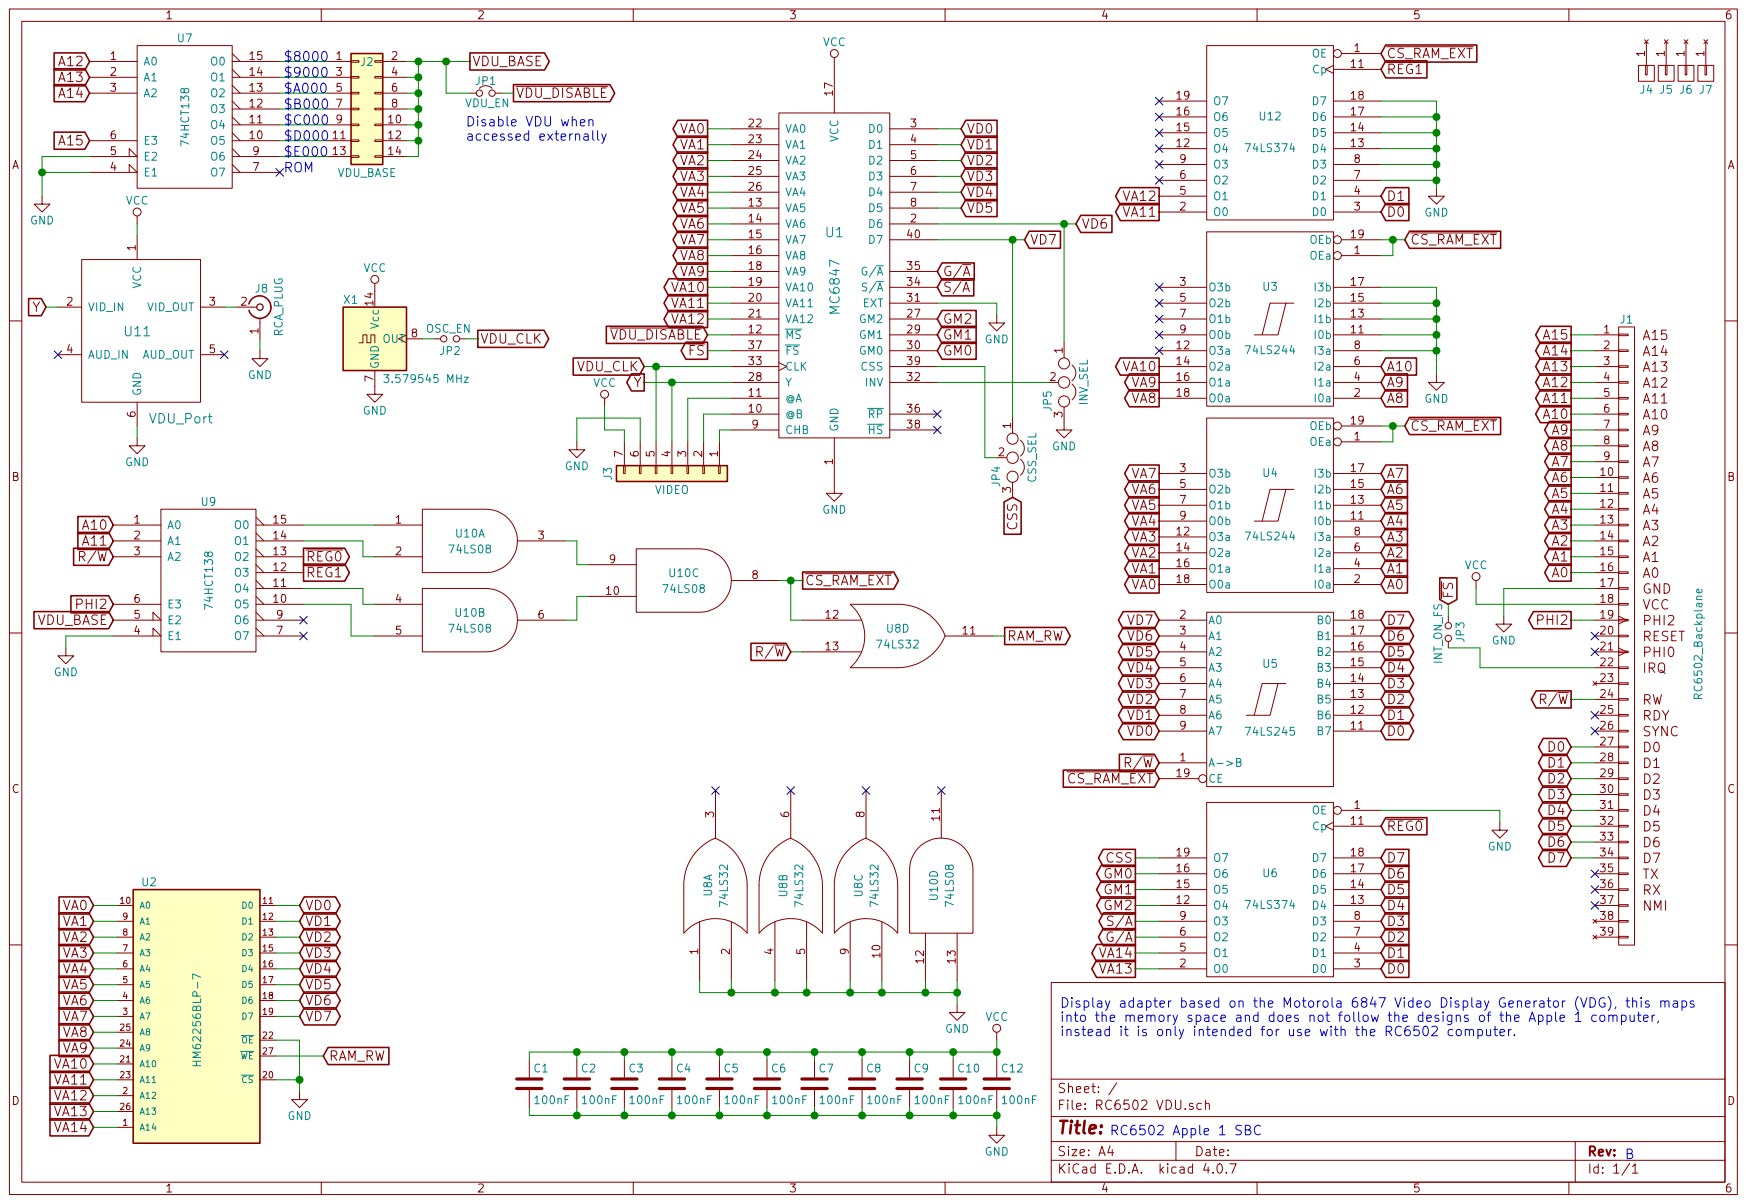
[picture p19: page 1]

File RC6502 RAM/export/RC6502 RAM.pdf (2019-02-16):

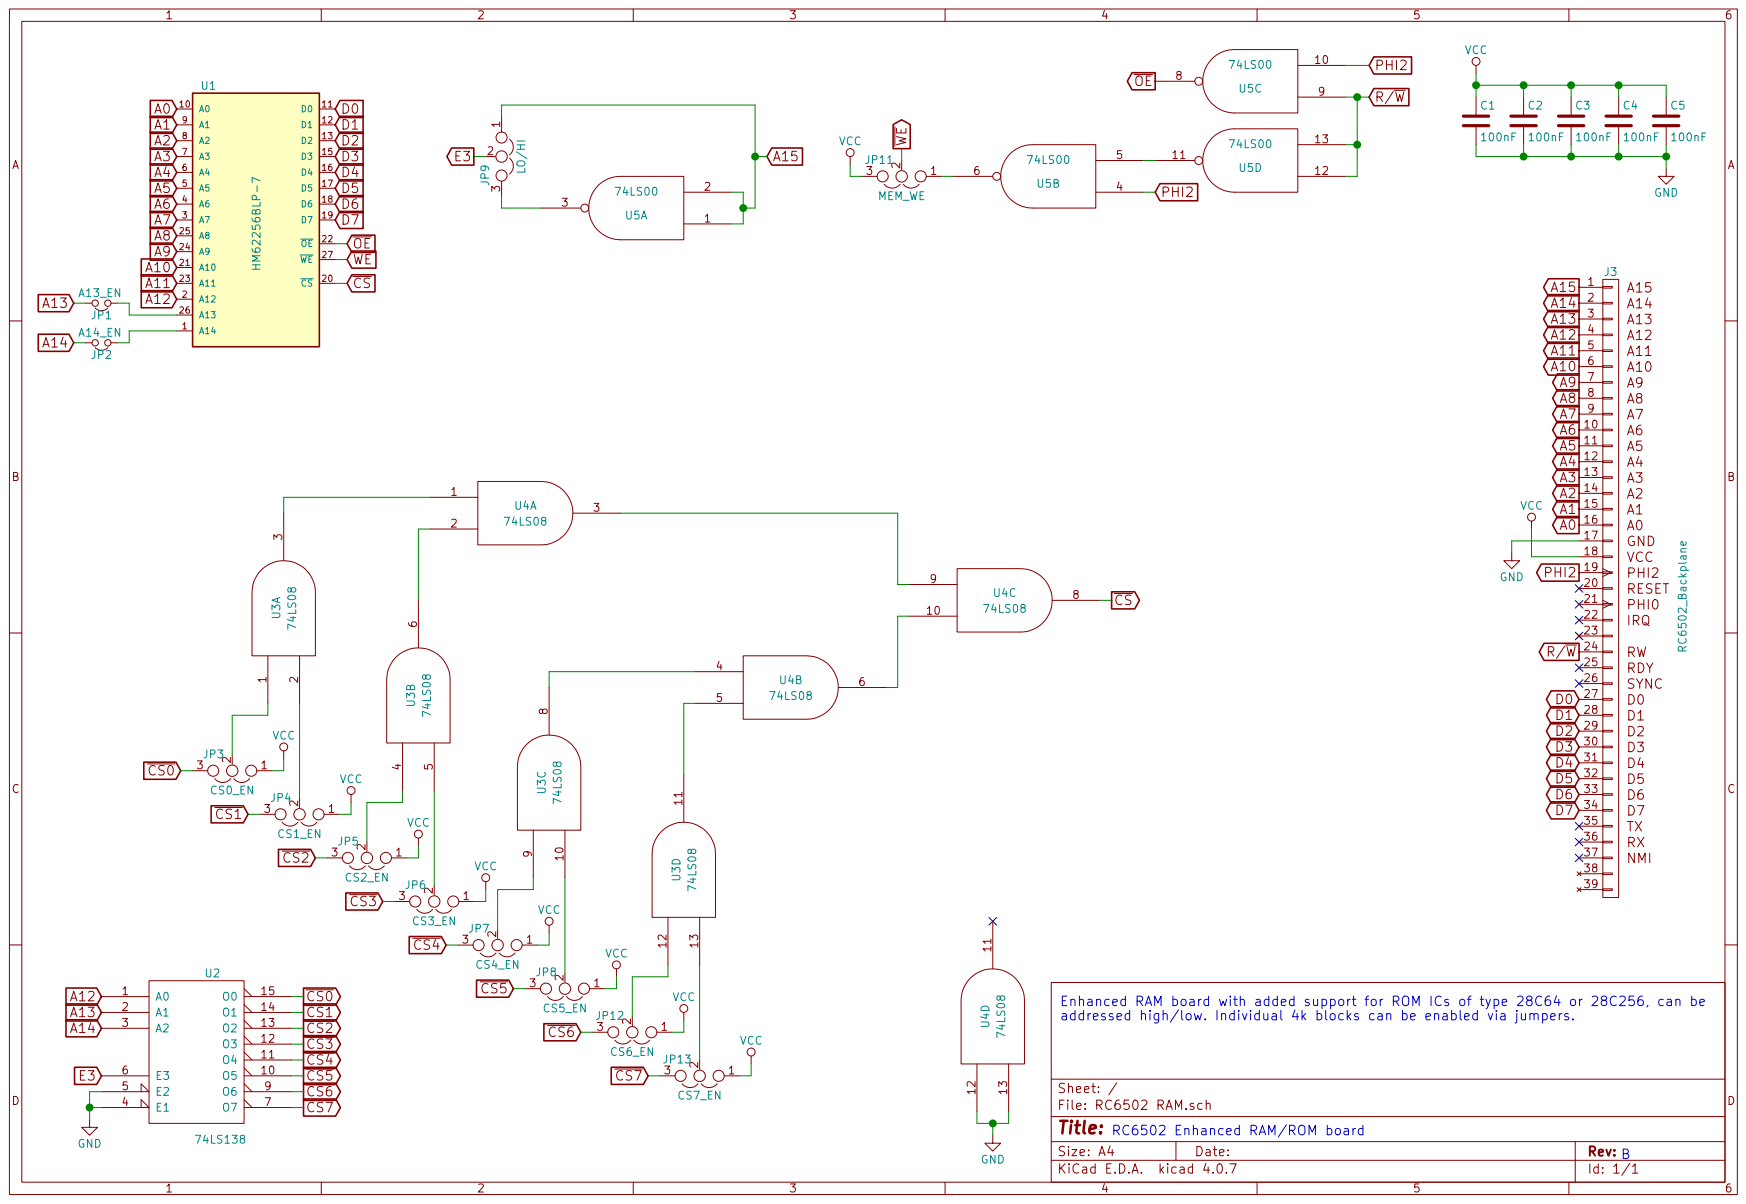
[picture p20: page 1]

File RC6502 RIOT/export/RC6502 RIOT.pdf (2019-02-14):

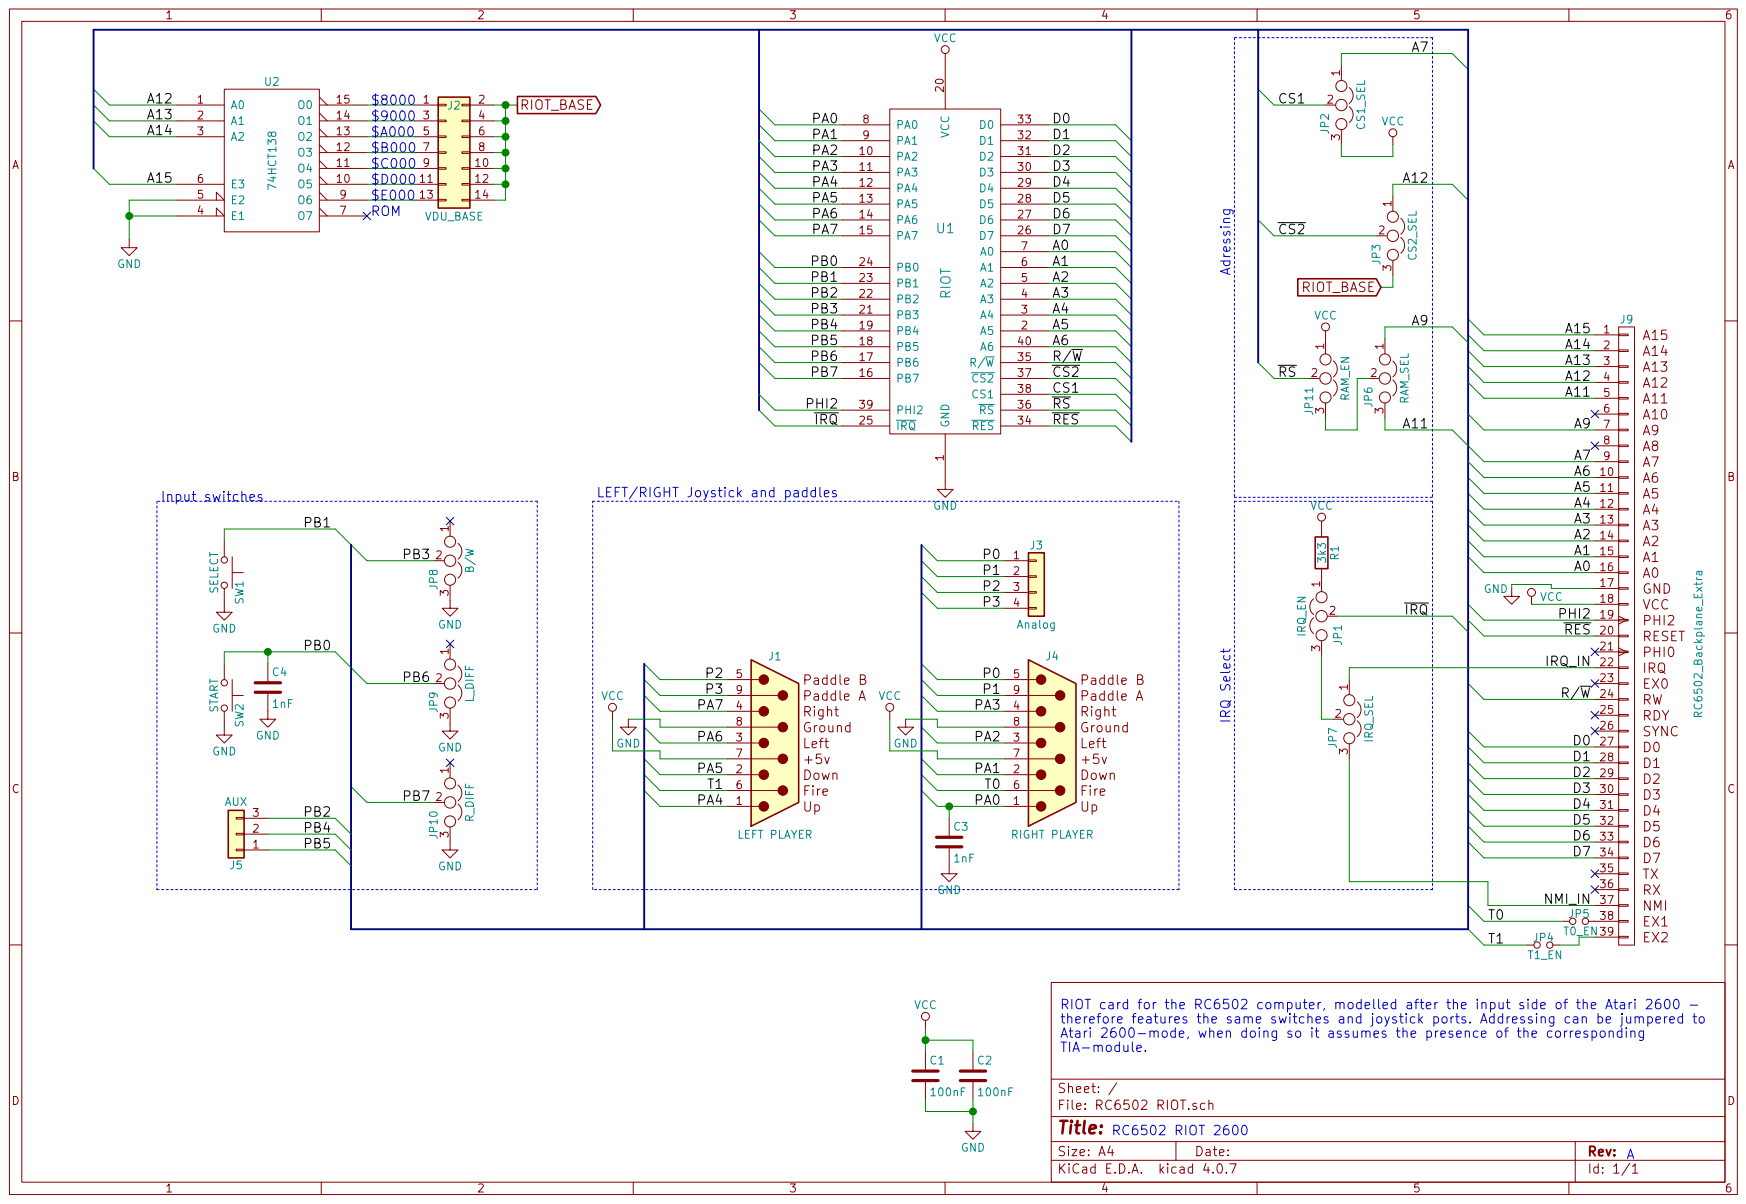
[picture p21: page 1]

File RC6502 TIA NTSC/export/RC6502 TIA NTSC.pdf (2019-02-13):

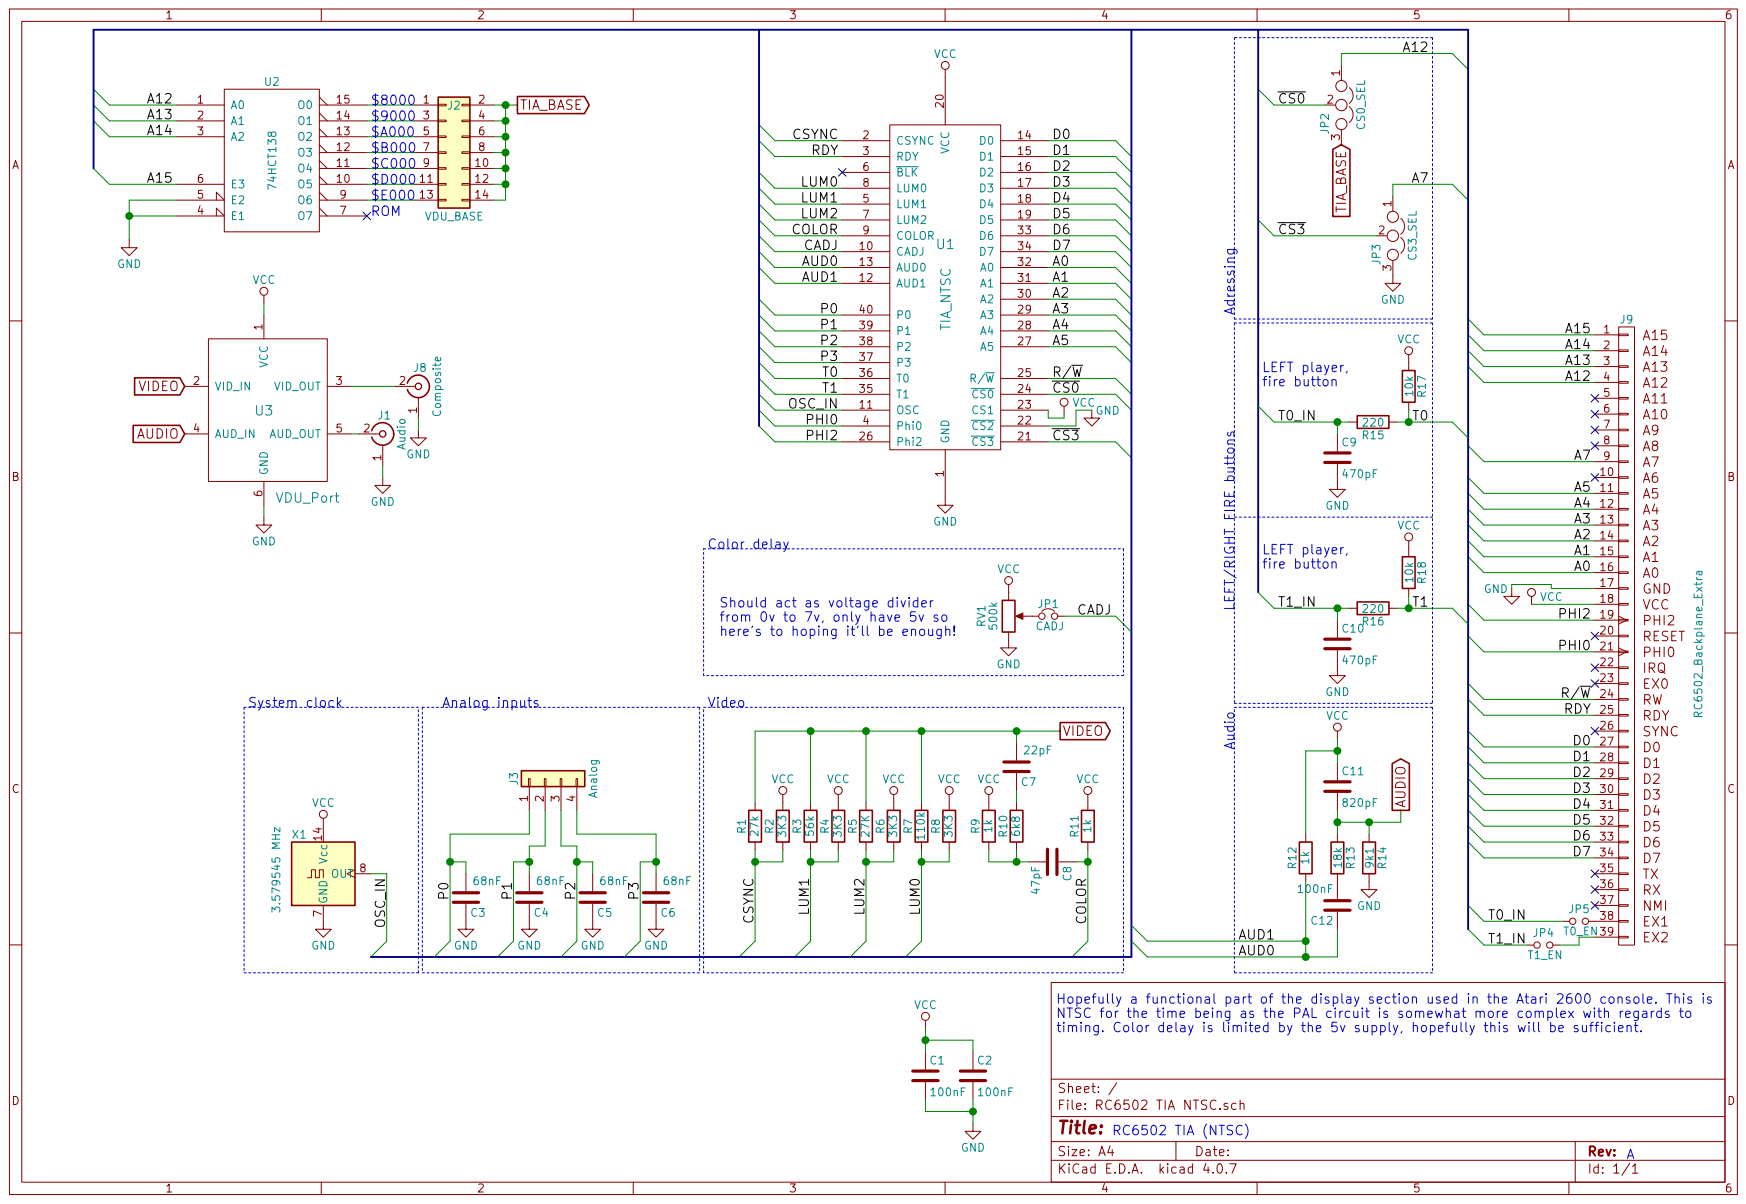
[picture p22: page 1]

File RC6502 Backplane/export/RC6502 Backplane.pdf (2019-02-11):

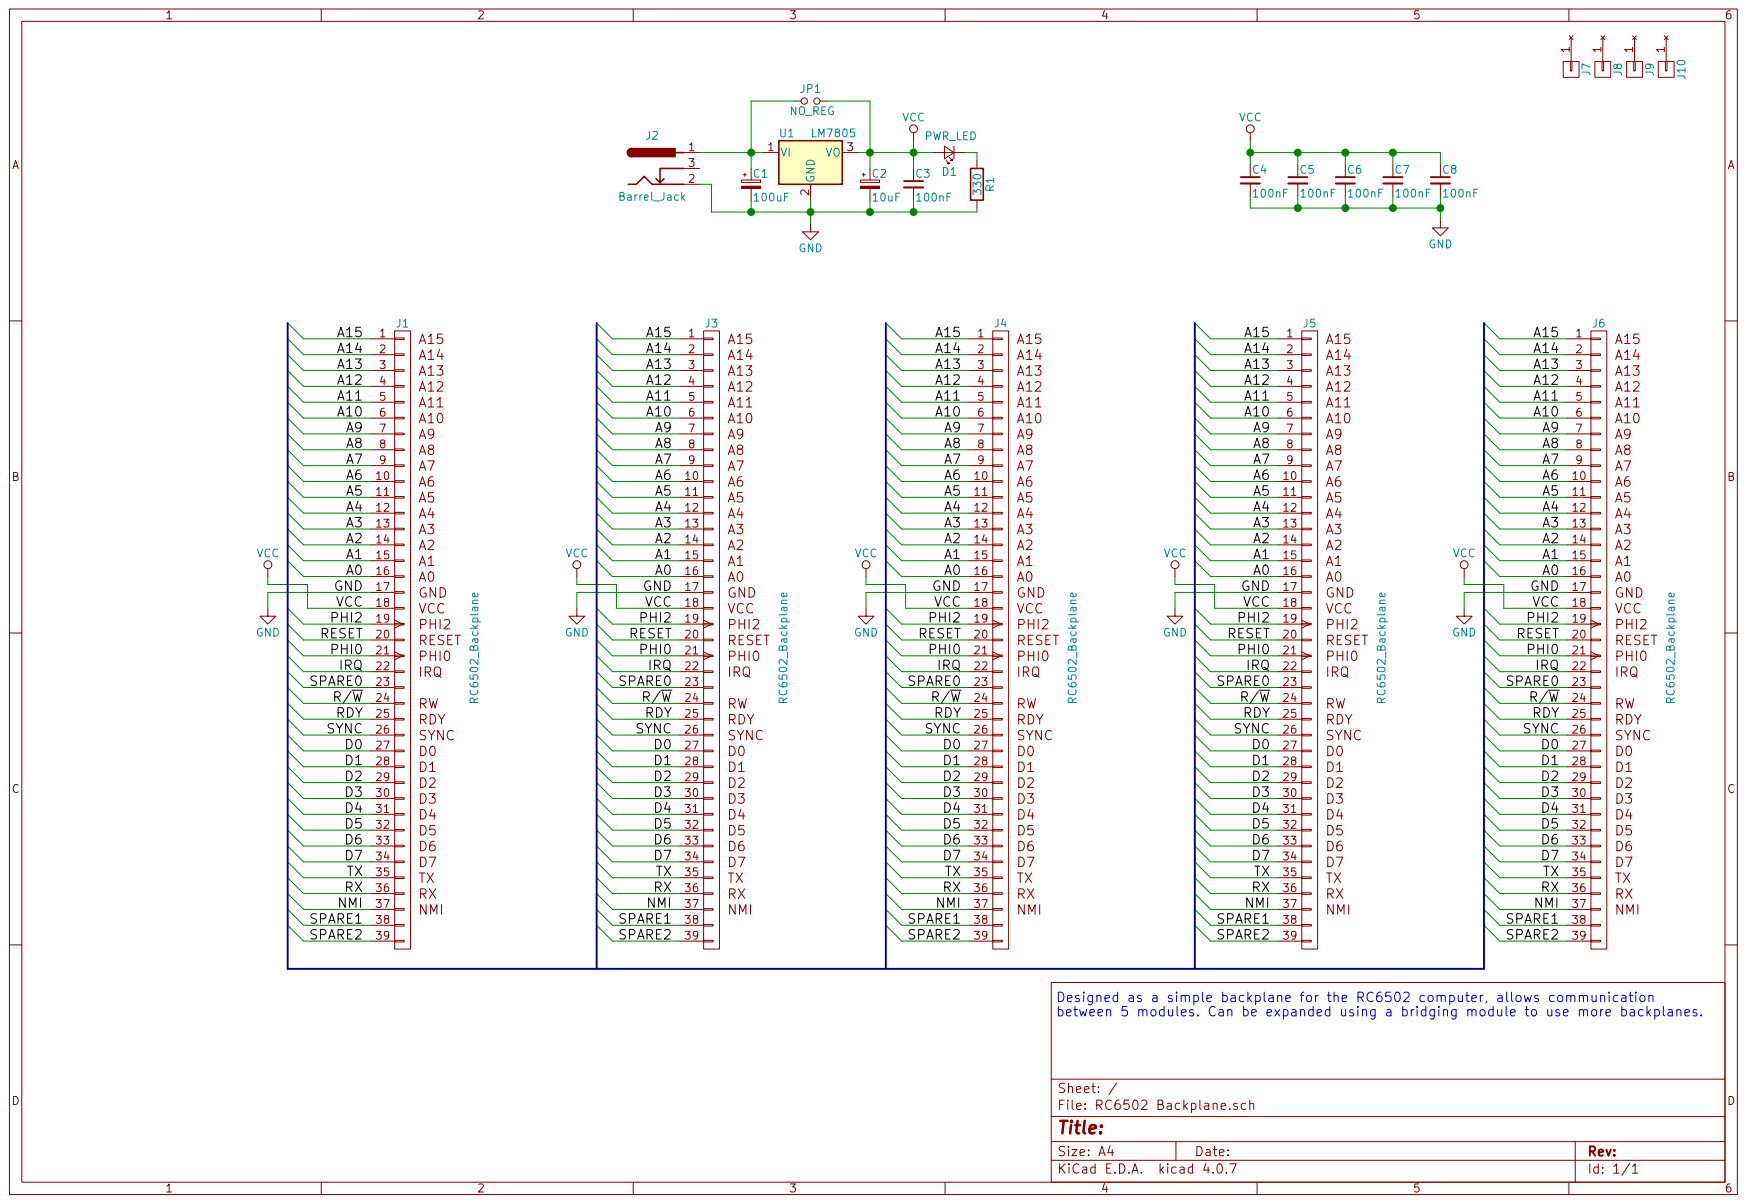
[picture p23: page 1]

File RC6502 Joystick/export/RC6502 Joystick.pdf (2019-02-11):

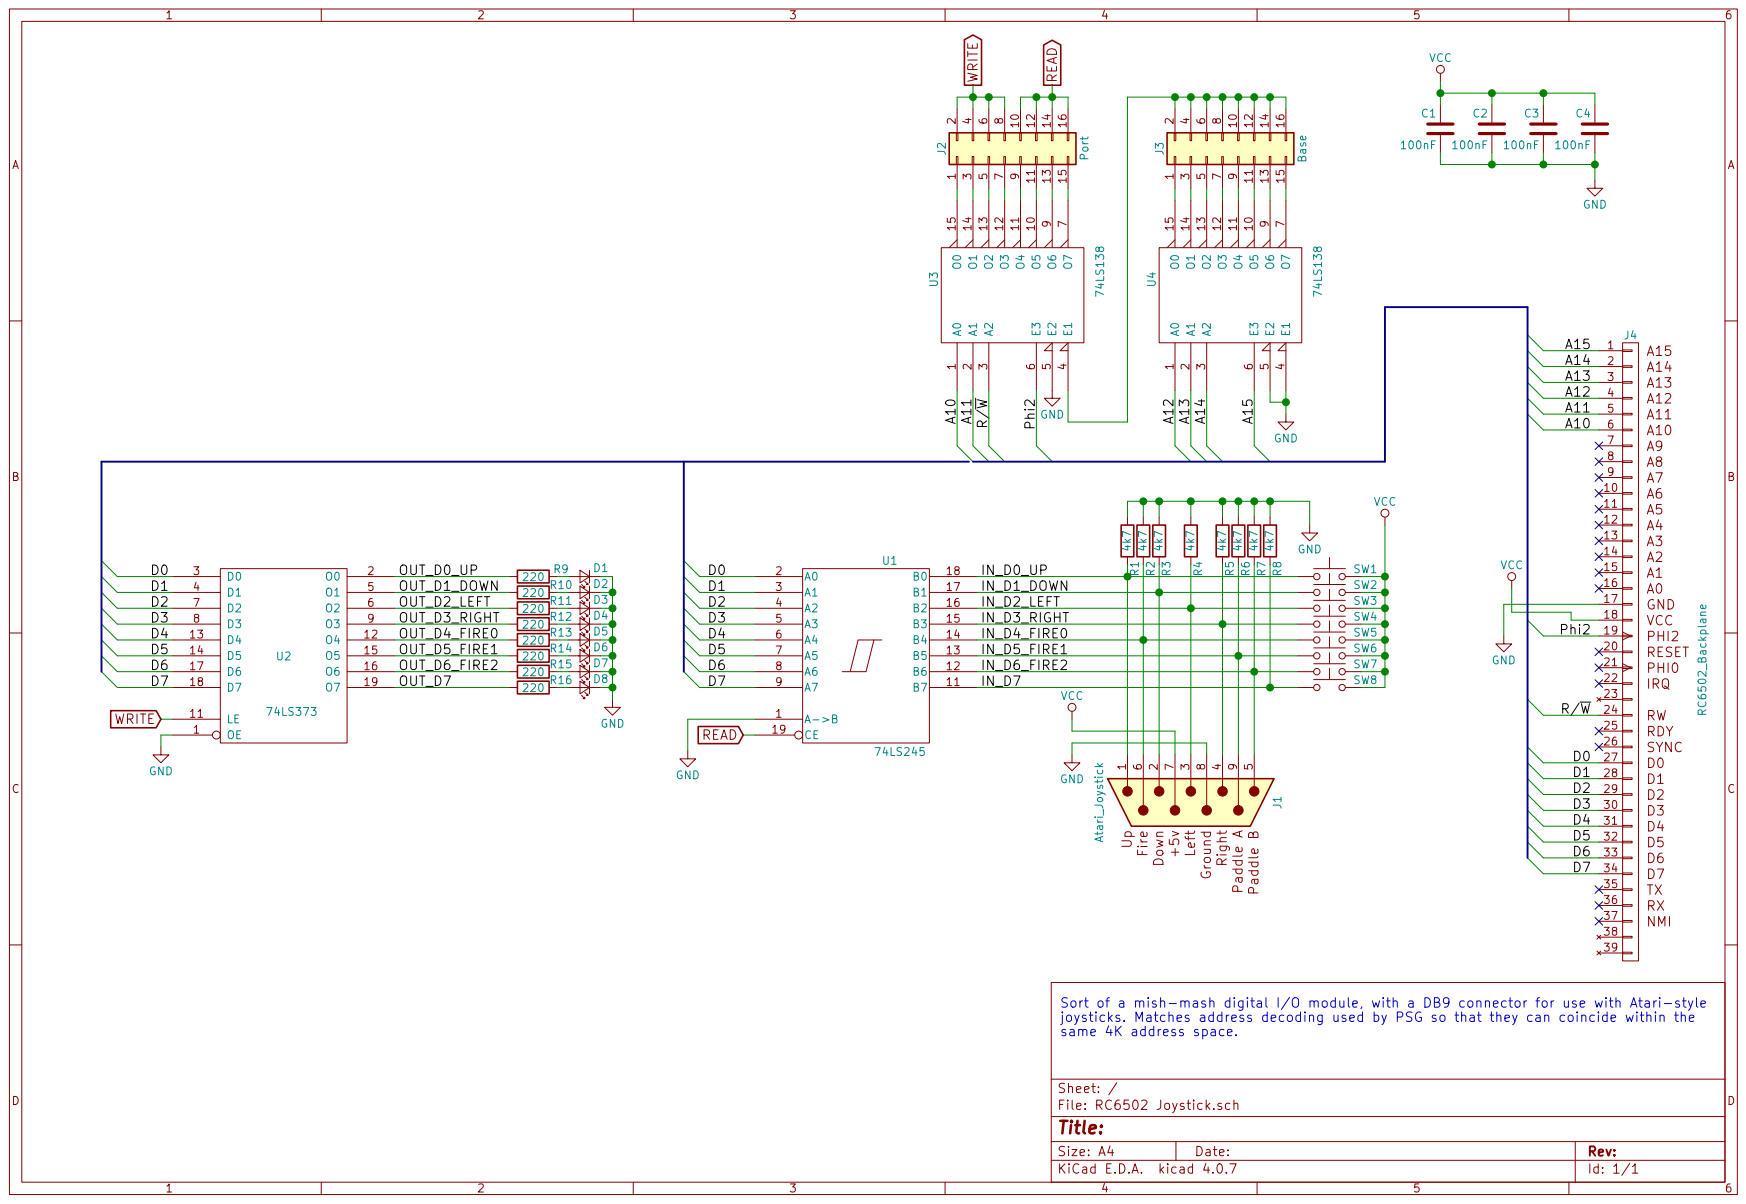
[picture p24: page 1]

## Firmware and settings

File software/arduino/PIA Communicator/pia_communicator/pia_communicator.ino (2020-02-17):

#include <Arduino.h>
#include <MCP23S17.h>
#include <SPI.h>

#define DEBUG 0
#define KBD_INTERRUPT_ENABLE true
#define KBD_SEND_TIMEOUT 23

#define IO_SS 10

#define IO_VIDEO 0
#define IO_VIDEO_D0 0
#define IO_VIDEO_D6 6
#define VIDEO_RDA 5
#define VIDEO_DA 3

#define IO_KBD 1
#define IO_KBD_D0 8
#define IO_KBD_D6 14
#define IO_KBD_DA 15
#define KBD_READY 2
#define KBD_STROBE 4

MCP23S17 bridge(&SPI, IO_SS, 0);

void setup() {
  Serial.begin(115200);
  configure_pins();
  configure_bridge();
  output_status();
}

void configure_pins() {
  pinMode(KBD_READY, INPUT);
  pinMode(VIDEO_DA, INPUT);
  pinMode(KBD_STROBE, OUTPUT);
  pinMode(VIDEO_RDA, OUTPUT);
}

void configure_bridge() {
  bridge.begin();

  /* Configure video section */
  for (int i = IO_VIDEO_D0; i <= IO_VIDEO_D6; i++) {
    bridge.pinMode(i, INPUT);
  }
  bridge.pinMode(7, INPUT_PULLUP);

  /* Configure keyboard section */
  for (int i = 8; i <= 15; i++) {
    bridge.pinMode(i, OUTPUT);
  }
}

void output_status() {
  Serial.println("RC6502 Apple 1 Replica");
  
  debug_value("Video DA", digitalRead(VIDEO_DA));
  debug_value("Video D0-D6", bridge.readPort(IO_VIDEO) & 127);
  debug_value("Keyboard RDY", digitalRead(KBD_READY));
}

void debug_value(String description, byte value) {
  debug_value(description, value, 1);
}

void debug_value(String description, byte value, int level) {
  if (DEBUG < level) return;
  Serial.print(description);
  Serial.print(": ");
  print_hex(value);
}

void print_hex(byte value) {
  print_hex(value, true);
}

void print_hex(byte value, bool newline) {
  if (value <= 0xF) {
    Serial.print("0x0");
  } else {
    Serial.print("0x");
  }
  
  if (newline) Serial.println(value, HEX);
  else Serial.print(value, HEX);
}

void serial_receive() {
  if (Serial.available() > 0) {
    int c = Serial.read();
    debug_value("PIA RX", c, 10);
    pia_send(c);
  }
}

void pia_send(int c) {
  /* Make sure STROBE signal is off */
  digitalWrite(KBD_STROBE, LOW);
  c = map_to_ascii(c);

  /* Output the actual keys as long as it's supported */
  if (c < 96) {
    bridge.writePort(IO_KBD, c | 128);

    digitalWrite(KBD_STROBE, HIGH);
    if (KBD_INTERRUPT_ENABLE) {
      byte timeout;

      /* Wait for KBD_READY (CA2) to go HIGH */
      timeout = KBD_SEND_TIMEOUT;
      while(digitalRead(KBD_READY) != HIGH) {
        delay(1);
        if (timeout == 0) break;
        else timeout--;
      }
      digitalWrite(KBD_STROBE, LOW);

      /* Wait for KBD_READY (CA2) to go LOW */
      timeout = KBD_SEND_TIMEOUT;
      while(digitalRead(KBD_READY) != LOW) {
        delay(1);
        if (timeout == 0) break;
        else timeout--;
      }
    } else {
      delay(KBD_SEND_TIMEOUT);
      digitalWrite(KBD_STROBE, LOW);
    }
  }
}

char map_to_ascii(int c) {
  /* Convert ESC key */
  if (c == 203) {
    c = 27;
  }

  /* Ctrl A-Z */
  if (c > 576 && c < 603) {
    c -= 576;
  }

  /* Convert lowercase keys to UPPERCASE */
  if (c > 96 && c < 123) {
    c -= 32;
  }
  
  return c;
}

void serial_transmit() {
  digitalWrite(VIDEO_RDA, HIGH);

  if (digitalRead(VIDEO_DA) == HIGH) {
    char c = bridge.readPort(IO_VIDEO) & 127;
    debug_value("PIA TX", c, 10);
    digitalWrite(VIDEO_RDA, LOW);

    delay(12);
    send_ascii(c);
  }
}

void send_ascii(char c) {
  if (DEBUG >= 5) Serial.print("[");
  switch (c) {
    case 0x0d: Serial.println(); /* Replace CR with LF */
    default:
      Serial.print(c);
  }
  if (DEBUG >= 5) Serial.print("]");
}

void loop() {
  serial_receive();
  serial_transmit();
}

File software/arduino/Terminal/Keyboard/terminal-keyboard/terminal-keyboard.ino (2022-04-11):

#include <Arduino.h>
#include <PS2KeyAdvanced.h>
#include <PS2KeyMap.h>

#define PS2_CLK  2
#define PS2_DATA 3
#define KBD_LED 10

PS2KeyAdvanced keyboard;
PS2KeyMap keymap;

uint16_t keycode;
uint8_t found;

void setup() {
  pinMode(KBD_LED, OUTPUT);

  keyboard.begin(PS2_DATA, PS2_CLK);
  Serial.begin(115200);
  Serial.println("PS2 Advanced Key Simple Test:");

  // Disable Break codes (key release) from PS2KeyAdvanced
  keyboard.setNoBreak(1);
  // and set no repeat on CTRL, ALT, SHIFT, GUI while outputting
  keyboard.setNoRepeat(1);
  keyboard.setLock(PS2_LOCK_NUM);
  keymap.selectMap((char *)"US");
}

bool remap_character() {
  keycode = keymap.remapKey(keycode);

  if ((keycode < 128) & (keycode > 0)) {
    return true;
  }
  return false;
}

void loop() {
  /* Add 20ms per character delay and 200ms end of line delay, to allow
   * Apple 1 computer to catch up with input.
   */
  // digitalWrite(KBD_LED, HIGH);
  // delay(2000);
  // digitalWrite(KBD_LED, LOW);
  // delay(2000);
  if(keyboard.available()) {
    // read the next key
    keycode = keyboard.read();
    if (remap_character()) {
      Serial.print((char) (keycode & 0x7f));
    }
     
    // if( keycode > 0 ) {
      // Serial.print( "Value " );
      // Serial.print( keycode, HEX );
      // Serial.print( " - Status Bits " );
      // Serial.print( keycode >> 8, HEX );
      // Serial.print( "  Code " );
      // Serial.println( keycode & 0xFF, HEX );
    // }
  }
}

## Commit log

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2017-05-14 Added oscillator to CPU board
    [RC6502 CPU.kicad_pcb, RC6502 CPU.sch]
2017-05-15 Moved SPI breakout connector
    [RC6502 ROM.kicad_pcb]
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2017-05-29 Added jumper select to decide if paging hardware installed
    [RC6502 ROM.kicad_pcb, RC6502 ROM.sch]
2017-05-29 Non-functional version of serial communications
    [RC6502 Serial IO.sch]
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2017-06-01 Pullups changed to 3.3K and added VP jumper
    [RC6502 CPU.sch]
2017-06-01 Put RDY and Sync on the bus
    [RC6502 CPU.sch]
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2017-06-01 Use KBD interrupt to detect when computer has read character sent (Arduino doesn't support flow control in other direction)
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2017-06-01 Moved ATTiny Clock exported files
    [ATTiny Clock-B.Cu.gbr, ATTiny Clock-B.Mask.gbr, ATTiny Clock-B.SilkS.gbr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]
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2017-06-08 Serial IO Revision B
    [RC6502 Serial IO.kicad_pcb, RC6502 Serial IO.sch]
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2017-06-09 ROM revision B
    JP5 inside U3 footprint is used to designate wether paging hardware is installed or not (skip C3 and U3).
    [RC6502 ROM.kicad_pcb, RC6502 ROM.sch]
2017-06-09 Moved JP5 pins to back of board, only want to solder wire across it and not actually mount pins.
    [RC6502 ROM.kicad_pcb]
2017-06-09 CPU revision B
    VP pin was added for W65c02, added SYNC and RDY pins and removed hex inverter.
    [RC6502 CPU-B.Cu.gbl, RC6502 CPU-B.Mask.gbs, RC6502 CPU-B.Paste.gbp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]
2017-06-10 RAM revision B
    Fixed silkscreen notes by swapping high/low text, moved around tracks to make it a little more compact.
    [RC6502 RAM-B.Cu.gbl, RC6502 RAM-B.Mask.gbs, RC6502 RAM-B.Paste.gbp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]
2017-06-10 Reset circuit revision B
    Fixed floating inputs on hex inverter (needed when using HCT), added 74HCT74 in order to allow clock division by 2 and 4 (in case missing matching TTL quartz crystal or want even slower clock than stock).
    [Reset circuit-B.Cu.gbl, Reset circuit-B.Mask.gbs, Reset circuit-B.Paste.gbp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]
2017-06-10 Added SPI breakout details to silkscreen
    [RC6502 Serial IO-B.Cu.gbl, RC6502 Serial IO-B.Mask.gbs, RC6502 Serial IO-B.Paste.gbp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]
2017-06-11 Hide diode name (only one anyways)
    [Reset circuit.kicad_pcb]
2017-06-11 Video Adapter revision B
    Adds IO expanders for possibly offloading the actual image output rendering to an analog module via a separate connector.
    [RC6502 Video Adapter-B.Cu.gbl, RC6502 Video Adapter-B.Mask.gbs, RC6502 Video Adapter-B.Paste.gbp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]
2017-06-11 Fixed video adapter rca connector footprint.
    [RC6502 Video Adapter-B.Cu.gbl, RC6502 Video Adapter-B.Mask.gbs, RC6502 Video Adapter-B.Paste.gbp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]
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2017-06-15 Connected RDY to the wrong pin. Ooops!
    [RC6502 CPU-B.Cu.gbl, RC6502 CPU-B.Mask.gbs, RC6502 CPU-B.Paste.gbp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]
2017-06-15 Created simple backplane connector template
    Need to use this since KiCAD seems unable to copy between sheets.
    [RC6502 Connector.kicad_pcb, RC6502 Connector.sch]
2017-06-15 Updated Gerber exports before sending to manufacturing
    [RC6502 Serial IO-B.Cu.gbl, RC6502 Serial IO-B.Mask.gbs, RC6502 Serial IO-B.Paste.gbp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]
2017-06-15 SBC PCB layout completed
    [RC6502 Apple 1 SBC.kicad_pcb, RC6502 Apple 1 SBC.sch]
2017-06-15 Added ROM reference to SBC
    [RC6502 Apple 1 SBC.kicad_pcb, RC6502 Apple 1 SBC.sch]
2017-06-15 Added silkscreen newbie hints.
    [RC6502 Apple 1 SBC.kicad_pcb]
2017-06-15 Added VP GND details to silkscreen.
    [RC6502 Apple 1 SBC-B.Cu.gbl, RC6502 Apple 1 SBC-B.Mask.gbs, RC6502 Apple 1 SBC-B.Paste.gbp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]
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2017-06-17 Yeah, I'm not going to get this within 10x10cm :-(
    [RC6502 General Video Adapter.kicad_pcb, RC6502 General Video Adapter.sch]
2017-06-17 Exported files with updated silkscreen
    [RC6502 Apple 1 SBC-B.Cu.gbl, RC6502 Apple 1 SBC-B.Mask.gbs, RC6502 Apple 1 SBC-B.Paste.gbp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]
2017-06-19 Updated exports before sending to fabrication.
    [RC6502 Apple 1 SBC-B.Cu.gbl, RC6502 Apple 1 SBC-B.Mask.gbs, RC6502 Apple 1 SBC-B.Paste.gbp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]
2017-07-09 SBC Revision B
    Revision A still don't work with W65c02 processors, added BE signal pull-up (untested wether this improves 65c02 compatibility).
    [RC6502 Apple 1 SBC-B.Cu.gbl, RC6502 Apple 1 SBC-B.Mask.gbs, RC6502 Apple 1 SBC-B.Paste.gbp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]
2017-07-12 Moved oscillator right way up.
    [RC6502 Apple 1 SBC.kicad_pcb]
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2018-12-02 VDU basic IO mapping start
    [RC6502 VDU.kicad_pcb, RC6502 VDU.sch, Reset circuit.sch]
2018-12-04 Digital logic added to schematic
    [RC6502 VDU.sch]
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2018-12-04 Fixed footprint error
    [RC6502 VDU.kicad_pcb, RC6502 VDU.sch]
2018-12-04 Forced KiCad to actually use GND as ground name
    [RC6502 VDU.kicad_pcb, RC6502 VDU.sch]
2018-12-19 Moved incomplete add-on cards to abandoned.
    [ATTiny Clock-B.Cu.gbr, ATTiny Clock-B.Mask.gbr, ATTiny Clock-B.SilkS.gbr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]
2018-12-21 Schematic done for enhanced RAM/ROM board
    [RC6502 RAM.sch]
2018-12-22 Enhanced RAM/ROM board, routing done
    [RC6502 RAM.kicad_pcb, RC6502 RAM.sch]
2018-12-23 Flipped decoder inputs, added details to silkscreen.
    [RC6502 RAM-B.Cu.gbl, RC6502 RAM-B.Mask.gbs, RC6502 RAM-B.Paste.gbp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]
2018-12-23 Added schematic for a bus monitor and single stepping card.
    [RC6502 Debug.kicad_pcb, RC6502 Debug.sch]
2018-12-25 Exported schematic to pdf
    [RC6502 Debug.sch]
2018-12-26 PSG sound card schematic added
    [RC6502 PSG.kicad_pcb, RC6502 PSG.sch]
2018-12-28 PSG sound card layout
    [RC6502 PSG.kicad_pcb, RC6502 PSG.sch]
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2018-12-29 Changed VDU CS logic ins schematic
    [RC6502 VDU.kicad_pcb, RC6502 VDU.sch]
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2018-12-30 VDU PCB layout done
    [RC6502 VDU.kicad_pcb, RC6502 VDU.sch]
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2018-12-30 Tried to increase ground plane flow
    [RC6502 VDU.kicad_pcb, RC6502 VDU.sch]
2018-12-31 Exported gerber files for VDU
    [RC6502 VDU-B.Cu.gbl, RC6502 VDU-B.Mask.gbs, RC6502 VDU-B.Paste.gbp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]
2019-01-02 SBC uses new oscillator footprint
    [RC6502 Apple 1 SBC-B.Cu.gbl, RC6502 Apple 1 SBC-B.Mask.gbs, RC6502 Apple 1 SBC-B.Paste.gbp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]
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2019-01-12 VDU amplifier schematic done
    [RC6502 VDU Amplifier.kicad_pcb, RC6502 VDU Amplifier.sch]
2019-01-12 VDU amplifier layout done
    [RC6502 VDU Amplifier-B.Cu.gbl, RC6502 VDU Amplifier-B.Mask.gbs, RC6502 VDU Amplifier-B.Paste.gbp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]
2019-01-13 Added resistor values to SBC silkscreen
    [RC6502 Apple 1 SBC.kicad_pcb]
2019-01-13 Added ROM enable jumper to SBC
    [RC6502 Apple 1 SBC.kicad_pcb, RC6502 Apple 1 SBC.sch]
2019-01-13 Added RAM enable jumper to SBC
    [RC6502 Apple 1 SBC-B.Cu.gbl, RC6502 Apple 1 SBC-B.Mask.gbs, RC6502 Apple 1 SBC-B.Paste.gbp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]
2019-01-14 Changed schematic symbol for capacitor on serial output line
    [RC6502 Apple 1 SBC.sch, RC6502 Serial IO.sch]
2019-01-14 Fixed typo, added BOM notes.
2019-01-14 Added reset circuit README
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2019-02-09 Added oscillator enable jumper to SBC
    [RC6502 Apple 1 SBC-B.Cu.gbl, RC6502 Apple 1 SBC-B.Mask.gbs, RC6502 Apple 1 SBC-B.Paste.gbp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]
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2019-02-16 Fixed RAM board block select logic
    [RC6502 RAM-B.Cu.gbl, RC6502 RAM-B.Mask.gbs, RC6502 RAM-B.Paste.gbp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]
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2019-02-20 Updated VDU schematic with rev. B fixes
    [RC6502 VDU.sch]
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2019-02-24 SBC revision E was missing VCC to CPU for some reason
    [RC6502 Apple 1 SBC-B.Cu.gbl, RC6502 Apple 1 SBC-B.Mask.gbs, RC6502 Apple 1 SBC-B.Paste.gbp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]
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2019-06-24 Debug module schematic reworked
    [RC6502 Debug.sch]
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2020-01-25 Serial adapter abandoned (moved to RC-ONE and completed)
    [RC6502 Serial Adapter.kicad_pcb, RC6502 Serial Adapter.sch]
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2021-06-03 Update BOM table, PCB link, and jumper settings
    Added a variety of additional information and fixups, to the BOM table especially:
    * added some missing jumpers (JP1/J11/A13_W/A14_w)
    * jumpers were unclear outside of KiCad, added "silkscreen" column with notes
    * also added a "socket" column for parts if want to buy narrow/wide holder for any chips
    * some jumpers incorrectly had "right angle" listed where straight header needed
    * the PCBWay link was broken, updated to revH
2021-12-07 SBC/README: Fix backwards description of the VP GND jumper
    Issue #29 from ea4eoz noted that this is backwards for the revision H
    board. It's clearly must be backwards for _every_ revision, since
    closing a jumper, rather than opening it, is the way to connect the
    other side of the jumper to ground.
    (This error was inserted by me when I originally wrote this section
    of the documentation.)
2021-12-07 SBC/README: RAM_EN jumper is vertical on newer versions of the board
    Issue #29 from ea4eoz noted this, and I've confirmed myself that the latest
    revision as of this commit (e395f27) has moved the jumper to a vertical
    orientation with the lowest pin connected to Vcc.
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
